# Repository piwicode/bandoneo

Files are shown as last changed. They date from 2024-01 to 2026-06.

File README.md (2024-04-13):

# Bandoneon MIDI

The goal of this DIY project is to build a
[bandoneaon](https://en.wikipedia.org/wiki/Bandoneon) MIDI keyboard with
velocity.

# First steps with the microcontroler

_2024/01/18_

Microcontroler development board are a huge time saver. Adafruit has a serie of
small form factor called [Feathers](https://www.adafruit.com/category/946)

These boards can be powered via USB or battery and utilize a voltage regulator
to maintain a 3.3V operation.

[Adafruit Feather M4 Express](https://learn.adafruit.com/adafruit-feather-m4-express-atsamd51)
is built around the
[ATSAMD51J19A](datasheets\SAM-D5x-E5x-Family-Data-Sheet-DS60001507.pdf). It look
like excellent choice because:

- it has plenty (21) input-output pins
- it runs at high clock speed of 120 MHz which will make possible
  [bitbang](https://en.wikipedia.org/wiki/Bit_banging) many analog-to-digital
  SPI busses at 3.6 MHz. I also have 32 floating point hardware.
- it has a single core which keeps the temptation to write concurent code away
- it does not have any extraneous wireless features.

The first thing to do it to check the bootloader version.

The bootloader, the initial program running on the processor, resides at the
start of the embedded flash, mapped at address `0x0` (See
`9.2 Physical Memory Map` and `25.6.2 Memory Organization`). Typically compact,
its role is to load and initiate the main program. In microcontrollers, it also
facilitates updating the main program.

Adafruit employs a
[fork of Microsoft UF2 bootloader](https://github.com/adafruit/uf2-samdx1),
which implements the Mass Storage Class. This means the board appears as a drive
when connected via USB. The term 'UF2' refers to a file format containing
instructions for rewriting device memory. The file format specifies a series of
memory addresses and the content to be written there. By following this process,
the program can be replaced by overwriting the memory, a straightforward method
requiring no extra hardware.

While both CircuitPython and Arduino workflows are well-documented, I will avoid
using CircuitPython to prevent the garbage collector from introducing jitter
into my time series sampling.

Thanks to Adafruit and Arduino's excellent work, the integration of drivers and
boards in the IDE is flawless. It took two attempts to flash the device, but now
the board's LED is blinking. Hello world!

# Emmiting Midi signals

_2024/01/19_

Musical Instrument Digital Interface, better known as MIDI, is a communication
protocol used for transmitting musical notes over a serial interface. These
notes are received by a synthesizer, which then produces the corresponding
waveforms.

There are two hardware solutions: 5 pin
[DIN connector](https://fr.wikipedia.org/wiki/Connecteur_DIN) or USB Midi.

## Midi via 5 pin DIN

The
[electrical specifications for the 5-pin DIN MIDI](datasheets\MCP3004-MCP3008-Data-Sheet-DS20001295.pdf),
reveal that it utilizes a UART serial bus along with power. Fortunately, most
modern microcontrollers now support UART.

Out of the five wires, only four are used: these are for Ground (GND), 3.3 volts
(3V3), UART receive (RX), and UART transmit (TX).

[UART (Universal Asynchronous Receiver-Transmitter)](https://en.wikipedia.org/wiki/Universal_asynchronous_receiver-transmitter)
is an efficient serial communication protocol that uses just two wires: TX
(transmit) and RX (receive). Without a dedicated clock signal, devices
synchronize based on the transmitted signal itself. To ensure reliable
communication, parity bits are also transmitted.

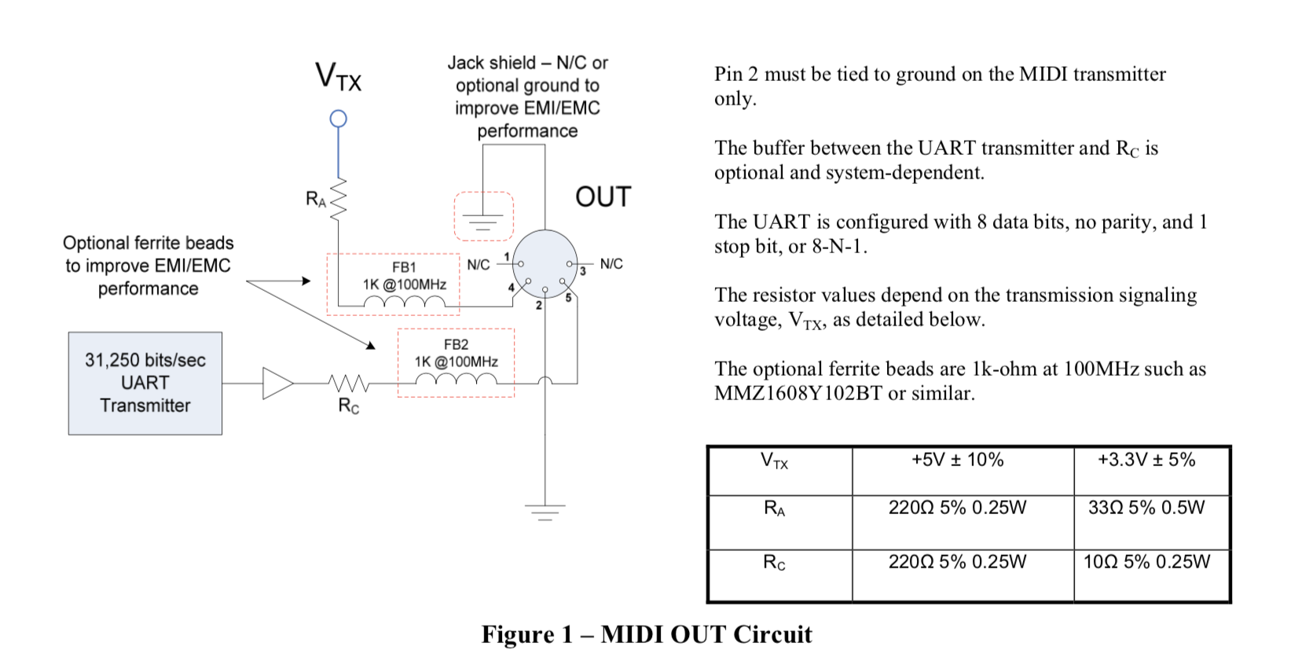
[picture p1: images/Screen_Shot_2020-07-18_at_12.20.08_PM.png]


The
[Arduino Midi library](https://github.com/FortySevenEffects/arduino_midi_library)
works instantly.

I used
[Adafruit's Midi Featherwing](https://learn.adafruit.com/adafruit-midi-featherwing)
for prototyping and it works like a charm.

## Midi via USB

In this setup, MIDI information travels through the same USB cable that is used
for power, programming, and retrieving logs from the board.

To enable MIDI via USB, you need to use
[TinyUSB](https://docs.tinyusb.org/en/latest/index.html), which can be selected
from the `Tools > USB` Stack menu in the `Arduino IDE`. By default, the USB
driver that is built with the program is ArduinoUSB. TinyUSB allows for the
support of additional protocols and enables the device to function as a MIDI
interface.

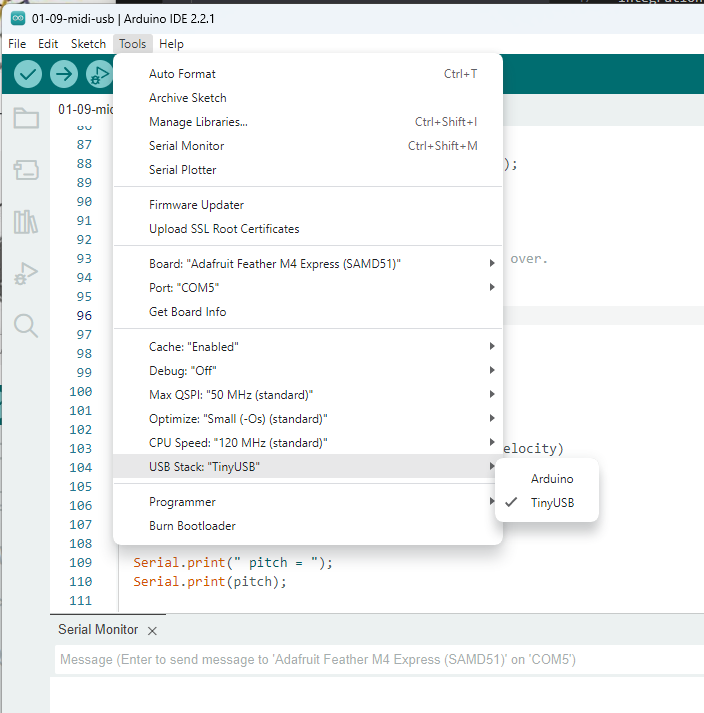
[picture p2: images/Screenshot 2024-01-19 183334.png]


The boards shows up as `Feather M4 Express` in my Digital Audio Workstation and
output midi notes.

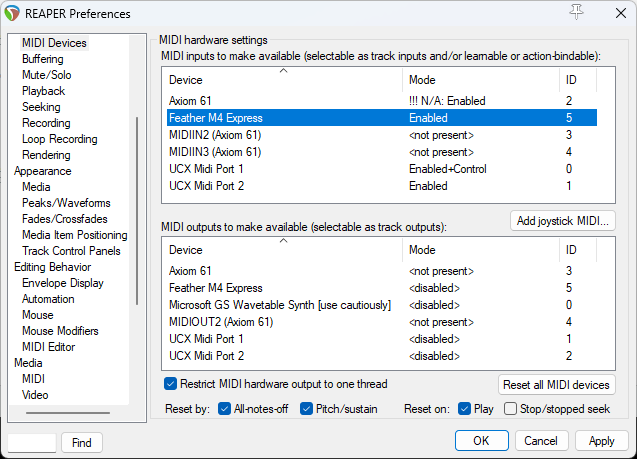
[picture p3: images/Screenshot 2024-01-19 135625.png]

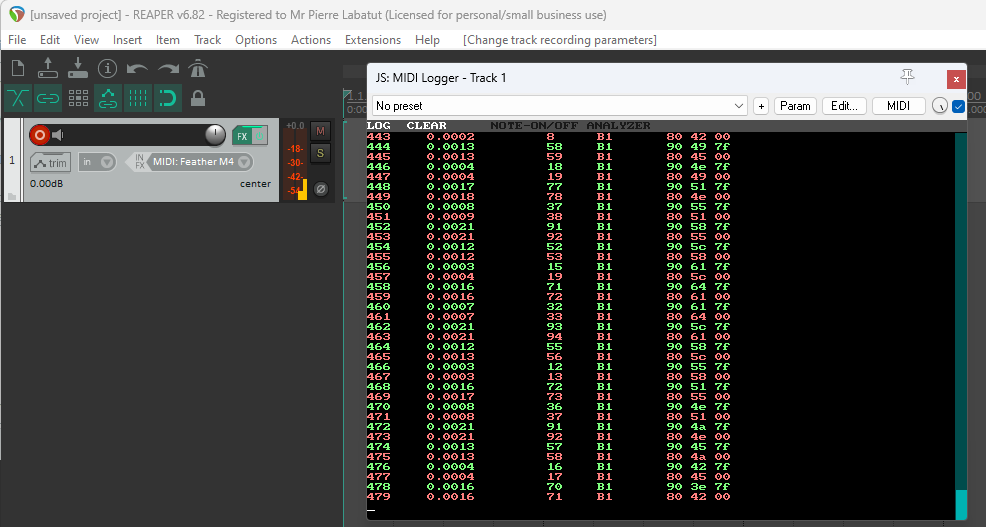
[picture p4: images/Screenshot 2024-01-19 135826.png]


Even with this setup, serial logging still works just fine.

# Talking to the Analog-Digital-Conveter

_2024/01/19_

Analog to Digital Converters, also known as ADCs, measure voltage from a pin and
convert it to numerical data for transmission over a serial bus. Those
components usualy have multiple input channels connected to a unique
[Successive-approximation ADC](https://en.wikipedia.org/wiki/Successive-approximation_ADC)
by a MUX.

I selected the [MCP3008](datasheets\MCP3004-MCP3008-Data-Sheet-DS20001295.pdf)
which looks popular. There is a
[tutorial available on Adafruit](https://learn.adafruit.com/reading-a-analog-in-and-controlling-audio-volume-with-the-raspberry-pi),
and the [midi_hammer](https://github.com/aleathwick/midi_hammer) project has
successfully integrated it with hall sensors to create a keyboard
([demo](https://youtu.be/tgWXtYCHDI4)).

The [MCP3008](datasheets\MCP3004-MCP3008-Data-Sheet-DS20001295.pdf) can measure
voltage from one of its eight inputs and then transmit the result via an SPI
(Serial Peripheral Interface) serial bus. Unlike UART, SPI includes an explicit
clock signal, which means it uses three wires, named:

- Clock
- MOSI (Master output slave input)
- MISO (Master input slave output)

A fourth pin `CS` (Chip Select), is used to activate or deactivate the
peripheral, effectively controlling when it can send or receive data.

The tutorial features Python code, but luckily, Adafruit also offers
[an Arduino library](https://github.com/adafruit/Adafruit_MCP3008), complete
with examples. All I need to do is set the number for the CS pin, and it works
seamlessly.

```c++
adc.begin(13);
```

Again, this is a huge time-saver.

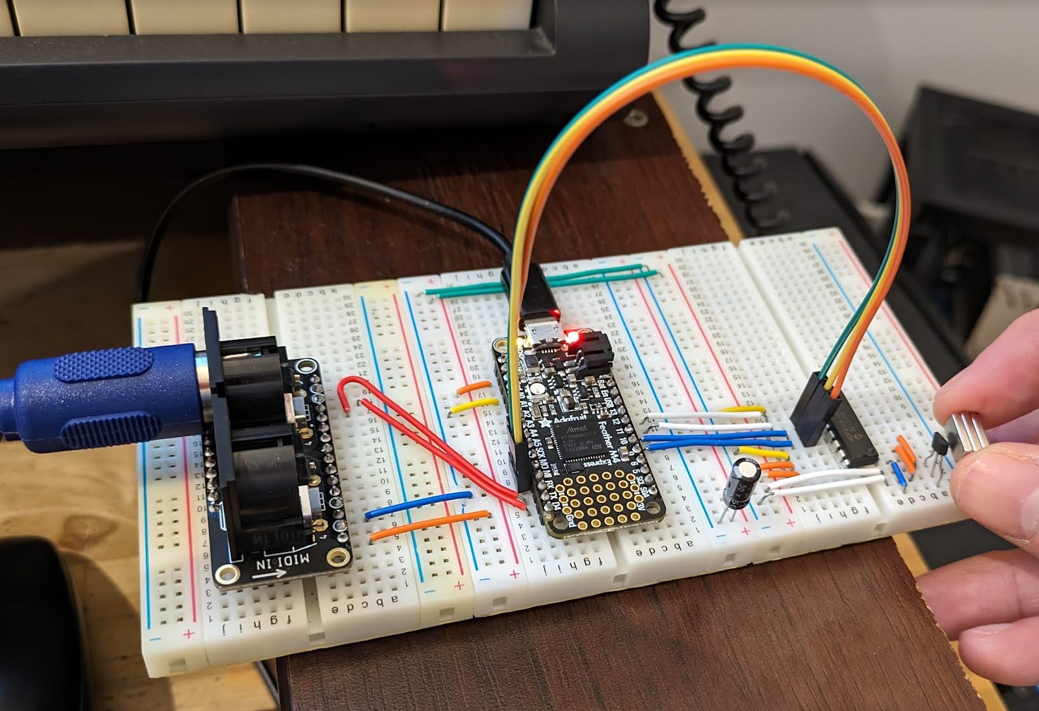
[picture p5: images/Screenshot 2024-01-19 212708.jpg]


I can read the 8 channels:

```
522	0	1023	1	1	0	0	0	[150]
522	0	1023	0	0	0	0	0	[151]
522	0	1023	2	1	0	0	1	[152]
522	0	1023	4	3	3	4	8	[153]
```

- The first channel shows the sensor output. In the absence of magnetic fields,
  it returns a mid-range value. Since the MCP3008 is a 10-bit converter, the
  maximum value is 1023, making 522 close to half of this.
- The second is grounded, and as expected, it reads 0.
- The third channel is connected to 3V3 and shows the maximum reading of 1023.
- When a magnet touches the sensor, the readings vary significantly: I can get a
  value of 788 and, interestingly, 254 when the magnet is rotated 180°.

Interestingly, the
[`Adafruit_MCP3008`](https://github.com/adafruit/Adafruit_MCP3008) library is
built on top of [`Adafruit_BusIO`](https://github.com/adafruit/Adafruit_BusIO)
which abstracts SPI communication. This is particularly useful because it can
implement a software bus, exactly what I need for reading from multiple
`MCP3008` units.

The
[library source code](https://github.com/adafruit/Adafruit_BusIO/blob/master/Adafruit_SPIDevice.cpp)
demonstrates how to modify multiple outputs of a given port by writing to the
register:

```c++
BusIO_PortReg *mosiPort = (BusIO_PortReg *)portOutputRegister(digitalPinToPort(mosipin));
BusIO_PortMask *mosiPinMask = digitalPinToBitMask(mosipin);

// Write
*mosiPort = *mosiPort | mosiPinMask;
```

This technique will be useful for reading measurements from multiple devices
simultaneously.

However, the approach to frequency control appears quite basic. It simply sleeps
according to the frequency period, without accounting for the time taken by
operations.

```c++
int bitdelay_us = (1000000 / _freq) / 2;
delayMicroseconds(bitdelay_us);
```

I configured the library to use
[bit banging](https://en.wikipedia.org/wiki/Bit_banging) for the bus by
specifying each pin:

```c++
 adc.begin(10, 12, 11, 13);
```

Remarkably, this setup worked perfectly on the first try.

It runs at `65300 sps` (samples per second), which is half of the specified
throughtput at 3.3 V.

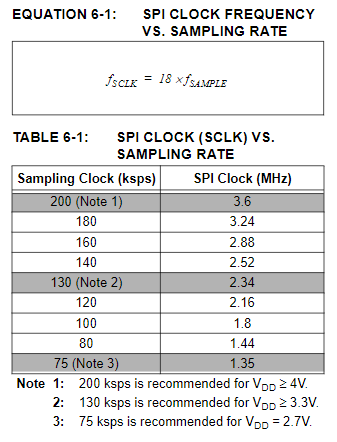
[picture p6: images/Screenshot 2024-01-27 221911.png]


# Bit-banging first step

_2024/01/21_

The source code below implements software SPI. It writes the content of `wbuf`
to the bus while simultaneously reading into `rbuf`. This approach is inspired
by Adafruit's implementation.

```c++
  template <unsigned int L>
  void transfer(const std::array<uint8_t, L> &wbuf,
                std::array<uint8_t, L> &rbuf) {
    // Only MSB first is supported.
    int r_idx = 0;
    for (const uint8_t wbyte : wbuf) {
      uint8_t rbyte;
      for (uint8_t bit = 0x80; bit != 0; bit >>= 1) {
        digitalWrite(mosi_, (wbyte & bit) != 0);
        digitalWrite(clk_, HIGH);
        delayMicroseconds(clk_period_us_);
        rbyte = (rbyte << 1) | digitalRead(miso_[i]);

        digitalWrite(clk_, LOW);
        delayMicroseconds(clk_period_us_);
      }
      rbuf[r_idx++] = rbyte[i];
    }
  }
```

The ADC protocol uses 17 bus clocks cycle to get a measure.

<table>
  <tr>
   <td>
   </td>
   <td><strong>Bits</strong>
   </td>
   <td><strong>MOSI</strong>
   </td>
   <td><strong>MISO</strong>
   </td>
  </tr>
  <tr>
   <td>Start bit
   </td>
   <td>1
   </td>
   <td>“1”
   </td>
   <td>don’t care
   </td>
  </tr>
  <tr>
   <td>Single / Diff
   </td>
   <td>1
   </td>
   <td>“1”
   </td>
   <td>don’t care
   </td>
  </tr>
  <tr>
   <td>Channel select
   </td>
   <td>3
   </td>
   <td>D0, D1, D2
   </td>
   <td>don’t care
   </td>
  </tr>
  <tr>
   <td>Sample Period
   </td>
   <td>1
   </td>
   <td>don’t care
   </td>
   <td>don’t care
   </td>
  </tr>
  <tr>
   <td>Null bit
   </td>
   <td>1
   </td>
   <td>don’t care
   </td>
   <td>“0”
   </td>
  </tr>
  <tr>
   <td>Sample
   </td>
   <td>10
   </td>
   <td>don’t care
   </td>
   <td>data
   </td>
  </tr>
</table>

Your analysis of the code's performance and potential improvements is
insightful. Here's a slightly restructured version for enhanced clarity and
conciseness:

This code currently runs at `11.48 ksps`` (kilosamples per second), which
translates to 87 μs (microseconds) per sample. However, there's room for
improvement. According to the MCP3008 datasheet, it can achieve up to 130 ksps
at 3.3V. Here are some potential optimization strategies:

- The most accurate delay function available is delayMicroseconds, but it limits
  the SPI bus to a maximum of 500 KHz. To reach the desired 120 ksps, a bus
  speed of 2.16 MHz is required.
- The current codes transmits 3 bytes (24 bit) per sample, wheras the minimal is
  17 bits, which is 30% more than needed.
- The existing delays don't account for the latency of operations between the
  delays, which adds to the total delay time.
- Using port registers to control output instead of digitalWrite could be more
  efficient.
- Adafruit has implemented a fast path for cases where the MOSI pin sends
  consecutive identical values. This bypasses
  `digitalWrite(mosi_, (wbyte & bit) != 0)`. Surprisingly, this optimization
  increases the rate to 12.65 ksps (79 μs per sample), an improvement of 10%,
  which makes me think `digitalWrite` is very slow.

# Precision counter on ATSAMD51J19A

_2023/01/21_

`ATSAMD51J19A`
[Arduino API implementation by Adafruit](https://github.com/adafruit/ArduinoCore-samd/blob/e2b78cbd3608fd5969d50c550a314db913a1a9e9/cores/arduino/delay.c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)
utilizes a hardware cycle counter `CYCCNT` of the `Data Watchpoint and Trace`
(DWT). This method is extremely precise, as the processor clock operates at 120
MHz. It's important to note that the processor clock frequency can be altered,
and the current frequency is accessible through `SystemCoreCloc`k.

```c++
void delayCycles(uint32_t count) {
  // This value takes into account the time spent in the function
  // itself. It has been determined experimentally by comparing the
  // delayCycles() function with the micro().
  constexpr uint32_t experimental_bias = 16;
  const uint32_t start = DWT->CYCCNT - experimental_bias;
  // The DWT->CYCCNT register is a 32 bits counter that counts the
  // number of cycles since the last reset. It is incremented every
  // cycle. It wraps around every 2^32 cycles (~37 secs at 120MHz).
  while (DWT->CYCCNT - start < count) {
  }
}
```

By replacing `delayMicros()` with `delayCycles()`, the sample rate has been
significantly improved to 23.7 ksps, which is an increase of +87%.

It seems that writing values to the port is time consuming. In a benchmark test
using the following code:

```c++
uint32_t start = micros();
for (int i = 0; i < 1000000; i++) {
  digitalWrite(12, HIGH);
  digitalWrite(13, HIGH);
  digitalWrite(12, LOW);
  digitalRead(13);
}
uint32_t end = micros();
// Display the cycle frequency.
Serial.print("Cycle frequency: ");
Serial.print(1000000.0 / (end - start));
Serial.println("MHz");
```

The results indicate a cycle frequency of 0.70 MHz when compiled with the
`-Ofast` optimization and 0.61 MHz with `-Os` (optimize for size). These
performance levels are insufficient for driving the bus at the desired speed of
2.16 MHz. However, controlling the GPIO directly via the port registers
demonstrates a much faster performance.

Direct control of the GPIO via port registers significantly boosts performance.
Consider this code snippet:

```c++
// Get port and mask from pin number.
auto reg = portOutputRegister(digitalPinToPort(12));
auto mask = digitalPinToBitMask(12);
uint32_t start = micros();
for (int i = 0; i < 1000000; i++) {
  *reg |= mask;
}
```

Running this code yields a frequency of 13.31 MHz when compiled with `-Ofast``.
As expected, a lower frequency of 3.64 MHz is observed for four register
updates.

By replacing `digital*` functions with direct pad manipulation, the sample rate
can be increased to an impressive 90.1 ksps. However, there's still room for
further improvement to reach our target.

# Optimize the IO manipulation further

_2024/01/22_

The operation `*ioreg |= mask;` involves reading, modifying, and then writing
back the result, which can be time-consuming. To address this, the
[`ATSAMD51J19A`](datasheets\SAM-D5x-E5x-Family-Data-Sheet-DS60001507.pdf)
features specialized registers that allow for setting or clearing pins directly
by writing a bitmask to them. This functionality significantly streamlines the
process.

To find the specific member names required, I had to delve into the code. On
Windows, this can be located in the following path:
`\Users\$USER\AppData\Local\Arduino15\packages\adafruit\tools\CMSIS-Atmel\1.2.2\CMSIS\Device\ATMEL\samd51\include\instance\port.h`.
This file is part of the CMSIS (Cortex Microcontroller Software Interface
Standard) package provided by Adafruit for the SAMD51 microcontroller.

For reference, in terms of performance:

- The function call digitalWrite(13, HIGH) consumes 41 cycles.
- Direct register manipulation with \*ioreg |= 0x800000 takes only 10 cycles.

Here is a verbose way to access `OUTSET`.

```c++
digitalPinToPort(13)->OUTSET.reg = digitalPinToBitMask(13);
```

This operation runs in 8 cycles. While it's slower compared to direct register
manipulation, this is mainly because the digital\* functions take additional
time to execute. However, these functions return a constant value, which offers
the possibility of caching for improved efficiency.

```c++
auto port = digitalPinToPort(13); // Once for all.

port->OUTSET.reg = 0x800000;
```

This method is significantly faster, completing the operation in just 3 cycles.

```c++
REG_PORT_OUTSET0 = 0x800000
```

This is the most straight forward, and it runs in 3 cycles, which is 3 times
faster than writing to the IO Register an 13 times faster than the
`digitalWrite`! . With this efficient method of controlling IO, the SPI bitbang
speed now reaches 105.96 ksps, which is quite close to the MCP3008 ADC's
specified limit of 120 ksps at 3.3V. However, we have yet to achieve the maximum
possible speed.

I should be able to squeze by rewriting the throttler. Without throttler the bus
runs at 186.96 ksps, and looks to return correct values.

Profiler code can be found
[here](src\arduino\01_18_blink_sodr_test\01_18_blink_sodr_test.ino)

# Optimizing further data write

_2024/01/23_

For the `clock` or `CS`, the code involves either clearing or setting a bit. In
contrast, the MOSI pin requires setting it to correspond with a specific bit of
the data. Here are several methods for handling the MOSI pin, by increasing
efficiency:

```c++
*(mosi_value ? &REG_PORT_OUTSET0 : &REG_PORT_OUTCLR0) = mosi_mask_;
// 6 cycles

REG_PORT_OUT0 = (REG_PORT_OUT0 & ~mosi_mask_) | (mosi_value << mosi_shift_);
// 15 cycles

*(&REG_PORT_OUTCLR0 + mosi_value) = mosi_mask
// 3 cycles
```

With this new method, we're beginning to observe that the code needs to be
throttled. Otherwise, the bus operates at a speed that exceeds the capabilities
of the `MCP3008`.

For the record I also considered
[bit-banding](https://developer.arm.com/documentation/ddi0439/b/Programmers-Model/Bit-banding),
but the featue is not available on the
[`ATSAMD51J19A`](datasheets\SAM-D5x-E5x-Family-Data-Sheet-DS60001507.pdf).

Target is 130 KSPS = 1/130e3/18 = 4.27350427E-7 = 427 ns

# Precise timing

Up until now, we've been handling time control with a simple busy loop. The
catch is that this method isn't super precise because each cycle includes
multiple instructions, and it can only wait for multiples of this cycle
duration.

To make things more accurate, we started using the `__NOP();` instruction. It's
like a little pause button for the processor, letting it wait for just one
cycle. But here's the kicker: getting the timing spot on with this method means
doing some manual tuning. You have to measure the timing precisely, which can be
a bit of a hassle.

One way to do this measurement is by keeping an eye on `DWT->CYCCNT`. But
remember, this approach can be a bit intrusive.

I ordered
[`AZ Delivey Logic Analyzer`](https://www.az-delivery.de/en/products/saleae-logic-analyzer).
It is an innexpensive device able to capture the binary state of 8 channels at
24 MHz, the data is then analyzed with
[Salae Logic](https://www.saleae.com/downloads/).

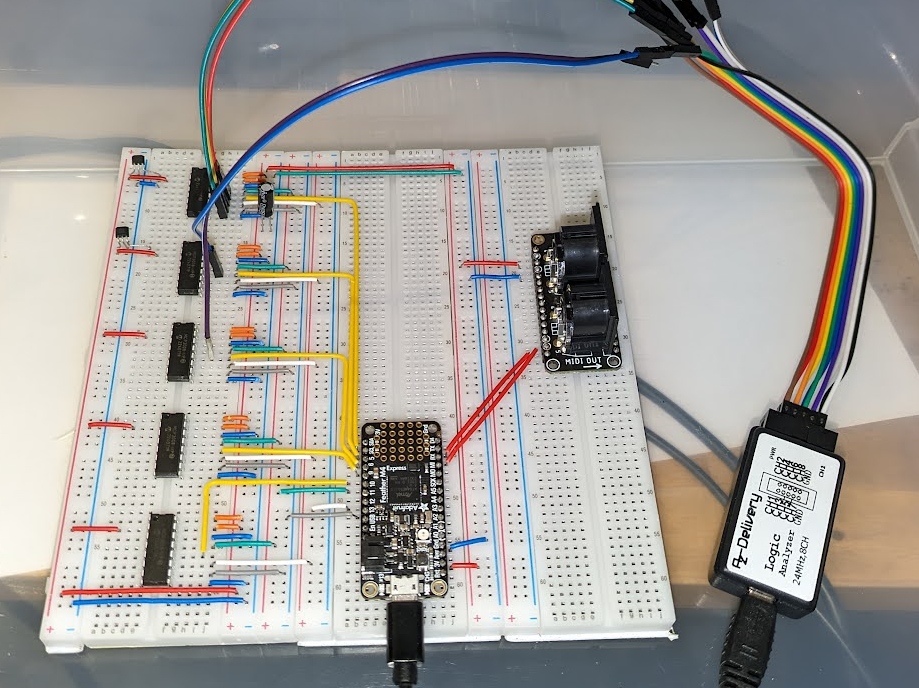
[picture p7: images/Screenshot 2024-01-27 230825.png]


That is a delight to use, the software decodes and displays the SPI data as
hexadecimal, and display precise cycle timings for the clock.

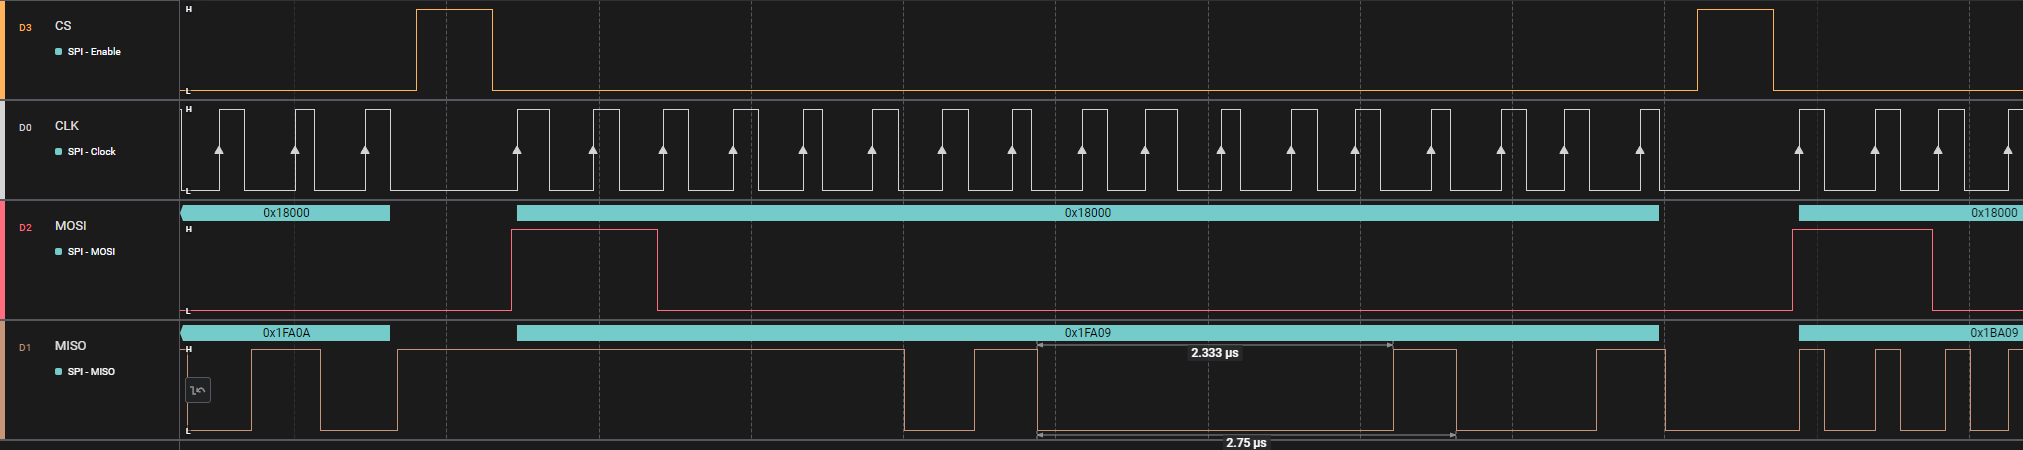
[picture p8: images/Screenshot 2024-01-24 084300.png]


After adding a few `__NOP();` instructions and dividing the unpacking of `MOSI`
into two parts, one before and one after clearing the `CLK`:

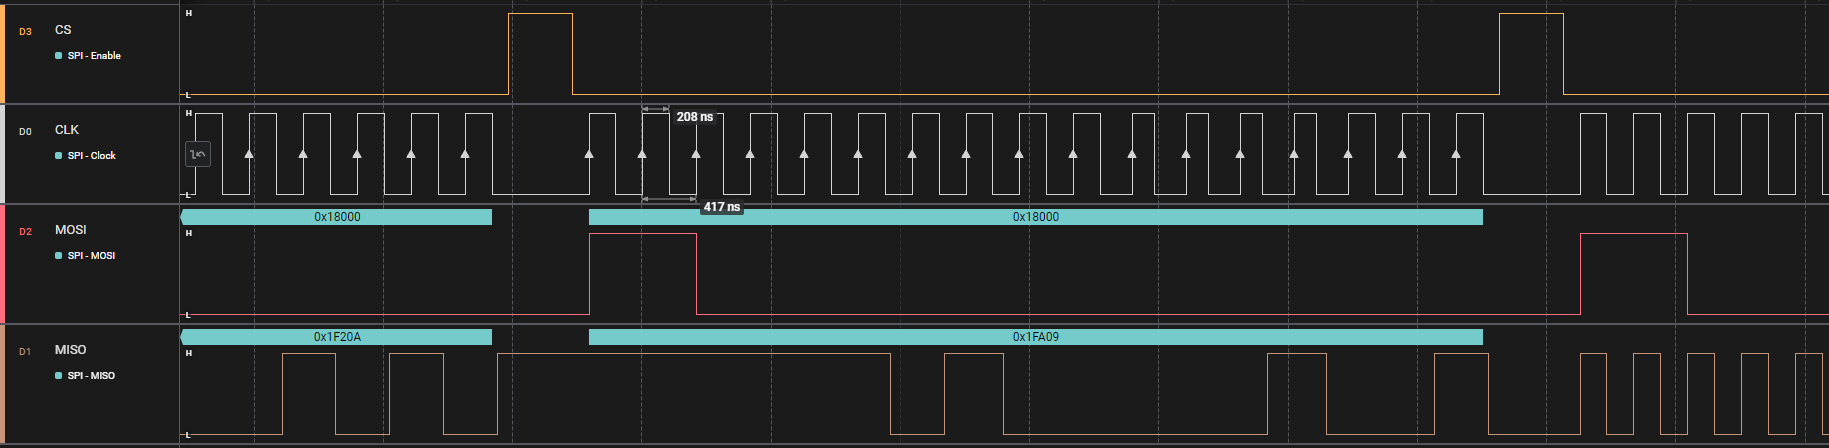
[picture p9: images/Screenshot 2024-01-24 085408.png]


The target is `130 KSPS = 1/130e3/18 = 4.27350427E-7 = 427 ns` is reached. Yay!

# Looking at the generated assembly

I was able to identify the compiler used by enabeling `verbose compiler output`
in `Arduino IDE` preferences:

```
$ Arduino15\packages\adafruit\tools\arm-none-eabi-gcc\9-2019q4/bin/arm-none-eabi-g++ --version
arm-none-eabi-g++ (GNU Tools for Arm Embedded Processors 9-2019-q4-major) 9.2.1 20191025 (release) [ARM/arm-9-branch revision 277599]
```

Looking at https://godbolt.org/ with compiler `ARM gcc 9.2.1 (none)` with
`-Ofast`.

Here is a
[decompiled code sample](https://godbolt.org/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).

We can see there that:

- `SPIArray::transfer` and `SPIArray::select` inlined.
- The loops that unpack the measures are unrolled:
  ```c++
    for (; i < N / 2; i++) {
      const bool bit = (in >> miso_shifts_[i]) & 0x1;
      rbuf[i] = (rbuf[i] << 1) | bit;
    }
  ```

It is tempting to make all the pin informations such as masks and shift part of
the template argument to turn load instructions into immediates, but oveall the
code is well optimized and run fast enough.

# Procesing samples

_2024/01/28_

I recorded the following samples at 2 KHz.
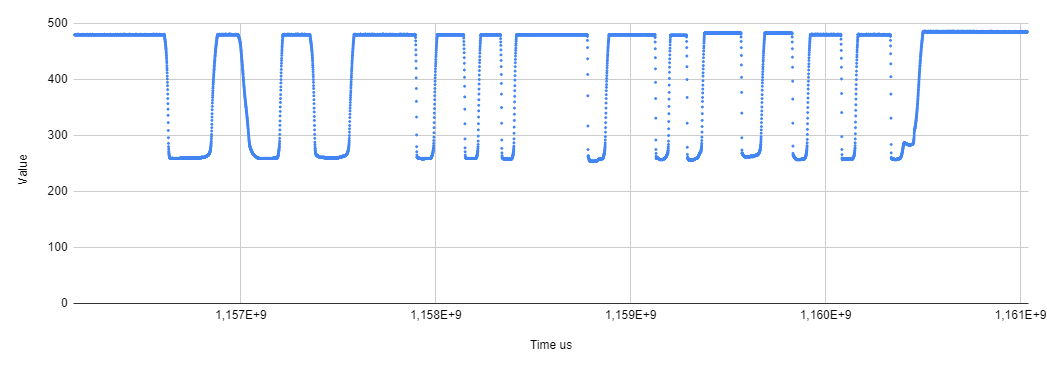
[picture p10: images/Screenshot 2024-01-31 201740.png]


We can see that when it is pressed vigorously, the switch travels in 3.8 ms.
Hence it is nice to be able to sustain a sample rate $>= 2 kHz$

Notes are considered pressed and released on a different threshold to avoid
repeated triggering. The velocity in $[1 .. 127]$ is compiled from a linear
mapping of the discrete time serie $(x_i, t_i)$.

When pressed slowly, the instant derivate
$\dot x_i =\dfrac{ x_i - x_{i-1}}{t_i - t_{i-1}}$ is not accurate because of the
combination of integer aliasing and high sample rated. Indeed, there can be
multiple consecutive identical values. We don't necessarily want to keep
previous sample in memory. To workaround this issue I filter the derivative with
a geometrical decreasing weights based of factor $q$:

$$
\dot x_i = \begin{cases}
0 & \text{for } i = -1 \\
( 1 - q )\dot x_{i-1} + q  \dfrac{ x_i - x_{i-1}}{t_i - t_{i-1}} & \text{with } q \in [0, 1] \end{cases}
$$

- With $q = 1$ this is the instant derivate.

- With $q < 1$ it takes into account the past samples by anoly accessing the
  previous sample and the previous derivate.

# Keyboard switches

_2024/01/31_

I plan to use [Wooting 60 gf](https://wooting.io/product/lekker-switch-linear60)
Hall keyboard switches, with 3d printed caps.

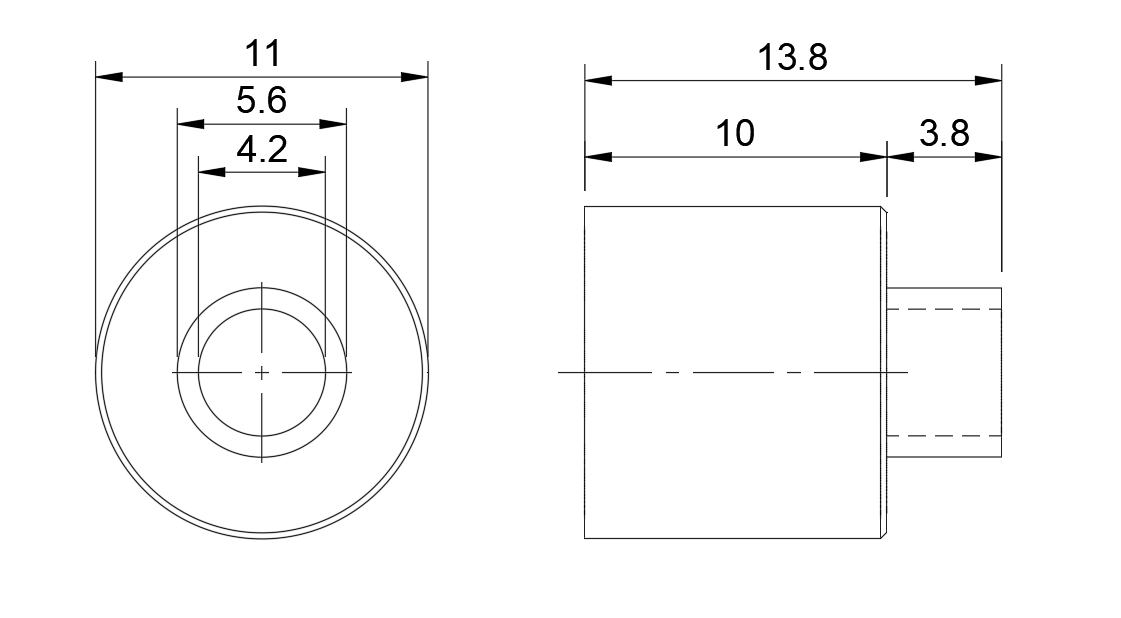
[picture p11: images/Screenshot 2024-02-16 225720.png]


# ADC source impedence

The ADCs use a capacitor to sample the voltage and employ a dichotomy method to
test various voltages in order to determine the measurement value. The input is
characterised by a resistance and a capacity. The source impedence should be low
enough for the capacity to charge during the sampling period.

- [`MCP3008`](datasheets\MCP3004-MCP3008-Data-Sheet-DS20001295.pdf) input
  impedance 1 kΩ, capacity 20pf.
- [`ATSAMD51J19A`](datasheets\SAM-D5x-E5x-Family-Data-Sheet-DS60001507.pdf)
  input impedance 2kΩ, capacity 3pf

Texas instruments provides a technical document on
[ADC Source Impedance](https://www.ti.com/lit/an/spna061/spna061.pdf).

It shows what the input in voltage would look like if the source impedence is to
high.

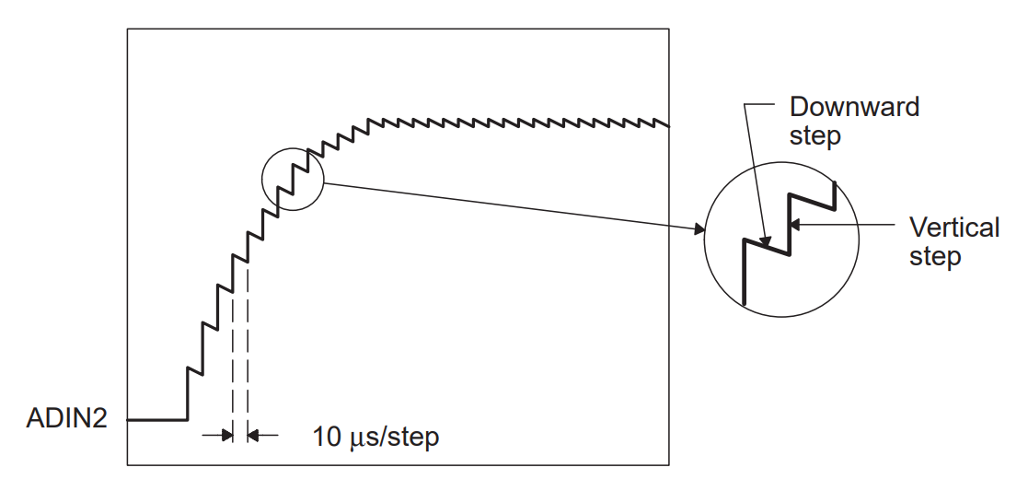
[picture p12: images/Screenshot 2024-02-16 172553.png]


# First pinted assembly attempts

I printed caps with inner diameter of $4.2mm$ and $4.5mm$ on an Ultimaker MK3
Extended with AA 0.4 headers and transparent PLA. The fist dimension resulted in
a nice and tight adjustment, and the second was too lose.

As second attempt to print a batch of 12 caps with inner diameter of $4.2mm$
resulted in many learning:

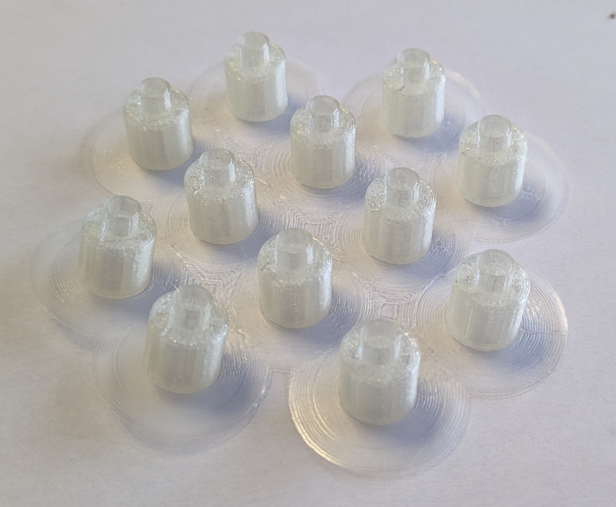
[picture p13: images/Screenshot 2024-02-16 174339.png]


- When printed in batch the seams are not very clean. Stop using batch or ensure
  cura
  [print them one at a time](https://all3dp.com/2/cura-print-one-at-a-time-explained/)
  which will require the part to be smaller than the gantry height ($60mm$) and
  to set the number of extruders to 1 in the printers's settings. I should be
  able to print 9 caps per batch.
- This time the adjustement with the switch is too lose. This is confirmed by
  measurement with a caliper, the outer diameter of $5.6mm$, which is $.1mm$
  larger than the previous print with the same inner inner. I should reduce the
  inner diameter to $4.1mm$.
- Assuming I stick to the .4 header, I should try a thicker sleeve by increasing
  the outer diameter from $5.6mm$ to $4.1+.04 * 2 * 2 = 5.7mm$
- The sleve is slightly too short and should be extended by $.1mm$
- It is unconvenient to remove the brims, and I should switch to skirts.

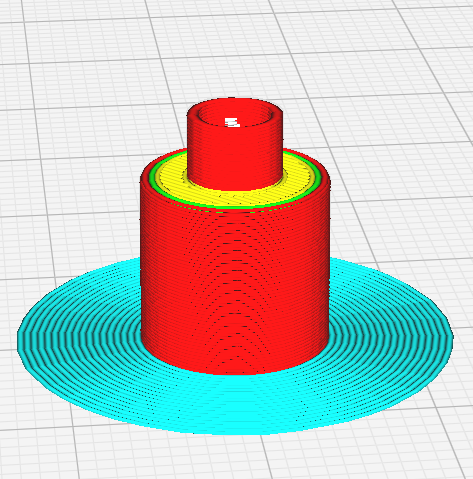
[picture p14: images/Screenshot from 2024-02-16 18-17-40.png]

→
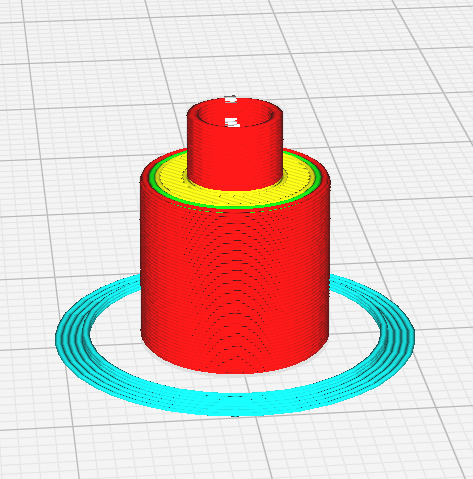
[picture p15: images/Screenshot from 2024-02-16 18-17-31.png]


- The triangular infill looks like a radioactive symbol «☢» and Line, Concentric
  or Gyroid should be prefered.
- Once assembled the caps elevates at $11mm$, versus $9mm$ to $10mm$ for the
  original instrument.

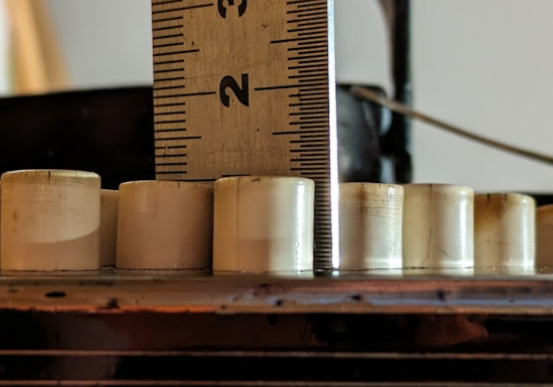
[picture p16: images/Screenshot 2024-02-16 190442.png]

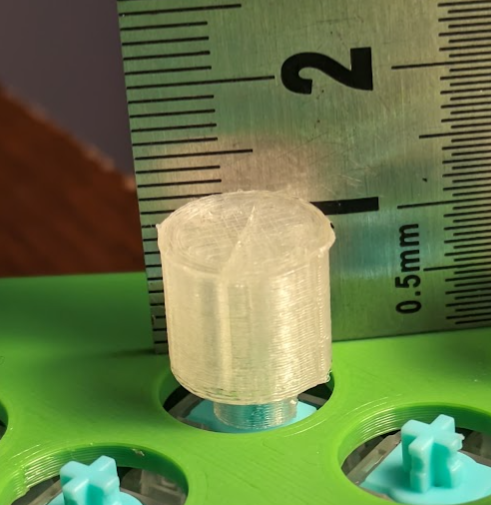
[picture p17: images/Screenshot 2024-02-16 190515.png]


The new button has a long sleeve of $6mm$ which is $.04mm$ more than the measure
from the surface of the keyboard and the pressed pushbutton.

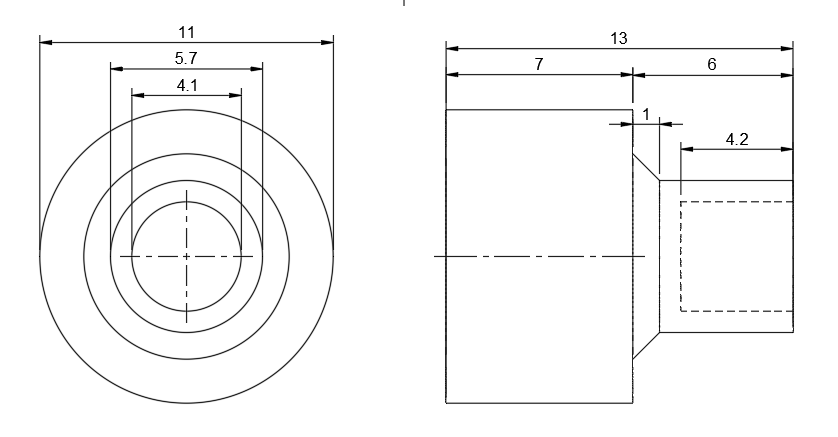
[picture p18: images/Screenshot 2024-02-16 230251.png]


# New prototype

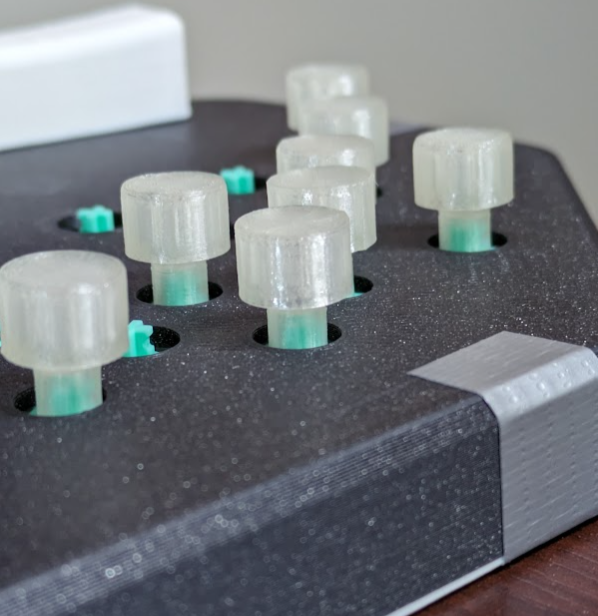
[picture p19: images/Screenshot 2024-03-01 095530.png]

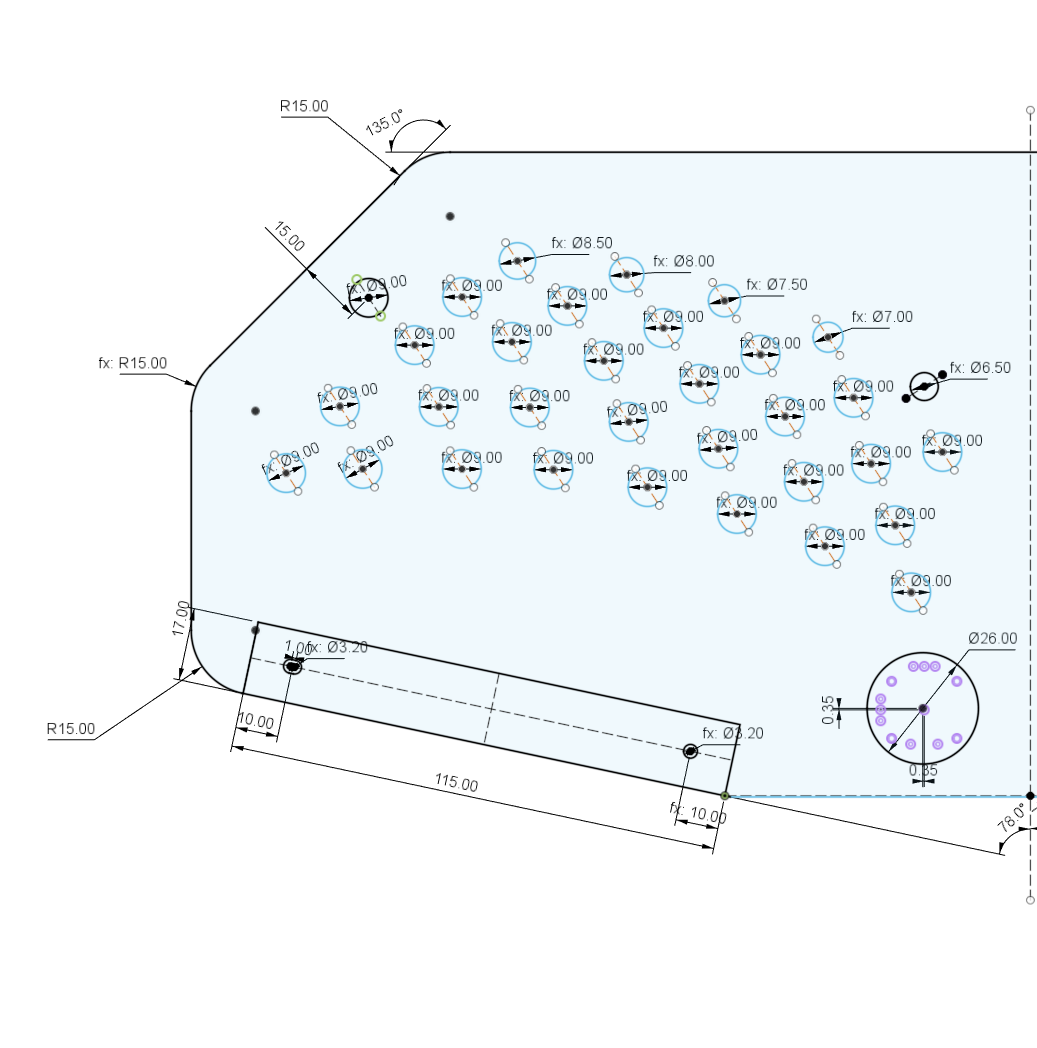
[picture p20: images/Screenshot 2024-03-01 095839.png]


- Caps:
  - The new caps are to tight. Try an inner diameter of $4.15mm$
  - They are also too tall. Set the total height to $11mm$
- Joystick:
  - It is well adjusted but offcentered bt 1mm South-East
  - It is 1cm too far from the handle
- Touches holes
  - The switches are still moving because the carter is a bit flexible. I need
    to add a stifener web to the top.
  - When applying pressure holes above $⌀7.5$ are large engough to avoid
    contact. Every hole below $⌀7$ and uncomfortable. $⌀8$ should be a good
    compromise.

# Resistive touch screen

I considered to use a resistive screen ([Datasheet](datasheets\P333+datasheet+TP035W4L2.pdf) to send MIDI control signals. This works well but takes too much space and the intrgration with the 3D printed case would require to much work. I decided to remove it.

- Article [source](https://cdn-shop.adafruit.com/datasheets/AVR341.pdf)

Pins are X- Y+ X+ Y- https://www.adafruit.com/product/3575

# PCB & Model

You can view the kicad board on
[Kicanvas online viewer](https://kicanvas.org/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).

MCP3008-I/SL
[jclpcb](https://jlcpcb.com/partdetail/MicrochipTech-MCP3008_ISL/C1520159)

The enclosure design can be
[seen here](https://gmail319357.autodesk360.com/shares/public/SHd38bfQT1fb47330c99409055e022d399e6).

# 3D printing

I printed the model with PLA on Prusa mk4, and inserted M3 bolts.

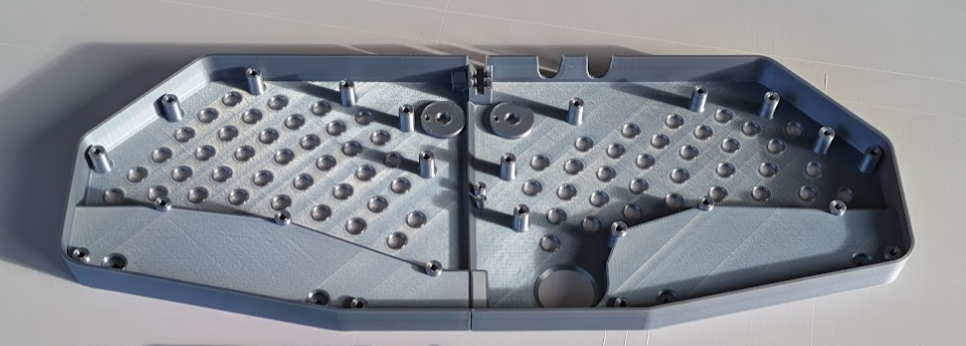
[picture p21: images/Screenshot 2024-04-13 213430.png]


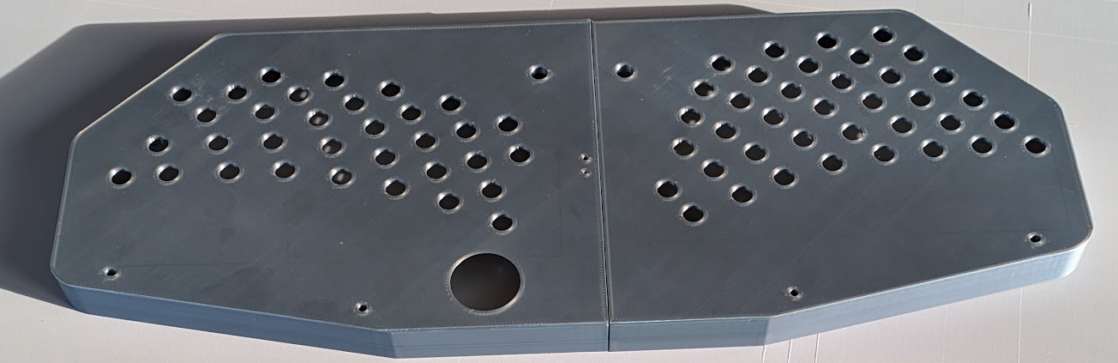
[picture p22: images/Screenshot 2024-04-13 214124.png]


I also printed the PCB model to validate the component footprints and the assebly:

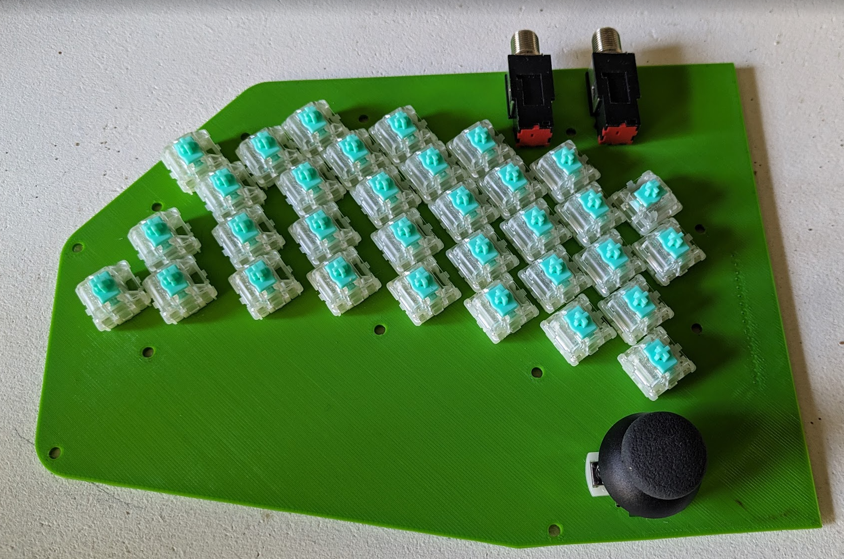
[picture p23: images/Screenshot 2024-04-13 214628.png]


Assembly is done with 23 x M3 screws with flat heads, and brass bolts:



# Electrostatic discharge protection

I added pretection to the two jacks inputs, the potentiometer and the USB
voltage input. The TVS diodes uni / bidirectional naming was confusing until I
read [this document](https://www.mouser.com/pdfdocs/AND8424-D.PDF).

I selected [SRV05-4](http://www.onsemi.com/pub/Collateral/SRV05-4-D.PDF)
packages.

# Adding an expression pedal M-Audio EX-P

Expression pedals wiring is not standatd. I measured the resistance between the
tip rig and sleeve on the innexpensive M-Audio EX-P. This pedal has a
configuration switch and a potentiometer.

- Switch mode set to "M-AUDIO":
  - Potentiometer set to min: R<->S [11.1kΩ, 11.1kΩ], T<->S: [0.9kΩ, 12.1kΩ],
    R<->T: [12.1kΩ, 0.9kΩ]
  - Potentiometer set to max: R<->S [63.3kΩ, 63.3kΩ], T<->S: [52.14kΩ, 62.8kΩ],
    R<->T: [12.1kΩ, 0.9kΩ]
- Switch set to "Other":

  - Potentiometer set to min: T<->S [11.1kΩ, 11.1kΩ], R<->S: [0.9kΩ, 12.1kΩ],
    R<->T: [12.1kΩ, 0.9kΩ]
  - Potentiometer set to max: T<->S [63.3kΩ, 63.3kΩ], R<->S: [52.14kΩ, 62.8kΩ],
    R<->T: [12.1kΩ, 0.9kΩ]

  The behavior between the tip and the ring is not affected bu the potentiometer
  and the switch, which is convenient to avoid missuses.

# Production

I ordered 2 assembled PCB on JCLPCB. Exporting the production files was
reasonably easy using the tutorials. I had to add the `LCSC Part` numbers to the
schematic and to export the bom with custom scripts.

The the pick and place file, JCLPCB assumes that 0 degree is the posiition of
the part on a reel tape with the punctures on the left. This was not the case
for my footprint. I wrote a script to postprocess the components orientation.

# What to improve

- Use pcb mounted potentimeter: simpler to assemble and to test.
- Use pcb mounted tactile button for the tow unused pins
- Have the sensonrs and ADC run with 5V for better sensitivity of the hall
  sersors.

# Related project

- Inside a bandoneon [video 1](https://www.youtube.com/watch?v=u1KrLr4cBY0),
  [2](https://www.youtube.com/watch?v=JJk-qPO4OpM)
- Bandoneón MIDI [video](https://www.youtube.com/watch?v=HgcwFOrgt_w),
  [site](https://hackaday.io/project/170753-bandomidi)
- bandominedoni [video](https://www.youtube.com/watch?v=WzOsrSpjDgU),
  [github](https://github.com/3araht/bandominedoni)
- Bandonberry [github](https://github.com/jebentancour/Bandonberry)

# Further readings

- JS Application to learn the bandoneon layout
  https://github.com/nicokaiser/bandoneon
- [Hall effect keyboard listing](https://www.hlplanet.com/keyboards-hall-effect-switches)
- Lekker keyboard [design note](https://
  .io/post/validation-tests-lekker-update-8) and
  [teardown video](https://www.youtube.com/watch?v=LpKBC1tWXws).

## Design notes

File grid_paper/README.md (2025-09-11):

This files prints 5mm spaced grid paper.

Usage:

```
lpr -o raw -P <<your printer>> grid_paper/grid.ps 
```

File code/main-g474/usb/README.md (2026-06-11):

# USB stack (TinyUSB)

The main board enumerates as a full-speed MIDI USB device built on
[TinyUSB](../../third_party/tinyusb) (git submodule, `code/third_party/tinyusb`):

| | |
|---|---|
| VID / PID | `0xCafe` / `0x4001` (TinyUSB convention: `0x4000 \| interface bitmap`) |
| Manufacturer | L'Atelier du bandonéon libre |
| Product | Bandoneo |
| Serial | 96-bit chip UID, 24 hex digits |
| Interfaces | MIDI only |

## Files

- `tusb_config.h` — TinyUSB feature configuration (device-only, CDC + MIDI).
- `usb_descriptors.c` — device/configuration/string descriptors. Strings are
  UTF-8 and converted to UTF-16 on the fly, so accented names work.
- `usb_app.c/.h` — glue: `usb_app_init()` starts the stack (called from
  `main()` after `MX_USB_PCD_Init()`), `usb_app_task()` runs `tud_task()` from
  the main loop, and the three USB IRQ handlers (which override the weak
  symbols in `startup_stm32g474xx.s`).

The TinyUSB sources, include paths, and the `CFG_TUSB_MCU=OPT_MCU_STM32G4`
define are listed in the user sections of [CMakeLists.txt](../CMakeLists.txt).

## How it coexists with CubeMX

CubeMX still generates `MX_USB_PCD_Init()` (HAL PCD), which enables the USB
peripheral clock via `HAL_PCD_MspInit()`. TinyUSB's `dcd_init()` then resets
and takes over the peripheral; `HAL_PCD_Start()` is never called, so the HAL
never enables the DP pull-up or the USB interrupts itself. Don't remove the
USB peripheral from the `.ioc`.

**USB clock**: the board is crystal-less, so the `.ioc` selects HSI48 as USB
kernel clock, trimmed by the CRS against USB SOF (the PLL alternative is fed
by HSI16, ±1%, outside the USB FS ±0.25% budget). All of this lives in the
generated `SystemClock_Config()`. These `.ioc` invariants — HSI48 + CRS, USB
device FS enabled, USB interrupts *not* enabled in the NVIC tab (TinyUSB owns
the handlers) — are checked by `code/tests/test_usb_config.py` (`just test`
from `code/tests`).

## Testing

```sh
lsusb -d cafe:4001       # device present
amidi -l                 # MIDI port listed as "Bandoneo"
aseqdump -p Bandoneo &   # then run `midi [note]` in the console to test
```

The `midi [note]` console command (via USART1/ST-Link) sends a note-on/note-off
pair (default 69 = A4) for end-to-end checking over USB MIDI.

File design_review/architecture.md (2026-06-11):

# Architecture

## Motherboard MCU Selection

With wireless dropped (see [requirements.md](requirements.md)), the motherboard only needs:

- USB-FS device controller (USB-MIDI),
- Two independent SPI slave receivers — one full-duplex bus per wing, each with its own NSS input,
- 2× ADC channels for the spring-blade push/pull hall sensors (see [hardware.md](hardware.md) §"Push/Pull Sensor"),
- 2× ADC channels for the expression and sustain pedals,
- ~20 GPIOs for status LEDs, presence-sense contacts, function buttons, and the hall-bank power gate.

The **STM32G474CBT6** (LQFP48) is the choice — and the same part runs on both wings:

- **Single SKU across all three boards.** One toolchain, one flash procedure, one decoupling pattern (documented in [hardware.md](hardware.md)) for motherboard and both wings. Consolidating to a single STM32 part across the three boards removes a class of bring-up and supply risk.
- **Crystal-less USB-FS device.** G474 uses HSI48 with the Clock Recovery System (CRS), so USB enumerates without an external HSE crystal — fewer parts, smaller layout, no crystal-load-cap tuning. There is no external PHY and no companion MCU.
- **Two independent SPI peripherals.** SPI1 and SPI2 operate as slaves, one per wing; no shared-bus arbitration, no NSS-tristate gymnastics — see "Internal Bus" below.
- **Headroom.** Cortex-M4F at 170 MHz with 128 KB flash / 128 KB RAM is comfortably over-spec for the USB-MIDI workload, leaving margin for future on-device processing (note-on smoothing, gesture recognition, expression curves).
- **No RF, no antenna, no module certification.** Wireless is out (see [requirements.md](requirements.md)), so no module premium is paid.

Trade-off: STM32G474 is an *extended* part on JLCPCB rather than basic, so it carries a small per-board surcharge — accepted in exchange for the single-SKU simplification across all three boards. A G431 would be basic-part and slightly cheaper, but at the cost of running a different MCU than the wings.

## Internal Bus: Motherboard to Wing Boards

Each wing board connects to the motherboard over its **own dedicated full-duplex SPI bus** — one SPI peripheral per wing on the motherboard (SPI1 → left wing, SPI2 → right wing). The two buses are electrically independent: no shared SCK/MOSI/MISO, no bus arbitration. The connector (**S062100026, 2×6, 1.27 mm pitch, SMD vertical**) carries 12 wires:

| Pin | Net | Direction |
|---|---|---|
| 1  | VCC (3.3 V from motherboard) | main → wing |
| 2  | READY | wing → main |
| 3  | SPI_NSS | wing → main (master-driven chip select) |
| 4  | NRST | main → wing (open-drain via BAT54C) |
| 5  | SPI_SCK | wing → main (master-driven clock) |
| 6  | GND | — |
| 7  | SPI_MISO | main → wing (slave response, if needed) |
| 8  | GND | — |
| 9  | SPI_MOSI | wing → main (master data out, sensor frame) |
| 10 | GND | — |
| 11 | BOOT0 | main → wing |
| 12 | VCC (second power return) | main → wing |

Three GND returns (pins 6, 8, 10) interleaved with signals; two VCC pins (1 and 12) share the power load across both rows of the connector.

- **NRST** is driven open-drain from the motherboard through a BAT54C to 3.3 V; the wing's internal NRST pull-up provides idle-high.
- **READY** is driven actively high by the wing once its MCU has initialised; the motherboard configures its READY pin as input with internal pull-down so that, if a wing is absent or still booting, the line resolves to "not ready" without anyone sourcing current into the wing.
- **BOOT0** (pin 11) is driven by the motherboard MCU (PA3 → left wing via CN2-11, PB13 → right wing via CN1-11). By asserting BOOT0 high while cycling NRST, the motherboard can force a wing into the STM32G474 system bootloader — enabling in-system firmware updates of either wing over USB without physical button access. See [hardware.md](hardware.md) §"Remote Wing Programming via BOOT0".

Each SPI transaction carries a wing identification code, a complete raw keyboard state frame, and a checksum. The wing ID encodes the keyboard layout (e.g. Rheinische Lage, Einheitsgriff), so the motherboard applies the correct key-to-note mapping at runtime — the same firmware supports multiple layouts without recompilation.

**Wing is master, motherboard is slave.** Each wing drives its own SPI bus and initiates transactions at 1 kHz:

- Wing master → motherboard slave: `1 × 16 bits` — board identifier (wing layout code) + `40 × 16 bits` — sensor sample values + `1 × 16 bits` — CRC-16 checksum

40 sample slots match the largest wing (WingRight, 5 × 74HC4052 × 8 = 40 channels; WingLeft uses 32 and pads the rest). 1 kHz polling → **(1 + 40 + 1) × 16 bits = 832 bits per frame → 832 kbit/s per bus**, well under the STM32G474 SPI ceiling (85 MBits/s maximum). Because each wing has its own dedicated bus and SPI peripheral, the two wings transmit concurrently rather than serialised. The motherboard remains passive and synchronized by the wings' clock, receiving sensor data pushed at the wings' scan rate.

**SPI Slave NSS Configuration:** The motherboard's SPI1 and SPI2 NSS pins (PA4, PF0) are configured as **hard input with internal pull-up**. The pull-up ensures NSS idles HIGH (not selected) even if the wing master is not yet initialized or loses power. This prevents floating NSS during wing boot from being misinterpreted as an accidental low (selected) state. The wing master actively drives NSS both low (during transaction) and high (idle), so the pull-up provides a defensive safety margin without creating contention.

## System Power

The motherboard is bus-powered from the USB VBUS pin (5 V, ≤ 500 mA at the instrument — well within the USB 2.0 default budget). There is no internal battery, no charger IC, no ship mode, no charge mode: when the cable is plugged the instrument runs, when it is unplugged the instrument is off. Auto-power-off and battery-preservation logic are no longer relevant.

| State | Power source | Boards powered | MCU activity |
|---|---|---|---|
| **Powered** | USB VBUS | All | Full operation |
| **Unpowered** | — | None | Off |

The on-board 3.3 V LDO is fed directly from VBUS through the USB ESD/OVP front-end (see [hardware.md](hardware.md)). The USB connector is **Type-B** (USB1, right-angle SMD) — chosen for mechanical robustness and cable retention on stage; see [hardware.md](hardware.md) §"USB Connector Choice". The wings are powered directly from the motherboard's 3.3 V rail through their respective connectors; there is no per-wing power switch, no gated wing rail, and no SPI back-feed buffer. With the battery removed there is no runtime motivation to cut wings independently of the motherboard — if VBUS is present the whole instrument is powered, if VBUS is gone everything is off.

## Programming Port

Each board (motherboard and both wing boards) exposes **14 bare pogo-pin landing pads** laid out per the **STDC14** pinout — no connector body on the BOM. The mating tool is a **Tag-Connect TC2070-IDC-050** spring-loaded pogo jig pressed against the pads during programming or debug. The jig is a workshop tool, not a BOM component.

STDC14 carries the full debug interface: SWD (SWDIO/SWCLK), SWO trace, NRST, UART VCP (TX/RX), target VCC reference, and several GND returns — everything needed for flashing, halting, real-time tracing, and serial console without falling back to test points.

**Why STDC14, not the legacy 20-pin Cortex headers.** STDC14 is ST's modern compact debug standard and is the native footprint of the STLINK-V3 family. It packs the same SWD + SWO + VCP signals into a much smaller area, which is the deciding factor for these boards.

**Why ST-Link, not J-Link.** Segger's affordable J-Link variants (EDU, EDU Mini) are licensed for **non-commercial use only**; the cheapest commercially-licensed J-Link is roughly an order of magnitude more expensive. ST-Link probes — in particular the STLINK-V3 series, which exposes STDC14 directly — are inexpensive, commercially licensable out of the box, and natively supported by the STM32 toolchain used on every board in this project.

## ESD Protection

All external-facing ports (USB, internal bus, programming ports, pedal inputs) are protected with a TVS diode array placed close to the connector, before any MCU pin or active device.

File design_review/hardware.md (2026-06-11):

## ESD and VBUS Protection

The instrument is bus-powered from USB VBUS at the standard 5 V (USB 2.0) — no PD voltage negotiation is performed, no battery, no buck/charger on the input. The connector type is a separate mechanical decision; the electrical front end below works with any USB 2.0 receptacle. This simplifies the protection considerably:

- **VBUS TVS:** an `SMF5.0A` (SOD-123FL, unidirectional, 200 W peak) clamps transient surges to ≈ 9.2 V, well below the downstream LDO's absolute-max input. Reverse standoff 5 V matches the only operating voltage VBUS will see; a misbehaving source pushing higher voltage is clamped, not propagated to the LDO.
- **No polyfuse / eFuse on VBUS:** deliberately not fitted. The USB 2.0 host port is already required by spec to limit current to 500 mA; the SMF5.0A TVS clamps transient surges; and the TLV755P has internal foldback + thermal shutdown. A polyfuse would be an JLCPCB extended part with no matching basic-part substitute. The combination of host OCP + TVS + LDO self-protection is judged sufficient for v1.
- **D+ / D− ESD:** SRV05-4 (TV8) with pin 5 (V+) tied to **VBUS (5 V)**. Since no PD negotiation is performed, VBUS is always standard USB 2.0 5 V — the only voltage this pin will ever see. Tying V+ to VBUS is the correct usage: it activates both the upper and lower steering diodes, giving full bidirectional clamping on D+/D−. ESD charge steered upward disperses into the host's source impedance; the SMF5.0A is there to clamp any transient that reaches VBUS. Floating pin 5 would disable the upper diodes and halve clamping effectiveness.

## Power Consumption

Estimated from the BOMs in [export/](export/) at the 3.3 V rail, with typical datasheet values at room temperature. Hall sensor count: **33 (WingLeft) + 38 (WingRight) = 71** key-position sensors, plus **2 on the motherboard** for push/pull sensing — **73 total, all gated**.

**Hall sensor power gating.** Each board carries one AO3401A P-channel MOSFET (Q1) whose drain feeds a switched `VDDH` rail. The MCU drives the gate, enabling `VDDH` only during each scan window:

- **Wings**: 33 / 38 SC4015 sensors per board, scanned via 4 / 5 × 74HC4052 muxes at 1 kHz. Window ≈ ~40 channels × ~6 µs settle+convert = **~240 µs ON / 1 000 µs period ≈ 25 % duty cycle**.
- **Motherboard**: 2 SC4015 sensors for push/pull, gated by the same Q1 topology but sampled at the push/pull rate (a few hundred Hz at most — mechanical bandwidth). Duty cycle is dominated by the wings' loop, so the motherboard's 2 sensors run at **≤ 25 %** in the worst case where main schedules them inside the same window.

The SC4015 datasheet T<sub>PO</sub> ≤ 0.8 µs makes the start-up overhead negligible against the sweep window.

| Block | Part | Qty | I typ (mA) | Duty | Subtotal avg (mA) |
|---|---|---:|---:|---:|---:|
| Main MCU @ 170 MHz | STM32G474CBT6 | 1 | ~30 | 100 % | 30 |
| Wing MCU @ 170 MHz | STM32G474CBT6 | 2 | ~30 | 100 % | 60 |
| Key Hall (gated via wing AO3401A) | SC4015 | 71 | 2.5 | 25 % | ~44 |
| Push/pull Hall (gated via main AO3401A) | SC4015 | 2 | 2.5 | ≤ 25 % | ≤ 1.3 |
| Analog mux (static) | 74HC4052 | 9 | <0.01 | 100 % | ~0 |
| LEDs (POW + ~3 status) | — | ~4 | 3 | — | ~10 |
| LDO I<sub>Q</sub> + leakage | TLV755P + misc | — | — | — | ~1 |
| **Total average (playing, USB-MIDI streaming)** | | | | | **~146** |

At ~146 mA × 3.3 V ≈ **0.48 W** delivered, average. Drawn from 5 V VBUS through a linear regulator (3.3 / 5 = 66 % efficiency), the input side sees ≈ **146 mA at 5 V / 0.73 W average** — comfortably inside the USB 2.0 default 500 mA / 2.5 W budget, with plenty of margin for a low-power 100 mA / 500 mW port if ever needed.

**Peak vs. average.** During the ~240 µs scan window the gated-Hall current adds ~183 mA (73 × 2.5 mA) on top of the always-on ~101 mA (MCUs + LEDs + LDO Iq), so instantaneous draw spikes to **~284 mA**. The 4.7 µF bulk cap on the LDO output (C20 on MainBoard; C54 on each wing) and the LDO's transient response cover the step. Outside the window the rail is back to ~101 mA. Both wings scan independently (separate MCUs), but the LDO sees the sum — worst case both sweeps overlap; the motherboard's push/pull window is small enough to be scheduled inside the same envelope.

**LDO thermal — comfortable after gating.** TLV755P (SOT-23-5) dissipates **(5 V − 3.3 V) × 0.146 A ≈ 250 mW** averaged. θ<sub>JA</sub> ≈ 195 °C/W gives ~49 °C rise — junction at ~74 °C in 25 °C ambient, ~89 °C in 40 °C ambient. Well below the 125 °C abs-max. Peak-current excursions (~284 mA × 1.7 V ≈ 483 mW) for 240 µs every 1 ms barely budge the junction temperature thanks to the package's thermal mass. The earlier review item — buck regulator or larger LDO package — is no longer required; the SOT-23-5 LDO is the right pick for the gated load profile.

If gating ever has to be disabled (e.g., during bring-up before firmware controls the AO3401A gates), the LDO falls back to ~300 mA / 510 mW worst-case, which is at the edge of SOT-23-5's thermal envelope — keep that in mind for first-power-on without firmware. Default the gate to OFF at reset (P-FET gate pulled high by R40 to VCC) so the hall sensors are de-energised until firmware enables them.

## Wing Power and Bus Interface

Each wing is powered directly from the motherboard's 3.3 V rail through pins 1 and 12 of its 2×6 1.27 mm SMD connector. There is **no per-wing power switch (no TPS2553), no gated wing rail, and no back-feed buffer (no SN74LVC125A)**. With the battery removed, there is no operating mode that powers the motherboard while leaving a wing off — when VBUS is present the whole instrument is powered, when VBUS is gone everything is off — so the back-feed path that the isolation buffer was protecting against no longer exists in any normal operating state.

**Wing reset and presence handling.**

- **NRST** is driven open-drain by the motherboard MCU through a BAT54C steering diode to 3.3 V (U53 main reset, U54 wing reset). The wing MCU's internal NRST pull-up provides idle-high. The open-drain topology means the motherboard can never source current into a wing that is somehow held in reset by another agent (e.g., a programmer connected to a wing).
- **READY** is a passive input on the motherboard with the internal pull-down enabled. The wing drives the line actively high once its firmware has initialised. If a wing is absent, unprogrammed, or still booting, the pull-down resolves the line to "not ready" and the motherboard simply doesn't poll that wing — no external resistor needed.

## SPI Bus Configuration: Wing Master ↔ Main Slave

The motherboard receives sensor data from each wing over a dedicated full-duplex SPI bus. Each wing acts as SPI master; the motherboard acts as slave. The following table details the pin configuration for each SPI signal:

| SPI Signal | Master (Wing) | Slave (Motherboard) | Pins |
|---|---|---|---|
| **NSS** (chip select) | Output, push-pull, no pull-up | Input, pull-up ⬆️ | PA4 (SPI1), PF0 (SPI2) |
| **SCK** (clock) | Output, push-pull, no pull-up | Input, no pull-up | PA5 (SPI1), PF1 (SPI2) |
| **MOSI** (master→slave) | Output, push-pull, no pull-up | Input, no pull-up | PA7 (SPI1), PB15 (SPI2) |
| **MISO** (slave→master) | (not used by master) | Output, pull-up ⬆️ | PA6 (SPI1), PB14 (SPI2) |

**Pull-up Defensive Design:**

- **NSS pull-up on slave side** ⬆️ — Prevents NSS from floating during wing boot; ensures slave remains deselected until master is ready. The master actively drives NSS both high (idle) and low (selected), so the slave's pull-up provides passive safety without creating contention.

- **MISO pull-up on slave side** ⬆️ — Keeps MISO at a defined HIGH state when slave is not selected (NSS high). Without the pull-up, MISO would float, causing excessive power draw in CMOS input buffers and potential EMI. During active transactions, the selected wing slave drives MISO with data; the pull-up is passively overridden.

- **No pull-ups on master outputs** — NSS, SCK, and MOSI are driven as push-pull outputs on the master side. They actively control the bus and do not require pull-ups for proper operation on a dedicated single-slave board-level design.

**Internal Pull-up Implementation:** STM32 GPIO pull-up/pull-down settings apply even when pins are configured as SPI alternate functions. Internal pull-ups (40–50 kΩ typical) are sufficient for on-board traces and eliminate the need for external resistors. The pull-ups automatically release when the SPI peripheral actively drives the pins.

This configuration prevents accidental slave activation, eliminates floating bus states during boot, and follows industry best practice: [Bare-Metal STM32: Setting Up And Using SPI](https://hackaday.com/2022/10/24/bare-metal-stm32-setting-up-and-using-spi/), [STM32 GPIO Alternate Mode Pull-up & Pull-down Function](https://community.st.com/t5/stm32-mcus-products/gpio-alternate-mode-pull-up-amp-pull-down-function/td-p/707864), [ST Microelectronics AN5543: Guidelines for Enhanced SPI Communication on STM32 MCUs](https://www.st.com/resource/en/application_note/an5543-guidelines-for-enhanced-spi-communication-on-stm32-mcus-and-mpus-stmicroelectronics.pdf), and [Can Pull-up Resistors Be Used on SPI Lines?](https://resources.pcb.cadence.com/blog/can-pull-up-resistors-be-used-on-spi-lines).

**Wing-port ESD.** The SRV05-4 arrays at the wing connectors (TV1/TV2 left, TV3/TV4 right) tie pin 5 to the motherboard's 3.3 V rail. Since this is the same rail that powers the wings, ESD steering currents stay in a single power domain.

## Wing Bus Connector

The motherboard↔wing bus uses an **S062100026 — 2×6 (12-pin), 1.27 mm pitch, SMD vertical header** (CN1 = right wing, CN2 = left wing). This is a compact, low-profile SMD part; the mating cable assembly must use the matching 1.27 mm pitch crimp housing.

The 12-pin layout carries 9 signals, 2 VCC, and 3 GND returns — see [architecture.md](architecture.md) for the full pin table. Compared to the earlier 10-pin 2.54 mm design:

- **BOOT0 added** (pin 11) — enables the motherboard MCU to force a wing into system bootloader mode without a physical button. See §"Remote Wing Programming via BOOT0" below.
- **Second VCC pin** (pin 12) — shares power delivery across both connector rows, reducing pin current.
- **1.27 mm vs. 2.54 mm pitch** — smaller footprint, but no longer Dupont-compatible; a 1.27 mm crimp cable or a flex-cable assembly is required. The trade-off is board area vs. cable-swap ergonomics.

## PCB Manufacturing Strategy: JLCPCB Economic, 2-Layer

All three boards (motherboard, left wing, right wing) are manufactured via **JLCPCB Standard (Economic) service**: 2 copper layers, no buried/blind vias, 1 oz copper weight, standard soldermask and silkscreen.

**2-layer constraint — no dedicated VCC plane:**

- **Layer 1:** Signal + GND plane (split GND where necessary)
- **Layer 2:** Signal + power traces (5 V VBUS and 3.3 V routed as traces, not planes; the wings receive 3.3 V directly through their connectors — no separate per-wing rail)

**Implications for power distribution:**

1. **3.3 V rail:** Distributed via wide traces (24–32 mil minimum) rather than a continuous plane. The TLV755P LDO output and the wing-connector VCC pins require direct copper widths to minimize resistance and transient voltage sag.

2. **No distributed plane capacitance:** Decoupling capacitors become critical — they are the only capacitive reservoir for transient current. Each power rail segment (motherboard main, left wing, right wing) gets dedicated bulk (10 µF) and bypass (100 nF per IC) capacitance placed within 5 mm of the load.

3. **GND plane preserved:** The single GND plane on Layer 1 serves as the common return path for all signals and power. This is the primary defense against noise coupling to analog sensor lines (Hall outputs, ADC inputs). Sensitive traces route on Layer 2 with GND return traces of equal width run parallel and adjacent.

4. **Thermal management:** Average dissipation ~250 mW in the TLV755P (SOT-23-5), within its thermal budget at the gated load profile — see "Power Consumption". Thermal vias under the LDO tie directly to the GND plane for passive cooling.

**Trade-off:** Economic 2-layer design saves cost (~20 % vs. 4-layer) at the expense of denser PCB layout, stricter decoupling discipline, and slightly tighter voltage margins. The ~146 mA average current at 3.3 V (and ~284 mA peak during Hall scan windows) is well within the LDO's 500 mA rating.

## Passive Form Factor

Default passive footprint for both resistors and capacitors is **0603**, picked for hand-rework ergonomics on this 2-layer prototype-friendly design. **0402** is reserved exclusively for the **MCU load capacitors** that sit directly between the package's 0.5 mm-pitch pads:
- **MainBoard:** three per-VDD 100 nF (C8, C9, C10), VDDA filter pair 1 µF + 10 nF (C12 + C16) plus VREF+ 1 µF and 100 nF (C17, C18).
- **Wing boards:** four per-VDD 100 nF (C50, C51, C52, C53), VDDA filter 1 µF + 10 nF (C7 + C8) and an additional 1 µF (C55).

The smaller pad geometry minimises the decoupling loop inductance that dominates supply impedance at the M4F's switching harmonics; nothing else on the board needs this. NRST, debounce, ESD, and signal-filter caps all stay 0603. Bulk reservoir caps (4.7 µF — C11/C20 on MainBoard, C54 on wings) stay in **0805** because the dielectric volume forces a larger package anyway.

## LED Brightness Scheme

Three roles, three parts:

- **MainBoard FN status LEDs (LED_FN0/FN1/FN2 = KT-0805G emerald-green 0805, Vf 2.6–3.1 V, R9/R11/R12 = 330 Ω)** — sit *behind* their respective function buttons (SW4/SW2/SW3 = FN0/FN1/FN2) and glow through the translucent button cap. At Vf-typ ≈ 2.85 V on a 3.3 V rail through 330 Ω the LED draws ~1.4 mA — dim by design intent but the at-a-glance visibility is borrowed from the green's high luminous efficiency rather than from raw current. SW1 (global NRST) has no LED.
- **Wing FN LED (LED_FN1 = KT-0603W white 0603, Vf 2.6–3.1 V, R19/R42 = 470 Ω)** — sits behind the wing's BOOT0 button. ~0.4–1.5 mA worst-to-typ. Not used as a runtime indicator in current firmware; bench-only flag for bootloader entry.
- **Power / Ready LEDs (KT-0805Y yellow Vf 1.8–2.4 V or KT-0805G emerald-green Vf 2.6–3.1 V, R10/R6/R9 = 1 kΩ)** — POW on all three boards (yellow), READY on each wing (green). Open-air 0805 status LEDs; 1 kΩ gives ~0.9–1.5 mA on yellow and ~0.2–0.7 mA on green — visible under office lighting without being distracting on a dark stage.

Net LED current contribution to the rail: well under 10 mA total across the whole system, comfortably inside the 500 mA LDO budget.

## Function and Boot Buttons

### MainBoard

Four SMD tactile switches (SW1–SW4):

| Designator | Function | GPIO | Logic | Pull | LED |
|---|---|---|---|---|---|
| SW1 | Global NRST | — (NRST via BAT54C) | Pulls all 3 MCU NRST lines low when pressed | None | No |
| SW2 | FN1 | PB6 | **Low when pressed** (ties GPIO to GND) | MCU internal pull-up | Yes (330 Ω, behind cap) |
| SW3 | FN2 | PB4 | **Low when pressed** (ties GPIO to GND) | MCU internal pull-up | Yes (330 Ω, behind cap) |
| SW4 | BOOT0 / FN0 | PB8 / BOOT0 | **High when pressed** (ties PB8 to 3.3 V) | **External 10 kΩ pull-down (R1) to GND** | Yes — LED_FN0, R9 (330 Ω), driven by **PB9**, behind SW4 cap |

**Global NRST (SW1).** Pressing SW1 drives the open-drain NRST node through the BAT54C network, pulling all three MCU NRST pins (motherboard + both wings) low simultaneously — a full system reset without USB disconnect. SW1 has no GPIO and no LED.

**BOOT0 / FN0 (SW4).** SW4 is dual-purpose: held at power-on (or during NRST via SW1), BOOT0 = 1 forces the motherboard MCU into system bootloader (USB DFU). In normal operation PB8/BOOT0 is sampled only at reset; firmware may thereafter drive PB8 as GPIO (FN0). The external 10 kΩ pull-down (R1) holds BOOT0 low when SW4 is open, providing a defined idle state — unlike FN1/FN2 which rely on the MCU's internal pull-ups. Active-high logic: press = FN0 asserted / DFU condition.

**FN1, FN2 (SW2, SW3).** Active-low, rely on MCU internal pull-ups. No external resistors.

### Wing Boards

Each wing board carries one dedicated **BOOT0 pushbutton** wired the same way as SW4 on the motherboard: the switch ties BOOT0 directly to 3.3 V, with no external pull resistor (the wing's BOOT0 idle state is managed by the motherboard's R_BOOT0 / L_BOOT0 GPIO driving the line low through the bus connector). There are no FN buttons on the wing boards; all user-facing controls are on the motherboard. With remote BOOT0 available via the wing bus connector (see §"Remote Wing Programming via BOOT0"), the physical wing BOOT0 button is a fallback for bench use only.

## MCU Decoupling (STM32G474CBT6, LQFP48)

All three boards run the **same STM32G474CBT6** in LQFP48 with the same decoupling pattern, per the G474 datasheet "Power supply scheme" and AN4488. The LQFP48 package has:

- **3 × VDD pins** (24, 36, 48) — one 100 nF X7R per pin within a few mm of the package (C8, C9, C10, 0402). **VBAT** (pin 1) is tied to VCC since no backup battery is fitted; it requires no dedicated bypass cap — the G474 datasheet Figure 16 does not call for one, and the VDD decoupling covers it.
- **1 × 4.7 µF bulk** ceramic on VDD (C54, 0805). Provides the local reservoir absent a 3.3 V plane on the 2-layer stackup. An additional 1 µF (C55) sits on the same rail.
- **VDDA filter** (pin 21): a ferrite bead between VDD and VDDA (L1, GZ1608D601TF, 600 Ω @ 100 MHz, 200 mA — comfortable for VDDA at ~10 mA when the ADC runs), plus 1 µF (C49) + 10 nF (C48) on VDDA referenced to VSSA. The ferrite is justified on every board: the motherboard reads the pedal pots, and the wings sample 32–40 Hall channels through the on-chip ADC.
- **NRST cap**: 100 nF (C39) close to the NRST pin, per AN4488.

**No HSE crystal.** G474's USB-FS uses HSI48 with the Clock Recovery System (CRS), locked to USB SOF — so no external crystal is needed for USB enumeration, and no 32.768 kHz LSE either (no RTC requirement). PF0/PF1, freed up from OSC_IN/OSC_OUT, are repurposed as GPIO (right-wing SPI2 NSS/SCK on the motherboard; bank-mux control on the wings).

## Key Sensing: Magnet / Hall-sensor Pairing

Each key uses a **Gateron Magnetic Jade Pro mini** switch (KS-33D, total travel 3.5 ± 0.2 mm) paired with an **SC4015SO-N** linear Hall sensor mounted on the opposite side of the 1.5 mm PCB (SMD, marked face toward the switch).

**Polarity.** Gateron specifies the magnet N-pole facing down toward the PCB. The SC4015**-N** variant is activated by N-pole approach to its marked face, so the geometry is correct: as the key is pressed, V<sub>OUT</sub> moves from the quiescent 2.2 V *down* toward 0.8 V.

**Field at the sensor pad** (Gateron-spec, numbers already through the PCB):

| Key state | Field @ sensor | V<sub>OUT</sub> typ (2.0 mV/Gs) |
|---|---|---|
| Rest (0 mm) | 75 ± 10 Gs | ≈ 2.05 V |
| Full press (3.5 mm, 500 gf) | 680 ± 70 Gs | ≈ 0.84 V |

Gateron's figures assume their reference PCB (≈ 1.6 mm). Our 1.5 mm stack puts the sensor 0.1 mm closer to the magnet — field slightly higher, inside the ±10 % tolerance.

**Usable ADC swing**: ~1.2 V across 3.5 mm, i.e. ~1500 LSB on a 12-bit / 3.3 V ADC (~430 LSB/mm). In the worst-case combination (field at +10 %, sensor sensitivity at its +10 % limit), output clamps at the 0.8 V floor during the last ~0.1–0.2 mm of travel — no effect on note detection or velocity since the velocity-relevant portion of travel is mapped well before bottom-out.

## 3.3 V Rail (TLV755P)

TLV755P input (pin 1, IN) is fed from **VBUS** through the USB front-end (TVS clamp, optional polyfuse/eFuse). VBUS is the only upstream source — no battery, no buck, no charger — so the LDO sees the standard USB 2.0 5 V ± tolerance (4.40 V min at full 500 mA draw with worst-case cable IR drop, 5.25 V max).

- **Dropout headroom:** the TLV755P needs ≥ 3.55 V for 3.3 V / 500 mA per datasheet. Comfortable even at the worst-case 4.40 V VBUS minimum, with margin remaining after the TVS clamp's negligible leakage drop.
- **Hot-plug behaviour:** when the cable is connected, VBUS ramps over ~10 ms; the LDO follows; both wings come up on the same 3.3 V rail simultaneously. Unplugging cuts power instantly — no orderly shutdown is performed (there is nothing to save: no battery state, and no log persistence beyond what the firmware writes synchronously to flash).
- **Input decoupling:** a single 1 µF 0603 (C15) on VBUS at the LDO input pin — datasheet minimum is 0.47 µF, so 1 µF is spec-compliant with margin. The worst-case scan-window load step (~140 mA on VBUS for 240 µs) droops C15 by ~34 mV, which leaves the LDO well inside its regulation window. The TVS clamp (D5) sits between C15 and the USB connector. **Output decoupling:** 1 µF (C19) + 4.7 µF (C20) on VCC, both within a few mm of U6-5.

See the "Power Consumption" section above for the thermal analysis — at the gated load profile the SOT-23-5 package is adequate.

## Push/Pull Sensor (spring blade + hall sensors)

The instrument replaces the acoustic bellows with a **flexure-style spring blade** whose deflection is read by two SC4015 linear hall sensors on the motherboard (U57, U58). As the player pushes or pulls, the blade flexes one way or the other; a small magnet on the moving end translates that deflection into a bipolar field at the sensor faces. The two sensors are read into ADC channels PB1 and PB12 — one biased to detect push, the other pull — and the firmware differences them to recover the signed effort with rest-position cancellation.

**Why this over a loadcell.** The first prototype used a loadcell + CS1237 24-bit Σ-Δ ADC. The electrical path was clean, but the mechanical feel was wrong: the loadcell's near-zero compliance means the player gets no proprioceptive feedback as they ramp effort — it plays like pressing on a wall. A spring blade gives a small, defined travel proportional to effort, which is what bandoneonists already expect from the bellows. The hall-based readout also fits the existing per-key sensor BOM (same SC4015 part, same supply, same ADC pipeline), so no new parts class is introduced.

**Why two sensors.** A single hall on a unipolar magnet only resolves one direction. With two sensors mounted on either side of the blade's neutral position (or one above / one below, with opposing N-pole orientations), push and pull each push exactly one sensor below quiescent and leave the other at rest. Subtracting the two readings gives a signed value through zero, with the resting offset cancelled — robust against temperature drift in either sensor.

**Power.** Both sensors share the motherboard's gated `VDDH` rail (see "Power Consumption") via Q1 (AO3401A) — sampled in step with the rest of the hall network, default-OFF at reset.

The deferred loadcell + CS1237 path is no longer on the BOM. If a future variant ever wants the bridge approach (e.g., a force-curve mode for non-bandoneonists), CS1237 is still a credible choice — see archived notes.

## Pedals

Two TRS 6.35 mm jacks on the motherboard, with mechanical presence sensing (switched contact that reports whether a plug is inserted):

- **Sustain port** — expects a TS pedal shorting Tip–Sleeve. Digital input with pull-up; presence sense gates the MIDI sustain event.
- **Expression port** — accepts M-Audio EX-P / Roland EV-5 and compatible TRS pots. The MCU measures **R(Tip-Ring)** via a **3.9 kΩ pull-up** (R7, basic-part E24 value — nearest standard to 4 kΩ, < 3 % deviation, negligible effect on the voltage range). Voltage varies from ~0.67 V (min) to ~2.5 V (max) — 56 % of the ADC range, drawing ≤ 0.85 mA. The same measurement also accepts a TS sustain pedal plugged into this jack (Tip–Ring short = full deflection), so users who only have a sustain pedal are not stuck.

### Expression pedal reference measurements

M-Audio EX-P and Roland EV-5 have the wiper on the TRS tip.

| Knob | R(Ring-Sleeve) | R(Tip-Sleeve) heel / tip | R(Tip-Ring) heel / tip |
|---|---|---|---|
| max | 65 kΩ | 53.64 / 64 kΩ | 12.46 / 1 kΩ |
| min | 11.47 kΩ | 1 / 12.46 kΩ | 12.46 / 1 kΩ |

Setting M-Audio mode to "Other" swaps tip and ring.

## USB Connector Choice (USB-B)

The instrument uses a **USB Type-B** receptacle (USB1, right-angle SMD). The choice is deliberate:

- **Mechanical robustness**: USB-B connectors have a large, deep socket with four substantial through-hole anchor pins. The mating plug latches positively and requires a deliberate pull to remove — no accidental disconnects during performance.
- **Cable retention**: the square-socket geometry prevents the cable from wiggling free when the instrument is moved on stage or rested on a stand.
- **Standard MIDI device convention**: USB-B is the established connector for hardware synthesisers, keyboards, and audio interfaces. Experienced musicians already own USB-A-to-B cables.

USB-C would offer a smaller footprint and reversibility, but its connector body is less robust to lateral stress and the cable can be unplugged with a light tug — an unacceptable failure mode mid-performance. No PD negotiation is performed (VBUS is taken as-is at 5 V), so the CC pull-down resistors that USB-C requires add complexity for no benefit here.

## Programming Port (STDC14 Pogo Pads)

Each board (motherboard and both wings) exposes **14 pogo-pin landing pads** laid out per the **STDC14** pinout (ST's modern compact debug standard). There is **no connector body** on the BOM — the pads are bare copper, touched by a **TC2070-IDC-050** spring-loaded pogo jig pressed against the board when programming or debugging.

**Why no connector.** A through-hole or SMD STDC14 header would consume board area touched only at the factory and during occasional rework. The pogo-pad approach leaves the footprint as a solder-free land pattern; the jig is held by hand or a fixture for the few seconds needed to flash firmware.

**Mating jig**: Tag-Connect TC2070-IDC-050 (0.050" / 1.27 mm pitch, 14-pin, with legs). The legs anchor the jig to the board during the programming cycle. This jig is **not on the BOM** — it is a workshop tool, one per programmer setup.

STDC14 carries: SWD (SWDIO/SWCLK), SWO trace, NRST, UART VCP (TX/RX), target VCC reference, and GND returns — everything needed for flashing, halting, real-time tracing, and serial console.

**STDC14 GNDDetect (pin 11) → PA15 (mainboard) / PA15 (each wing).** Per UM2448 Rev 9 Table 6 note 6, the STLINK-V3SET firmware ties pin 11 to GND specifically so the **target** can detect that a tool is connected. The TC2070-IDC-050 cable is passive and passes pin 11 through. Firmware configures PA15 as input with the internal pull-up enabled: PA15 reads **LOW = STLINK attached**, **HIGH = no probe**. Available uses: enable a developer USB-VCP command set, blink a "debug-mode" LED, suppress the wing-bus watchdog while a probe is mid-flash, etc. The line is on `PGM_DETECT` in the netlist and protected by the same SRV05-4 arrays as the rest of the STDC14 channels.

## Remote Wing Programming via BOOT0

The wing bus connector (CN1/CN2) carries a **BOOT0** line (pin 11) driven by the motherboard MCU:

- CN1-11 (`R_BOOT0`) → motherboard GPIO **PB13**
- CN2-11 (`L_BOOT0`) → motherboard GPIO **PA3**

The motherboard also controls wing **NRST** (CN1/CN2 pin 4, open-drain via BAT54C). Together these two lines allow the motherboard to force either wing into the STM32G474 system bootloader:

1. Assert BOOT0 high (motherboard drives PB13/PA3 → 3.3 V).
2. Assert NRST low, then release it.
3. Wing MCU boots with BOOT0 = 1 → enters system bootloader (supports USART, SPI, I2C protocols).
4. Motherboard communicates with the wing bootloader over the existing SPI bus wires (MOSI/MISO/SCK/NSS), which the STM32G474 bootloader can expose as an SPI slave interface.
5. Motherboard receives new firmware from the USB host and relays it to the wing — a full OTA-style wing update without touching the wing board.

This eliminates the need to physically access the wing's BOOT0 button or STDC14 pads for firmware updates in the field. The STDC14 pads remain available for initial factory programming and debug.

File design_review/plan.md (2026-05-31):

# MainBoard Design Review Plan

Sources inspected: `export/BOM_MainBoard_MainBoard.csv`, `export/Netlist_MainBoard.net`,
`export/Netlist_WingLeft.net`, `export/Netlist_WingRight.net`,
`export/PickAndPlace_*_fixed.csv`, `export/SCH_MainBoard.pdf`, `hardware.md`,
`architecture.md`, `datasheet_summaries.md`, `requirements.md`.

**Round 4 (2026-05-30)** — re-exported BOMs and netlists from the schematic.
Multiple previously-flagged items resolved, several new aspects audited.

Each item has a status:
- **PASS** — verified correct, no action needed
- **WARN** — concern that needs user confirmation before closing
- **FAIL** — definitive mismatch between netlist and documentation / a design error; doc or schematic must be updated
- **OPEN** — cannot be verified from BOM/netlist alone (firmware, layout, or datasheet lookup needed)

---

## 1. Power Supply Chain

### 1.1 VBUS TVS (D5, SMF5.0A)
Netlist: `D5-1(K) → VBUS`, `D5-2(A) → GND`. Unidirectional, cathode to VBUS.
**PASS** — correct polarity, correct part (SOD-123FL, Vc=9.2 V).

### 1.2 LDO Enable (R14, TLV755P U6)
Netlist: `R14-1 → VBUS`, `R14-2 → U6-3 (EN)`. 10 kΩ from VBUS to EN.
EN threshold ≥ 1 V; at 4.4 V VBUS min, EN ≈ 4.4 V → LDO enabled.
**PASS** — always-on LDO correctly wired.

### 1.3 LDO Input / Output Decoupling
Netlist: `C15 (1 µF 0603) → VBUS`, `C19 (1 µF 0603) + C20 (4.7 µF 0805) → VCC (output)`.
Datasheet requires ≥ 0.47 µF in + ≥ 0.47 µF out.

Transient sanity-check on the input cap: worst-case scan-window load step is ~140 mA delta on VBUS, sustained for the 240 µs Hall-scan window. Droop on a 1 µF input cap = `I·t/C` = `0.140 × 240e-6 / 1e-6` ≈ **34 mV**. VBUS worst-case minimum 4.40 V → 4.37 V during scan; the LDO needs only 3.55 V to maintain 3.3 V at full load → margin > 800 mV remains. USB-cable inductance (~0.5 µH for a typical 1–2 m cable) recharges C15 between scan windows in microseconds. The 1 µF input cap is **electrically adequate** — no need to add bulk or bypass.

`hardware.md` previously claimed "10 µF bulk + 100 nF bypass" on the LDO input — that overstated the build. Doc updated to match the actual 1 µF as of this review round.
**PASS** — schematic is correct; doc corrected.

### 1.4 LDO VIN Headroom
VBUS min 4.40 V; TLV755P dropout at 500 mA max 215 mV → min VIN needed 3.515 V.
4.40 V − 0.215 V = 4.19 V output → regulated at 3.3 V with 0.89 V margin.
**PASS** — comfortable headroom even at worst-case USB cable IR drop.

### 1.5 Hall-sensor Gate (Q1, AO3401A P-ch)
Netlist: `Q1-2(S) → VCC`, `Q1-3(D) → VDDH`, `Q1-1(G) → R5(1 kΩ) → PA2 (HALL_NEN)` and `R6(100 kΩ) → VCC`.
P-FET: gate pull-up to VCC = OFF by default at power-on (sensors de-energised). Firmware drives PA2 low through R5 to turn on.
**PASS** — correct default-off topology; gate resistors protect against inrush.

### 1.6 VDDH Bypass
Netlist: `CP1(100 nF 0603) + CP2(100 nF 0603)` on VDDH.
**PASS** — two 100 nF bypasses on the gated hall rail (one per SC4015).

---

## 2. MCU Decoupling (STM32G474CBT6, U1)

### 2.1 VDD / VBAT Pin Bypass Caps
G474 LQFP48 has **3 VDD pins** (24, 36, 48) and **VBAT** (pin 1). All four are tied to VCC in the netlist.
Netlist VCC net has **C8, C9, C10** (three × 100 nF 0402) for VDD bypass.

VBAT does **not** require a dedicated bypass cap when no backup battery is fitted: the G474 datasheet Figure 16 ("Power supply scheme") shows VBAT tied directly to VDD with no separate cap, and the mandatory decoupling caps are listed only for VDD/VDDA/VREF. Plane/trace inductance from VBAT to the nearest VDD bypass cap is the only practical concern, and on a LQFP48 the VBAT pin (1) sits 1–3 mm from the C8/C9/C10 footprints.
**PASS** — cap count matches G474 datasheet's "Power supply scheme" recommendation; no 4th cap required.

### 2.2 VDD Bulk Cap
Netlist: `C11 (4.7 µF 0805)` on VCC.
**PASS** — adequate bulk reservoir.

### 2.3 VDDA / VREF+ Filter
Netlist: `VCC → L1 (ferrite GZ1608D601TF 600 Ω/100 MHz) → VDDA`. VDDA net pools **U1-20 (VREF+) and U1-21 (VDDA)** with `C16(10 nF) + C17(1 µF) + C12(1 µF) + C18(100 nF)` to GND. VSSA (U1-19) tied to GND.
VREF+ and VDDA are bonded after the ferrite — acceptable when ratiometric VREF is not needed (key-position and pedal ADC are not ratiometric).
**PASS** — ferrite + multi-value VDDA/VREF+ decoupling per AN4488.

### 2.4 NRST Cap
Netlist: `C4 (100 nF 0603)` on M_NRST.
**PASS** — per AN4488 recommendation.

### 2.5 VBAT Pin
Netlist: `U1-1 (VBAT) → VCC`. No backup battery fitted, VBAT tied to VCC.
**PASS** — acceptable; RTC / backup registers not used.

### 2.6 No External Crystal
Netlist: PF0/PF1 (OSC_IN/OSC_OUT) are repurposed as R_SPI_NSS and R_SPI_SCK respectively (right-wing SPI).
USB uses HSI48 + CRS; no LSE fitted.
**PASS** — crystal-less USB design confirmed.

---

## 3. ESD and Protection Coverage

### 3.1 VBUS Clamp (D5)
See §1.1. **PASS**.

### 3.2 USB D+/D− (TV8, SRV05-4)
Netlist: `TV8-1 → USB_DP(PA12, USB1-3)`, `TV8-3 → USB_DM(PA11, USB1-2)`, `TV8-2 → GND`, `TV8-5 → VBUS`.
Pin 5 (V+) tied to VBUS is correct: no PD negotiation means VBUS is always 5 V, so the upper steering diodes are safe to activate. ESD charge steers to VBUS (held by SMF5.0A) or GND — full bidirectional clamping.
**PASS**

### 3.3 Pedal Jack ESD (TV7, SRV05-4)
Netlist: `TV7-5 → VCC (3.3 V)`, channels: `TV7-1 → SUS_PEDAL`, `TV7-3 → EXP_PEDAL`, `TV7-4 → EXP_PEDAL_INT`, `TV7-6 → SUS_PEDAL_INT`.
**PASS** — consistent.

### 3.4 Wing-Bus ESD (TV1–TV4, SRV05-4 × 2 per wing)
Netlist: `TV1-5, TV2-5, TV3-5, TV4-5 → VCC`.
Wing bus signals protected: SPI×4, NRST, READY, BOOT0 (7 signals total, 8 channels of headroom across two SRV05-4 per wing).
**PASS** — pin 5 on 3.3 V rail (same domain as wings).

### 3.5 Programming Port ESD (TV5–TV6, SRV05-4)
Netlist: `TV5-5, TV6-5 → VCC`. Channels protect SWDIO, SWCLK, SWO, NRST, USART_TX, USART_RX, DETECT.
ESD coverage is architecturally correct. Signal-to-pad routing is a separate issue covered in §7.1.
**PASS** (ESD only — see §7.1 for wiring).

### 3.6 Function-Button ESD (D1–D4, H5VND5BA)
Netlist: D1–D4 each have pin 1 → GND, pin 2 → respective button net.
D1 specifically protects the BAT54C common-cathode bus (SW1 / NRST OR-tie).
**PASS** — bidirectional clamp on each line.

### 3.7 VBUS Polyfuse / eFuse
Deliberately not fitted for v1. Rationale: USB 2.0 host port is spec-required to limit to 500 mA; SMF5.0A clamps transient surges; TLV755P has internal foldback + thermal shutdown. A polyfuse or eFuse would be a JLCPCB extended part with no basic-part substitute.
**SKIP — conscious decision, not an oversight.**

---

## 4. USB Interface

### 4.1 USB-B Connector (USB1)
BOM: U-B-M4SS-W-1, right-angle SMD, 4 contacts + 2 GND anchors.
Netlist: `USB1-1(VBUS)`, `USB1-2(D−)`, `USB1-3(D+)`, `USB1-4(GND)`, `USB1-5(GND)`, `USB1-6(GND)`.
**PASS** — correctly wired.

### 4.2 USB D+/D− MCU Pins
Netlist: PA11 = D−, PA12 = D+.
G474 datasheet: PA11 = USB_DM, PA12 = USB_DP. ✓
**PASS**

### 4.3 USB Crystal-less Enumeration
HSI48 + CRS per architecture.md. No crystal in BOM. VDDA ≥ 2.4 V (3.3 V VCC) as required by G474 ADC and USB.
**PASS**

### 4.4 USB VBUS Sense
Netlist: no MCU pin tied to VBUS for sense. For a fully bus-powered device this is correct — when VBUS is removed, the MCU loses power and the bus is disconnected automatically. STM32G474 USB peripheral's VBDEN bit must be cleared in firmware so it does not wait for VBUS presence on an unconnected pin.
**OPEN** — confirm in firmware that USB_BCDR.VBDEN = 0 (or use the equivalent HAL config for "no VBUS sensing").

---

## 5. Wing Bus

### 5.1 Connector Part vs. Architecture Documentation
BOM: `CN1, CN2 = S062100026`, which is 2×6 (12-pin), 1.27 mm pitch, SMD vertical.
`architecture.md` and `hardware.md` updated with correct connector, full 12-pin table (2× VCC, 3× GND, 4× SPI, READY, NRST, BOOT0), and trade-off note (1.27 mm cable required, no Dupont compatibility).
**PASS**

### 5.2 Wing Bus Signal-to-Pin Mapping (CN2 = left wing)
| Net | CN2 pin | MCU GPIO |
|---|---|---|
| VCC | 1, 12 | — |
| L_READY | 2 | PB0 (via R2 100 Ω) |
| L_SPI_NSS | 3 | PA4 |
| L_NRST | 4 | PB2 (via R3 100 Ω, BAT54C U2-A2) |
| L_SPI_SCK | 5 | PA5 |
| GND | 6, 8, 10 | — |
| L_SPI_MISO | 7 | PA6 |
| L_SPI_MOSI | 9 | PA7 |
| L_BOOT0 | 11 | PA3 |

**PASS** — SPI1 (PA4–PA7) correctly serves left wing. Wing's matching netlist confirms same pin numbers on CN1 of the WingLeft side, with wing-side MCU on the SPI1 alternate (PA4/PA5/PB4/PB5, AF5).

### 5.3 Wing Bus Signal-to-Pin Mapping (CN1 = right wing)
| Net | CN1 pin | MCU GPIO |
|---|---|---|
| VCC | 1, 12 | — |
| R_READY | 2 | PA8 (via R4 100 Ω) |
| R_SPI_NSS | 3 | PF0 (OSC_IN repurposed, AF5 = SPI2_NSS) |
| R_NRST | 4 | PB11 (via R8 100 Ω, BAT54C U3-A2) |
| R_SPI_SCK | 5 | PF1 (OSC_OUT repurposed, AF5 = SPI2_SCK) |
| GND | 6, 8, 10 | — |
| R_SPI_MISO | 7 | PB14 (AF5 = SPI2_MISO) |
| R_SPI_MOSI | 9 | PB15 (AF5 = SPI2_MOSI) |
| R_BOOT0 | 11 | PB13 |

PF0/PF1 are AF5 SPI2 alternates per the STM32G474 datasheet (DS12288, Section 4.11 Alternate Function table) — explicitly listed as `SPI2_NSS` and `SPI2_SCK`. Combined with PB14/PB15 (also AF5), SPI2 routes cleanly without remapping.
**PASS** — PF0/PF1 valid as SPI2 AF5; mapping verified against datasheet.

### 5.4 Remote BOOT0 on Wing Connector
Netlist: `CN2-11 = L_BOOT0 → PA3`, `CN1-11 = R_BOOT0 → PB13`.
Documented in `architecture.md` bus table and `hardware.md` §"Remote Wing Programming via BOOT0".
**PASS**

### 5.5 Wing NRST Open-Drain Topology (BAT54C)
Netlist `$1N16140` net: `U2-3(K) + U3-3(K) + SW1-2 + D1-2 + C1-1`.
BAT54C common-cathode: at idle the cathode is pulled toward GND by D1/C1 leakage, leaving NRST lines undisturbed (reverse-biased). When the cathode net is pulled to GND (by SW1 or firmware), both wings' NRST anodes are pulled to ~Vf ≈ 0.3 V → wings held in reset.
**PASS** — topology is valid (see also §6.4 for SW1 function).

### 5.6 Series Resistors on READY/NRST Wing Signals
R2, R3, R4, R8 are all 100 Ω. They sit between the MCU GPIO and the ESD device / connector.
**PASS** — standard 100 Ω series termination.

### 5.7 Wing BOOT0 — 100 Ω series R now added (RESOLVED)
Round 3 flagged the BOOT0 lines as the only wing-bus signals without a 100 Ω series limiter against wing-local-button contention. Round 4 confirms the fix:
- `L_BOOT0` net: `TV2-1, CN2-11, R16-1 (100 Ω)`; `R16-2` lands on net `$1N68331` together with `U1-11 (PA3)`.
- `R_BOOT0` net: `TV4-1, CN1-11, R17-2`; `R17-1` on net `$1N68371` with `U1-27 (PB13)`.

Contention math with the new resistors: if a user presses the wing-local SW1 (BOOT0 button, ties VCC straight to the wing-side BOOT0 net) while the mainboard MCU is sinking the line through R16/R17, the current is `(VCC − V_OL) / (R_series + R_switch + R_cable) ≈ 3.3 V / (100 Ω + ~50 mΩ + ~100 mΩ) ≈ 33 mA`. The STM32G474 GPIO can sustain this — the absolute max is 25 mA continuous at V_OL ≤ 0.4 V, ~ 50 mA pulse — so a momentary button press is safely bounded. The series R also rules out the prior worst-case "tens of A through the switch contact" peak.

**PASS** — all six wing-bus signals (NRST/READY/BOOT0 × 2 wings) now share the same 100 Ω series-R pattern. `hardware.md` should mention R16/R17 in the wing-bus discussion.

---

## 5W. Wing-board internal review

Items below cover the wing boards themselves (not the wing-to-mainboard bus). Both wings share the same MCU and topology; only WingLeft pins are quoted unless otherwise noted.

### 5W.1 Wing power gate (Q1 AO3401A) and gate network
Wing netlist: `Q1-2 (S) → VCC`, `Q1-3 (D) → VDDH`, `Q1-1 (G) → R7 (1 kΩ) → HALL_NEN → U37-25 (PB11)` and a separate gate pull-up to VCC. Same default-OFF P-FET topology as the mainboard (§1.5). PB11 drives gate-low to enable VDDH for the scan window.
**PASS** — symmetric to the mainboard hall-sensor gate.

### 5W.2 74HC4052 mux topology
- WingLeft: 4 muxes (U5, U14, U23, U32 — see §12.1a). Each mux exposes 8 channels → 32 channels total. Wing has 33 Hall sensors per BOM — count mismatch: only 32 channels are routed through muxes; one sensor (or 33-channel sweep) must be either unused or routed elsewhere. Worth a spot-check against the schematic/PCB.
- WingRight: 5 muxes (U5, U14, U23, U32, U41). 40 channels for 38 sensors → 2 spare channels. ✓
- Mux `E̅` (pin 6) is tied to GND on every mux on both wings → muxes are permanently enabled. Bank-power gating happens upstream at Q1 / VDDH, not at the mux enable, so always-on E̅ is consistent with the gated-Hall design. The "available for bank-switching" wording in `datasheet_summaries.md` describes a capability that the schematic doesn't use.
- Mux select lines `S0` (pin 10) and `S1` (pin 9) are bussed to all muxes in parallel. Driven by `SEL0 → U37-3 (PC14)` and `SEL1 → U37-4 (PC15)`.

**PASS for topology; WARN for the 32/33 channel discrepancy on WingLeft** — flag for schematic-level confirmation.

### 5W.3 Mux select on PC14 / PC15 (LSE-domain pins)
SEL0/SEL1 land on `PC14-OSC32_IN` / `PC15-OSC32_OUT`, which sit in the STM32G4's *backup* power domain. Per DS12288, these pins have **reduced output drive** when configured as GPIO, and they require **PWR_CR1.DBP = 1** to enable writes to the RCC backup-domain control register before they can be driven (the same dance as touching VBAT-domain RTC registers). Loads here are tiny — 4 (WingLeft) or 5 (WingRight) mux S inputs at a few pF each, switched at the scan rate (~kHz), well inside the reduced drive budget — so the hardware is fine.

**PASS for hardware; OPEN for firmware** — confirm the wing's HAL init sets `PWR_CR1.DBP` before configuring PC14/PC15 as GPIO outputs, otherwise SEL0/SEL1 will read back as ones and the scan will be stuck on channel 3.

### 5W.4 Wing buttons — three on each wing, not one
Netlist shows three TS-1088 tactile switches per wing (matches BOM `qty = 3`):

| Wing SW | Net | MCU pin | Role |
|---|---|---|---|
| SW1 | BOOT0 | U37-45 (PB8/BOOT0) | Local BOOT0 entry (bench-only; redundant with mainboard's remote BOOT0 via CN-11) |
| SW2 | PGM_RESET | U37-7 (NRST) | Local NRST button (debounced via C2, ESD via D2, ORed onto the wing NRST through TV2-6) |
| SW3 | SW_FN0 | U37-27 (PB13) | Generic FN button on PB13; debounced via C3, ESD via D3 |

`hardware.md` §"Function and Boot Buttons → Wing Boards" says "Each wing board carries one dedicated BOOT0 pushbutton… There are no FN buttons on the wing boards" — that's not what is built. The wings have local NRST and FN0 buttons too. Update the doc with the full per-wing button table, noting SW3 (FN0 on PB13) is a hard-soldered control that the wing firmware can use as a developer poke (mode toggle, dump-state, etc.).
**WARN (doc only)** — schematic is functional; documentation undersells what's on the wing.

### 5W.5 Wing READY — R9 is the LED current-limit, not a READY series R (CORRECTED)
Round 3 misread the wing READY topology. Re-checked against the current netlist:
- `READY` net: `U37-44 (PB7), CN1-2, TV1-6, R9-2`. PB7 drives the connector pin **directly**, with no wing-side series resistor.
- `R9-1` lands on net `$1N52732` together with `LED_READY-1`. R9 = 470 Ω is the LED current-limit, not a damping R.

So the actual topology is:
```
MCU PB7 ──┬── CN1-2 (out to mainboard, then to R2/R4 100 Ω series, then to PB0/PA8)
          └── R9 (470 Ω) ── LED_READY ── GND   (visual indicator: lit when wing READY = HIGH)
```

The only damping R on the READY line is the mainboard's R2/R4 = 100 Ω. With the LED branch drawing ~1.4 mA when READY=HIGH (Vf ≈ 2.85 V on 3.3 V through 470 Ω), the GPIO sees a 1.4 mA static load — well inside the G474's 8 mA min output spec, V_OL/V_OH unaffected. The READY-LED visualization is a nice touch for board bring-up.

**PASS** — topology works; previous round's "570 Ω total series" line was wrong and has been corrected.

### 5W.6 Wing hardware identification — 3-bit ID resistors (NEW)
Wing netlists carry three named ID nets read by the wing MCU at boot:

| Wing | ID0 (PC13, U37-2) | ID1 (PF0, U37-5) | ID2 (PF1, U37-6) | Binary |
|---|---|---|---|---|
| Left  | R1 (10 kΩ) → **GND** | R2 (10 kΩ) → **VCC** | R3 (10 kΩ) → **GND** | `010` |
| Right | R1 (10 kΩ) → **VCC** | R2 (10 kΩ) → **GND** | R3 (10 kΩ) → **GND** | `001` |

Each ID line has a single 10 kΩ pull (no companion pull on the other rail — the MCU's internal pull-resistor option is not used, the external 10 kΩ sets the state on its own). 3 bits give 8 possible wing layouts; two are used today, six are reserved for future keyboard variants (Concertina, Einheitsgriff, etc., per `architecture.md`).

Firmware reads PC13/PF0/PF1 at boot and embeds the resulting 3-bit ID in the per-frame wing identification code the mainboard sees over SPI. PC13 is in the backup-power domain (same `PWR_CR1.DBP = 1` caveat as the §5W.3 mux-select pins). PF0/PF1 are former OSC_IN/OSC_OUT and have no special access rules on the wing (these pins are repurposed on the mainboard as SPI2 NSS/SCK for the right wing — different boards, different uses of the same physical pads).

**PASS** — clean implementation; means the same wing firmware binary runs on every wing variant. Mention in `architecture.md` §"Internal Bus" so a reader looking at SPI frame format understands where the wing-ID byte comes from.

### 5W.7 WingLeft 33rd Hall sensor — direct ADC, not mux (RESOLVED §5W.2)
Round 3 flagged a 32-vs-33 channel mismatch on WingLeft (4 muxes provide 32 channels, but the BOM has 33 Hall sensors). Round 4 traces the 33rd:
- WingLeft sensors `U1, U2, U3, U4, U6–U13, U15–U22, U24–U31, U33–U36, U38` — that's 33 designators (U5/U14/U23/U32 are muxes, U37 is MCU).
- Net `A_IN0`: `U37-8 (PA0), U38-3 (SC4015 OUT)` — sensor U38's output goes **straight to the MCU's ADC pin PA0**, bypassing the mux network.
- The other 32 sensors route through the four 74HC4052 muxes onto `A_IN2`–`A_IN9` (8 mux outputs × 4 channels each = 32 channels), read on PA1–PA7 / PB0–PB1 via the ADC.

So the topology is **32 muxed + 1 direct** for 33 total. The direct-ADC channel is U38, which sits next to the MCU and gets the lowest-impedance read path. Likely the highest-priority key (or one chosen for layout convenience — confirm against the keyboard mapping doc).

**PASS** — count reconciles; one direct ADC sensor on WingLeft, no direct sensors on WingRight (its 38 sensors fit comfortably across 5 muxes × 8 channels = 40, with 2 spare).

### 5W.8 Wing A_IN1 has a 100 kΩ pull-down to define floating ADC pin (NEW)
Wing netlist `A_IN1`: `R5-1 (100 kΩ), U37-9 (PA1)`. `R5-2` on GND. The 100 kΩ pulls a spare ADC channel to a defined voltage so it doesn't float into the input clamp circuitry and inject noise into the shared ADC sample cap when scanning adjacent channels.

This is the right thing to do for any ADC input that isn't routed to a signal source. Mainboard equivalent: `R6 (100 kΩ) → VCC` on the AO3401A gate, which serves the same defined-state role for the P-FET gate (not ADC).
**PASS**.

### 6.1 Switch-to-Designator Mapping (Netlist vs. Documentation)
From netlist nets:
| Designator | Net | Connected to |
|---|---|---|
| SW1 | `$1N16140` | BAT54C U2-K + U3-K (NRST cathode bus) + C1 + D1 |
| SW2 | SW_FN1 | PB6 (FN1) |
| SW3 | SW_FN2 | PB4 (FN2) |
| SW4 | SW_FN0_BOOT0 | PB8/BOOT0 |

`hardware.md` button table matches.
**PASS**

### 6.2 External Pull-Down on BOOT0 (R1)
`hardware.md` button table updated: SW4/BOOT0 has external 10 kΩ pull-down (R1) for defined idle-low; debounce cap C5 (100 nF) parallels R1 (RC = 1 ms hold-time on BOOT0 after SW4 release — useful for asserting BOOT0 *before* the NRST release). FN1/FN2 use MCU internal pull-ups.
**PASS**

### 6.3 SW1 = Global Reset Button
Documented in `hardware.md` §"Function and Boot Buttons": SW1 grounds the BAT54C common cathode, forward-biasing both diodes and pulling all three MCU NRST lines to ~0.3 V simultaneously.
**PASS**

### 6.4 LED_FN0 (PB9)
LED behind SW4 (BOOT0/FN0) cap. R9 330 Ω, KT-0603W (white). Drive on PB9 (U1-46). Mirrors FN1/FN2.
**PASS** for wiring; see §10.1 for the brightness calculation correction.

### 6.5 FN Button Logic Levels
SW2 (FN1) and SW3 (FN2): pin 1 → GND, pin 2 → GPIO. Active-low via MCU internal pull-up. ✓
SW4 (BOOT0): pin 1 → VCC, pin 2 → PB8. Active-high. ✓
**PASS**

---

## 7. Programming Port (STDC14, CN3)

### 7.1 SWD Signal Wiring — verified against netlist + LQFP48 pinout
Cross-checked CN3 pin assignments against the actual `Netlist_MainBoard.net` nets and against the STM32G474CBT6 LQFP48 pinout (DS12288 Figure 6):

| STDC14 std pin | Mainboard net | Mainboard MCU pin | LQFP48 function |
|---:|---|---|---|
| 3  T_VCC | VCC | — | — ✓ |
| 4  T_SWDIO | PGM_SWDIO | U1-37 | **PA13** = SYS_JTMS-SWDIO ✓ |
| 5  GND | GND | — | — ✓ |
| 6  T_SWCLK | PGM_SWCLK | U1-38 | **PA14** = SYS_JTCK-SWCLK ✓ |
| 7  GND | GND | — | — ✓ |
| 8  T_SWO | PGM_SWO | U1-40 | **PB3** = SYS_JTDO-TRACESWO ✓ |
| 11 GND_DETECT | PGM_DETECT | U1-39 | PA15 (GPIO) — see §7.5 |
| 12 NRST | M_NRST | U1-7 | **NRST** ✓ |
| 13 T_VCP_RX | PGM_USART_RX | U1-32 | **PA10** = USART1_RX AF7 ✓ |
| 14 T_VCP_TX | PGM_USART_TX | U1-31 | **PA9**  = USART1_TX AF7 ✓ |

All five SWD/JTAG-critical signals (SWDIO, SWCLK, SWO, NRST, VCC) land on the correct MCU pads, and the VCP UART pair maps to USART1 on its AF7 alternate. Symbol pin-number attributes are consistent with the standard STDC14 footprint — earlier draft of this review (which flagged this section as a critical failure) was based on a mis-extracted pin table; corrected after re-reading the LQFP48 pinout (pins 37/38/40 = PA13/PA14/PB3, not the off-by-two arrangement assumed earlier).

**PASS** — board can be programmed and debugged through the pogo pads as drawn.

### 7.2 STDC14 VCC Reference
Netlist: `CN3-3 (T_VCC) → VCC`. STLINK-V3 uses this pin to reference signal levels.
**PASS** — correctly tied to 3.3 V.

### 7.3 GND Pins on STDC14
Netlist: `CN3-5, CN3-7 → GND`.
**PASS**

### 7.4 No Connector Body on BOM
Confirmed: CN3 has no BOM entry. Mating jig = TC2070-IDC-050 (workshop tool).
**PASS**

### 7.5 STDC14 pin 11 (GNDDetect) → PA15 — tool-presence detect
Netlist: `CN3-11 → PGM_DETECT → U1-39 (PA15)`. Both wings do the same (`CN2-11 → U37-39 → PA15`).

Per **ST UM2448 (STLINK-V3SET user manual) Rev 9, Table 6 note 6**, STDC14 pin 11 is labelled `GNDDetect` and is "**Tied to GND by STLINK-V3SET firmware. It might be used by the target to detect the tool.**" The TC2070-IDC-050 cable is passive and passes pin 11 through. So when the STLINK-V3 is mated, the target sees pin 11 = GND through the probe; when no probe is attached, the line is floating and PA15's internal pull-up resolves it to logic high.

This is precisely the design intent: PA15 reads LOW = STLINK attached, HIGH = no probe. Firmware can use this to enable a VCP echo mode, enter a "developer" command set, blink an LED, or simply log probe attach/detach events.

(Earlier review rounds reported this as inverted vs the standard — that was a misread of the STDC14 spec. UM2448 is unambiguous: ST's intended direction for pin 11 *is* target-detects-tool, with the tool sourcing the GND.)

**PASS** — schematic correct, matches the documented STDC14 usage. Firmware should configure PA15 as input with internal pull-up enabled; document the "STLINK_DETECT" role in firmware notes once PA15 is consumed.

---

## 8. Hall Sensor Subsystem

### 8.1 Motherboard Hall Sensors (U4, U5)
Netlist: `U4-1(VDD) + U5-1(VDD) → VDDH`, `U4-2(GND) + U5-2(GND) → GND`, `U4-3(OUT) → HALL0 → PB1`, `U5-3(OUT) → HALL1 → PB12`.
PB1 = ADC1_IN12 / ADC3_IN1. PB12 = ADC1_IN11. Both are valid ADC inputs on G474.
**PASS** — push/pull sensor pair on ADC-capable GPIOs.

### 8.2 Hall Output Filter Caps
Netlist: `C6 (1 nF 0603) → HALL0`, `C7 (1 nF 0603) → HALL1`. Pin 1 to HALL net, pin 2 to GND.
**PASS** — matches SC4015 datasheet recommendation.

### 8.3 ADC Sample Time
74HC4052 Ron ≈ 80 Ω (wings only). Motherboard Hall sensors drive ADC directly through 1 nF filter caps — RC ≈ 80 ns (SC4015 source impedance × 1 nF). G474 ADC sample-and-hold cap ≈ 4 pF; settling dominated by the external 1 nF, not the mux.
**OPEN** — confirm in firmware that ADC sampling time ≥ 1 µs (covers both motherboard direct and wing-mux paths). Document the ADC config in `hardware.md`.

---

## 9. Pedal Subsystem

### 9.1 Expression Pedal ADC Path
Netlist: `EXPR_PEDAL1-5 → EXP_PEDAL → R7-1(3.9 kΩ) → VCC` and `TV7-3 → U1-8(PA0)`.
**PASS**

### 9.2 Sustain Pedal Path
Netlist: `SUS_PEDAL1-5 → SUS_PEDAL → R13-1(3.9 kΩ) → VCC` and `TV7-1 → U1-9(PA1)`.
**PASS**

### 9.3 PJ-603A Pin 2 (Sleeve) Intentionally Floating; Pin 4 → VCC
Schematic page 6 contains a designer's note: *"Sleeve (S) intentionally NC. ADC reads R(Tip-Ring) only — floating Sleeve makes the measurement independent of per-pedal T/R/S wiring"*. This clarifies that pin 2 (X-marked / NC) is the sleeve.

That leaves pin 4 → VCC as a contact other than the sleeve — most plausibly the normally-closed switch terminal that shorts to pin 3 (Ring) when no plug is inserted, used as an insertion-detect bias that pulls EXP_PEDAL_INT to VCC in the "no pedal" state. The schematic comment confirms intent for the sleeve but does not document pin 4's role.

**WARN** — confirm pin 4 function against the HOOYA PJ-603A datasheet (LCSC C309273) before fab:
  - If pin 4 is the **NC Ring-switch contact** (shorts to pin 3 when no plug) → safe, and explains §9.4.
  - If pin 4 is the **NC Tip-switch contact** (shorts to pin 5 when no plug) → redundant with R7, harmless.
  - If pin 4 is the **sleeve** → fatal: VCC shorts to GND through any plug. Designer's comment rules this out, but confirm with the datasheet anyway.

### 9.4 Insertion-Detect Caps (C13, C14) → GND, with 1 kΩ series (RESOLVED)
Round 3 flagged C13/C14 as caps from the GPIO to VCC (no useful filter direction and coupling VCC noise back into the slow input). Round 4 confirms the reworked topology:

- `EXPR_PEDAL pin 3 → C13 plate1` and `EXPR_PEDAL pin 3 → R18 (1 kΩ) pin 1`. C13's other plate is on **GND**.
- `R18 pin 2 → EXP_PEDAL_INT → TV7-4 (ESD) → U1-3 (PC14)`.
- Symmetric on the sustain side with C14 / R19 / TV7-6 / U1-4 (PC15).

So the new topology is `jack ring ── ┬── C13 → GND` and `└── R18 (1 kΩ) → ESD ── PC14`. Reading the chain at the connector side first:
- HF noise on the jack ring is shunted to **GND** by C13 — the correct direction relative to the MCU input threshold reference.
- The 1 kΩ series R combines with the SRV05-4 clamp and the MCU input capacitance to form an explicit low-pass on the GPIO side (τ ≈ 1 kΩ × (CJ ≈ 3.5 pF + Cpin ≈ 5 pF) ≈ 8.5 ns — fast enough not to miss insertion events, slow enough to soak residual ESD ringing).
- The cap-to-GND also gives the GPIO a defined ramp during VCC inrush (no longer follows VCC).

One small note: the cap is on the *connector* side of the series R rather than directly across the MCU pin to GND. That means R18 + C13 doesn't form a "classical" RC at the input — the cap mainly shunts noise at the source, and the R + ESD + Cpin form the low-pass at the MCU. Either ordering works; this one keeps the cap close to where noise enters (the jack), which is arguably the better placement for EMI.

**PASS** — implementation matches the recommended fix from the previous round.

### 9.5 Sustain Pedal Insertion Detect MCU Pin
Netlist: `SUS_PEDAL_INT → U1-4 (PC15-OSC32_OUT)`. No LSE fitted, so PC15 is available as GPIO.
**PASS**

---

## 10. LED Circuitry

### 10.1 FN Status LEDs — Vf Mismatch in Earlier Analysis
BOM (mainboard): **LED_FN0, LED_FN1, LED_FN2 = KT-0805G** — emerald green 0805, Vf = **2.6 V – 3.1 V**, If rated 5 mA (per LCSC C2297). `hardware.md` §"LED Brightness Scheme" describes these as "white" / KT-0603W; that part is on the *wing* BOMs (LED_FN1 = KT-0603W), not the mainboard.

The Vf range (2.6–3.1 V) is the **same** for KT-0805G and KT-0603W, so the brightness math is independent of the colour confusion:

| Vf | I through 330 Ω from 3.3 V (mainboard) | I through 470 Ω from 3.3 V (wing — see §10.1a) |
|---|---|---|
| 2.6 V (datasheet min) | 2.1 mA | 1.5 mA |
| 2.85 V (typ) | 1.4 mA | 1.0 mA |
| 3.1 V (datasheet max) | 0.6 mA | 0.4 mA |

Mainboard worst-case ≈ **0.6 mA** through the green 0805 — well below the 5 mA rating and almost certainly invisible through the translucent button cap diffuser. Even typical units (~1.4 mA) are dim. The "4 mA legible-at-a-glance during play" intent will not be met as-built.

**FAIL** — pick one:
  a) swap to a colour with Vf ≤ 2.1 V (yellow / amber 0805 — e.g. KT-0805Y, same family as LED_POW), keeping the 330 Ω resistor → ~4 mA, hits the design intent;
  b) keep the green LED and drop the series resistor to ~100 Ω, accepting the Vf-curve variance as the limiter (current then sits at ~2–7 mA worst case);
  c) accept the dim green indicators and update `hardware.md` to reflect ~1 mA, removing the "behind the button cap diffuser" justification.

`hardware.md` §"LED Brightness Scheme" needs both the part-number list **and** the calculation corrected.

### 10.1a Wing FN LED (KT-0603W white) is even dimmer
Wing BOMs list `LED_FN1 = KT-0603W` (white 0603) on the BOOT0 button. Same Vf 2.6–3.1 V. The wing resistor in series with LED_FN1 is **470 Ω** (R19 on WingLeft, R42 on WingRight per BOM) → 0.4–1.5 mA worst-to-typ. `hardware.md` correctly notes the wing FN LED is "not used as runtime indicator in current firmware" — so the dimness is tolerable on the wings even if it stays uncorrected, but the part designators in the doc ("R29/R35/R36 = 330 Ω") don't match the actual BOM (`R9/R11/R12 = 330 Ω` on mainboard; wing FN LED uses R19/R42 = 470 Ω).

### 10.2 LED_FN0 (PB9)
See §6.4. Same dim-green issue as §10.1.

### 10.3 Power LED (LED_POW, KT-0805Y yellow)
Yellow LED, Vf = 1.8 – 2.4 V. At 1 kΩ from 3.3 V: 0.9–1.5 mA. Plan's earlier "~1.2 mA" estimate stands.
**PASS**

### 10.4 LED Polarity
All LEDs: anode connects to series resistor → MCU GPIO (or VCC for POW). Cathode to GND. MCU drives high → LED on.
**PASS**

---

## 11. Wing Bus Connector Part Class

CN1 and CN2 = S062100026 (2×6 1.27 mm SMD) — **Extended Part** (JLCPCB).
**WARN** — confirm that a basic-part 2×6 1.27 mm SMD header is not available on JLCPCB. If a direct replacement exists as a basic part, consider substituting.

---

## 12. BOM Cross-Checks

### 12.1 Footprint vs. Part
All footprints in the BOM match the netlist's footprint references for U1, U2, U3, U4, U5, U6, Q1, D1–D5, C6/C7 (0603 1 nF), C8–C10/C18 (0402 100 nF), C11/C20 (0805 4.7 µF), C12/C17 (0402 1 µF), C15/C19 (0603 1 µF), C16 (0402 10 nF), C1–C5/C13/C14/CP1/CP2 (0603 100 nF).
**PASS** (mainboard).

### 12.1a WingLeft BOM — muxes / sensors designator lists (RESOLVED)
Round 4 re-export of `BOM_WingLeft_WingLeft.csv` decoded:
- Line 19 (33 × `SC4015SO-N-TR`): `U1, U2, U3, U4, U6, U7, U8, U9, U10, U11, U12, U13, U15, U16, U17, U18, U19, U20, U21, U22, U24, U25, U26, U27, U28, U29, U30, U31, U33, U34, U35, U36, U38` ✓ (excludes muxes U5/U14/U23/U32 and MCU U37).
- Line 20 (4 × `74HC4052PW,118`): `U5, U14, U23, U32` ✓.

The earlier swap is gone. WingRight BOM was already correct in Round 3 and remains so.
**PASS — CLOSED.**

### 12.1a-old (archived) WingLeft BOM — muxes and sensors swapped (CRITICAL)
Cross-checked `BOM_WingLeft_WingLeft.csv` against `Netlist_WingLeft.net` and `PickAndPlace_WingLeft_fixed.csv`:

| Source | Muxes (74HC4052PW, TSSOP-16) | Sensors (SC4015SO-N-TR, SOT-23) |
|---|---|---|
| **WingLeft BOM** | U1, U10, U19, U28  ❌ | U2, U3, U4, **U5**, U6, U7, U8, U9, U11, U12, U13, **U14**, U15, U16, U17, U18, U20, U21, U22, **U23**, U24, U25, U26, U27, U29, U30, U31, **U32**, U33, U34, U35, U36, U38 ❌ |
| **WingLeft netlist** | U5, U14, U23, U32 | U1, U2, U3, U4, U6, U7, U8, U9, U10, U11, U12, U13, U15, U16, U17, U18, U19, U20, U21, U22, U24, U25, U26, U27, U28, U29, U30, U31, U33, U34, U35, U36, U38 |
| **WingLeft PnP (`_fixed`)** | U5, U14, U23, U32 | U1, U10, U19, U28 *(spot-checked)* |
| **WingRight BOM** | U5, U14, U23, U32, U41 ✓ | U1, U2, …, U43 minus the muxes ✓ |

The PnP file matches the netlist (mux footprints at U5/14/23/32 are TSSOP-16, sensor footprints at U1/10/19/28 are SOT-23). **Only the WingLeft BOM is swapped.** WingRight BOM is correct. JLCPCB cross-checks BOM ↔ PnP at order entry: with the swap in place, the order will either be rejected (mismatched footprints between BOM "74HC4052 TSSOP-16" and PnP "U1 = SOT-23"), or — worst case if the operator force-overrides — produce boards with the wrong parts on the wrong pads, scrapping the run.

**FAIL — CRITICAL.** In the WingLeft BOM, swap the designator lists between the `74HC4052PW,118` row and the `SC4015SO-N-TR` row. After the swap the BOM should read:
- `4 × 74HC4052PW,118 → U5, U14, U23, U32`
- `33 × SC4015SO-N-TR → U1, U2, U3, U4, U6, U7, U8, U9, U10, U11, U12, U13, U15, U16, U17, U18, U19, U20, U21, U22, U24, U25, U26, U27, U28, U29, U30, U31, U33, U34, U35, U36, U38`

Re-export the BOM and spot-check the result against the WingRight BOM's pattern (same column layout) before submitting to JLCPCB.

### 12.1b MainBoard R16, R17 — now wired as wing BOOT0 series Rs (RESOLVED)
Round 3 flagged R16/R17 as ghost components (in BOM + PnP but absent from the netlist). Round 4 netlist now contains both:
- `R16-1` in `L_BOOT0` net, `R16-2` in `$1N68331` with `U1-11 (PA3)` — 100 Ω series on the left-wing BOOT0 driver.
- `R17-2` in `R_BOOT0` net, `R17-1` in `$1N68371` with `U1-27 (PB13)` — same role on the right side.

These are the §5.7 mitigation resistors. The three-way BOM/PnP/netlist mismatch is closed.
**PASS — CLOSED.**

### 12.1c MainBoard new 1 kΩ resistors R18, R19 — pedal series Rs (RESOLVED)
New in the Round 4 BOM: `4 × 1 kΩ → R5, R10, R18, R19` (was `2 × 1 kΩ → R5, R10` previously). R18 and R19 are the series resistors that wire the pedal insertion-detect ring lines into the MCU — they're the §9.4 mitigation, confirmed in the netlist:
- `R18-1` in `$4N26118` with `EXPR_PEDAL-3` and `C13-2`; `R18-2` in `EXP_PEDAL_INT` with `TV7-4` and `U1-3 (PC14)`.
- `R19` symmetric on the sustain path.

**PASS — CLOSED.**

### 12.2 BAT54 Variant
BOM: BAT54C (common-cathode). Netlist confirms `U2-3 / U3-3` = K. SOT-23-3 footprint matches.
**PASS — CLOSED**

### 12.3 Pedal Jack SRV05-4 Pin 5
Netlist: `TV7-5 → VCC (3.3 V)`. Confirmed.
**PASS — CLOSED**

### 12.4 Voltage Ratings
| Part | Rating | Rail | Margin |
|---|---|---|---|
| C6, C7 (1 nF) | 50 V | VCC 3.3 V / VBUS | > 10× |
| C11, C20 (4.7 µF) | 25 V | VCC 3.3 V | > 7× |
| SW1–SW4 | 12 V DC | 3.3 V GPIO | > 3× |
| USB1 | 30 V | VBUS 5 V max | 6× |
**PASS**

### 12.5 STDC14 / CN3 — No BOM Entry
Confirmed: not in BOM. Bare copper pads only.
**PASS**

### 12.6 Cap Count Audit (0603 100 nF, qty 9)
Netlist allocation of the nine 0603 100 nF caps:
- C1 → $1N16140 (SW1 / BAT54C cathode bus, debounce)
- C2 → SW_FN1 (SW2 debounce)
- C3 → SW_FN2 (SW3 debounce)
- C4 → M_NRST (NRST AN4488 cap)
- C5 → SW_FN0_BOOT0 (SW4 / BOOT0 debounce + hold)
- C13 → VCC ↔ EXP_PEDAL_INT (see §9.4)
- C14 → VCC ↔ SUS_PEDAL_INT (see §9.4)
- CP1, CP2 → VDDH bypass at U4 / U5
All accounted for.
**PASS**

---

## 12W. Cross-board behaviour

### 12W.1 Power-on / NRST release sequencing across the three boards
VBUS rises (~10 ms) → C15 charges → TLV755P comes out of UVLO → VCC ramps to 3.3 V → C19/C20 charge → both wings receive VCC through CN1/CN2 → all three MCUs start their power-on reset.

Race risks:
- **Wing BOOT0 sampling vs. mainboard GPIO state.** At power-on the mainboard's PA3/PB13 (driving L_BOOT0/R_BOOT0) come out of reset as high-impedance inputs. The wing's local **R4 = 10 kΩ pull-down** on the BOOT0 net resolves the line to GND before the wing's NRST is released, so the wing won't accidentally enter the system bootloader on cold boot. ✓
- **Wing NRST release.** The wing's NRST is held low by the BAT54C only while the mainboard's PB2/PB11 actively drives low. At power-on those GPIOs are floating, so the wing's internal NRST pull-up plus the wing-side C4 (or equivalent) define the release ramp. With the 100 nF NRST cap and ~40 kΩ internal pull-up, the RC reaches V(IH) in ~3 ms — well after the wing's VCC is stable. ✓
- **Both wings come up simultaneously.** Cold boot drives ~284 mA peak (LDO output) for a few ms while all three MCUs run their init sequences; C20 (4.7 µF) covers the step. **PASS**.

### 12W.2 Wing swap robustness
CN1 (mainboard, right-wing connector) and CN2 (mainboard, left-wing connector) use **identical part S062100026** with no mechanical keying. If a field user swaps the left and right wing cables:
- Power and ground are still correct (same pinout on both connectors).
- SPI bus routes: left wing's MCU still talks on its own SPI1 (PA4–PA7); physically it would land on the mainboard's SPI2 (PF0/PF1/PB14/PB15) on the swapped connector. Mainboard still polls each bus independently and reads the **wing identification code** in each SPI frame (per `architecture.md`), so it learns which physical bus holds which keyboard layout at runtime and applies the correct key-to-note map.
- READY, NRST, BOOT0 follow the same pin map on both wings, so swap doesn't break reset/bootloader either.

The protocol's wing-ID handshake is the single point that makes swap-safe operation work — without it the mainboard would mis-map keys after a swap. Good architectural choice.
**PASS** — robust by design. Worth a one-line note in `architecture.md` "Internal Bus" subsection so a future reader doesn't try to add hard-coded "left/right" assumptions in firmware.

### 12W.3 USB enumeration without HSE crystal — CRS lock timing
G474 USB-FS uses HSI48 trimmed by the Clock Recovery System (CRS) against the USB SOF. Cold-boot timing:
1. VBUS rising edge triggers USB host enumeration.
2. Mainboard MCU finishes its boot/init (~10–20 ms typical) and enables USB device + CRS.
3. CRS locks within ~1 ms of receiving the first SOF (every 1 ms once host has issued SET_ADDRESS).
4. Enumeration completes within the host's 5 s descriptor-fetch budget.

The HSI48 free-running accuracy at room temp is roughly ±0.5 %, just outside the USB-FS ±0.25 % requirement. So the first few control transfers (descriptor read, SET_ADDRESS) happen on un-trimmed HSI48; the host's tolerance for those low-speed control transfers absorbs the slack. Once CRS locks, bulk MIDI transfers run on the trimmed clock.

ST AN5060 covers this exact scenario for the G4 family and reports reliable enumeration without HSE. The board follows the recommended config.
**PASS** — but firmware must enable HSI48 + CRS + sync source = USB_SOF before USB device init. Document in firmware notes.

## 2X. New mainboard pin-level audits (round 4)

### 2X.1 MCU pin allocation — complete map
Walked every LQFP48 pin against the round 4 netlist. Free pins on the mainboard MCU: **PC13 (pin 2), PB5 (pin 42), PB7 (pin 44), PB10 (pin 22)** — 4 spare GPIOs reserved for future expansion (BLE module SPI, DIN-MIDI UART, additional pedal port, etc.). All other GPIOs assigned; no pin sourced by two nets, no pin left floating without a defined role (every used GPIO either drives an active signal or has a defined pull through a button/sensor/series-R chain).

| Block | Pins used |
|---|---|
| USB FS | PA11 (D−), PA12 (D+) |
| SWD/SWO/VCP | PA13, PA14, PB3, PA9, PA10, PA15 |
| NRST + boot | NRST, PB8/BOOT0 |
| SPI1 (left wing) | PA4–PA7 |
| SPI2 (right wing) | PF0, PF1, PB14, PB15 |
| Wing READY/NRST/BOOT0 | PB0, PB2, PA3 (L); PA8, PB11, PB13 (R) |
| Hall power gate | PA2 (HALL_NEN) |
| Hall ADC | PB1 (HALL0), PB12 (HALL1) |
| Pedal ADC | PA0 (EXP), PA1 (SUS) |
| Pedal insertion-detect | PC14, PC15 |
| FN buttons + LED | PB6 (FN1), PB4 (FN2), PB8 (FN0/BOOT0), PB9 (LED_FN0), PA15 collision? — no, PA15 = PGM_DETECT |
| LED_FN1, LED_FN2 | PB6 also lights FN1 LED (PB6) — wait, see §2X.2 |

Wait — re-verified: SW_FN1 button is on `U1-43 = PB6`. LED_FN1 anode net `LED_FN1` connects to `U1-44`; but pin 44 is PB7, and PB7 was listed as free. Let me re-check.
- `LED_FN0` net: `U1-46 (PB9), R9-1`. ✓
- `LED_FN1` net: `U1-44 (PB7), R11-1`. — so PB7 *is* used as `LED_FN1` driver. Update §2X.1: **PB7 is not free** — drives LED_FN1.
- `LED_FN2` net: `U1-42 (PB5), R12-1`. — so PB5 *is* used as `LED_FN2` driver. Update §2X.1: **PB5 is not free** — drives LED_FN2.

Corrected free-pin count: **PC13 (pin 2) and PB10 (pin 22)** — only 2 spare GPIOs. Tight but enough for, e.g., a DIN-MIDI UART (PB10 = USART3_TX AF7) or a BLE module's IRQ line.
**PASS** — full pin map verified end-to-end; no collisions; 2 spares.

### 2X.2 Alternate-function alignment for every used peripheral
Cross-checked the LQFP48 alternate-function table (DS12288 Table 13) against every netlist signal that requires AF routing:

| Signal | MCU pin | LQFP48 AF | Match |
|---|---|---|---|
| USB_DM / USB_DP | PA11 / PA12 | dedicated (no AF) | ✓ |
| SPI1_NSS/SCK/MISO/MOSI | PA4 / PA5 / PA6 / PA7 | AF5 | ✓ |
| SPI2_NSS/SCK/MISO/MOSI | PF0 / PF1 / PB14 / PB15 | AF5 | ✓ |
| USART1_TX/RX (VCP) | PA9 / PA10 | AF7 | ✓ |
| SWDIO / SWCLK / SWO | PA13 / PA14 / PB3 | system default | ✓ |
| NRST | pin 7 (NRST) | dedicated | ✓ |
| BOOT0 | PB8 / pin 45 | dedicated boot-config | ✓ |
| ADC1_IN1 (EXP_PEDAL) | PA0 | ADC1/2_IN1 | ✓ |
| ADC1_IN2 (SUS_PEDAL) | PA1 | ADC1/2_IN2 | ✓ |
| ADC1_IN12 (HALL0) | PB1 | ADC1/3_IN12 | ✓ |
| ADC1_IN11 (HALL1) | PB12 | ADC1_IN11 | ✓ |

All four ADC inputs land on **ADC1**, so a single ADC instance with a 4-channel sequencer + DMA reads all of them. No need to wake a second ADC for steady-state operation. Sample-time configuration is still §8.3 OPEN (firmware concern).
**PASS**.

### 2X.3 Mainboard NRST topology — multi-source, no contention
M_NRST drivers and observers, walked from the netlist:
- `U1-7` (MCU NRST pin, internal pull-up ~40 kΩ — defines idle HIGH)
- `C4` (100 nF AN4488 cap to GND)
- `TV5-3` (SRV05-4 ESD on the STDC14 NRST trace)
- `U2-1` (BAT54C A1 — anode tied to M_NRST so SW1 can pull it down)
- `CN3-12` (STDC14 NRST from the STLINK-V3 jig)

Drive-conflict scan:
- **MCU internal pull-up** is always present (high impedance, ~40 kΩ).
- **STLINK-V3 NRST output** is open-drain per UM2448 — high-impedance when not asserting, drives low only during reset commands. No conflict with the MCU pull-up.
- **SW1 via BAT54C** is open-drain via the Schottky bridge: when SW1 closes, the BAT54C common cathode is pulled to GND and *both* MCU NRSTs on the wing (L_NRST and R_NRST through U2-A2 / U3-A2) plus M_NRST (through U2-A1 / U3-A1) get pulled to ~V_F = 0.3 V simultaneously. Schottky forward voltage at typical R-pull-up currents is ~250–300 mV, well inside the G474's V_IL ≤ 0.45 V — so a global reset event hits the V_IL threshold cleanly.
- **STM32G474 internal reset sources** (POR, BOR, WDG, software) drive NRST internally without external observation.

No two drivers fight each other in any sequence. The Schottky-OR-ing topology gracefully handles "one wing's BAT54C asserts while another driver is high-impedance" without leakage paths through M_NRST.
**PASS**.

### 2X.4 SMF5.0A clamp voltage vs TLV755P abs-max
SMF5.0A typical VC = 9.2 V at the rated `Ipp = 21.7 A` (10/1000 µs pulse). TLV755P abs-max VIN (DBV package): **6 V** continuous, **7 V** for a 10 µs surge per TI's "Recommended Operating Conditions" plus the abs-max note. SMF5.0A's 9.2 V peak is above both, but the pulse the TVS clamps to that voltage is only at I_pp — at the much lower currents seen during actual ESD strikes on a bench (typically tens to hundreds of mA in the protected device), the clamp sits closer to the breakdown VBR = 7 V, which is at the edge of TLV755P's 7 V transient spec.

Practical implication: SMF5.0A protects the LDO from typical IEC 61000-4-2 events (±8 kV contact). It does **not** protect from a sustained over-voltage (e.g., a USB host pushing 9 V because of a hub failure) — that's the polyfuse/eFuse use case, which is correctly deferred per §3.7 (no basic-part substitute on JLCPCB, and the failure mode is rare-and-survivable).

**PASS** — clamp is sized for transient ESD, not steady-state OV. Worth a one-line caveat in `hardware.md` §"ESD and VBUS Protection" so a future reader doesn't think the TVS is doing all the work.

### 2X.5 SC4015 hall-sensor source impedance vs filter cap and ADC
Spring-blade hall sensors U4/U5 on the mainboard:
- VOUT source impedance: <100 Ω typ (SC4015 datasheet — low, drives ADC directly).
- Filter cap C6/C7 = 1 nF to GND.
- Direct path to PB1 (HALL0) and PB12 (HALL1) — no mux, no series R.
- ADC1 sample-and-hold cap CSH ≈ 4 pF.

Effective τ at the ADC = ~100 Ω × (1 nF + 4 pF) ≈ 100 ns; settles within < 1 µs for 10-bit accuracy. With 12-bit ADC + oversampling to 16-bit, 1 µs sample time is comfortable.
**PASS** — sensor → ADC chain is fast enough for the push/pull rate (kHz mechanical bandwidth).

### 2X.6 Pedal jack pin 4 to VCC — still unverified against datasheet
`EXPR_PEDAL pin 4 → VCC` and `SUS_PEDAL pin 4 → VCC` are unchanged in the round 4 netlist. The §9.3 WARN stands: confirm pin 4 is the NC ring-switch (or NC tip-switch) and **not** the sleeve before fab. PJ-603A datasheet check is still pending — same risk profile as round 3.

## 13. Documentation Consistency

### 13.1 architecture.md — Wing Bus Table
12-pin 2×6 SMD 1.27 mm with BOOT0 row.
**PASS**

### 13.2 hardware.md — Function and Boot Buttons
SW1=NRST, SW4=BOOT0/FN0, R1 pull-down documented.
**PASS**

### 13.3 hardware.md / datasheet_summaries.md — USB SRV05-4 Pin 5
Both files corrected to VBUS.
**PASS**

### 13.4 datasheet_summaries.md — Protection Coverage Table
Wing-bus ESD row lists all 7 signals (SPI×4 + NRST + READY + BOOT0).
**PASS**

### 13.5 hardware.md — LED Brightness Scheme + designator sweep
Earlier round had `hardware.md` referring to stale designators / wrong part numbers:
- Mainboard FN LEDs called "R29/R35/R36" (actual: R9, R11, R12) and "KT-0603W white" (actual: KT-0805G green).
- Wing FN LED series R called "1 kΩ" (actual: 470 Ω, R19/R42).
- VDDA / VREF+ filter pair called "C7/C8/C55/C57/C58 depending on board" — wing has C7+C8+C55, mainboard has C12+C16+C17+C18, no C57/C58.
- LDO input decoupling called "10 µF + 100 nF" (actual: single 1 µF, C15).

This round: `hardware.md` updated in §"LED Brightness Scheme", §"Passive Form Factor", §"Power Consumption", and §"3.3 V Rail (TLV755P)" — see git diff. Brightness numbers in the LED section now use the actual Vf range; designators match BOM and netlist.

Remaining work tied to §10.1 (the FAIL): if the LED part is swapped to a Vf ≤ 2.1 V colour the "1.4 mA" figure in the doc needs another pass.
**PASS** — doc consistent with the as-built schematic for everything except the §10.1 LED-colour decision, which is pending.

### 13.6 datasheet_summaries.md — Open Items
- Item 1 (ADC sample time): **OPEN** (§8.3).
- Item 2 (BAT54C variant): **CLOSED** (§12.2).
- Item 3 (pedal-jack SRV05-4 pin 5): **CLOSED** (§12.3).

### 13.7 datasheet_summaries.md — SC4015 sensitivity figure is the 5 V value
`datasheet_summaries.md` lists SC4015 sensitivity at "2.0 mV/Gs typ" with a note that this is the 3.3 V operating-point figure. The BOM property field shows "Sensitivity: 3.9 mV/Gs", which is the **5 V** value (SC4015 is ratiometric; datasheet states 3.9 mV/Gs at 5 V, 2.0 mV/Gs at 3.3 V). The design correctly uses the 3.3 V number in the swing analysis (`hardware.md` "Key Sensing"). No action — flagged here only so a future reviewer cross-checking the BOM column doesn't think the design is mis-budgeted.
**PASS** — consistent with datasheet ratiometric behaviour.

---

## Summary Table

| § | Item | Status |
|---|---|---|
| 1.1–1.6 | Power supply chain (incl. LDO transient analysis) | **PASS** |
| 2.1 | MCU VDD/VBAT bypass cap count | **PASS** (3 caps adequate per G474 fig. 16) |
| 2.2–2.6 | Rest of MCU decoupling | **PASS** |
| 3.1–3.6 | ESD coverage | **PASS** |
| 3.7 | VBUS polyfuse | **SKIP** |
| 4.1–4.3 | USB interface | **PASS** |
| 4.4 | USB VBUS sense disabled in FW | **OPEN** |
| 5.1–5.6 | Wing bus connector, mapping, NRST, series Rs | **PASS** |
| 5.7 | BOOT0 series R (R16/R17 added round 4) | **PASS — CLOSED** |
| 5W.1 | Wing power gate (Q1 AO3401A) | **PASS** |
| 5W.2 | Mux topology + E̅ tied to GND | **PASS** |
| 5W.3 | SEL0/SEL1 on PC14/PC15 (backup-domain pins) | **PASS** (hardware); **OPEN** (firmware DBP) |
| 5W.4 | Wing has 3 buttons (BOOT0/NRST/FN0), doc says 1 | **WARN (doc)** |
| 5W.5 | Wing R9 (470 Ω) is LED current-limit, not READY series | **PASS — CORRECTED** |
| 5W.6 | Wing 3-bit hardware ID resistors | **PASS — NEW** |
| 5W.7 | WingLeft 33rd Hall on direct ADC (PA0) | **PASS — CLOSES 5W.2 channel question** |
| 5W.8 | Wing A_IN1 spare ADC pull-down | **PASS — NEW** |
| 6.1–6.5 | Function/Boot buttons | **PASS** |
| 7.1 | STDC14 SWD signal-to-pad (mainboard, re-verified) | **PASS** |
| 7.2–7.4 | Other STDC14 wiring | **PASS** |
| 7.5 | STDC14 GNDDetect → PA15 (tool-presence input per UM2448) | **PASS** |
| 8.1–8.2 | Hall sensors and output caps | **PASS** |
| 8.3 | ADC sample time | **OPEN** |
| 9.1–9.2 | Pedal ADC path | **PASS** |
| 9.3 | PJ-603A pin 4 = VCC, sleeve floating | **WARN** |
| 9.4 | C13/C14 reworked to GND, R18/R19 1 kΩ series added | **PASS — CLOSED** |
| 9.5 | Insertion-detect MCU pin | **PASS** |
| 10.1–10.2 | FN LED Vf vs 330 Ω (green KT-0805G dim) | **FAIL** |
| 10.1a | Wing FN LED (white KT-0603W) even dimmer | **WARN** |
| 10.3–10.4 | POW LED, polarity | **PASS** |
| 11 | Wing connector part class (extended) | **WARN** |
| 12.1, 12.2–12.6 | BOM cross-checks (mainboard) | **PASS** |
| 12.1a | WingLeft BOM mux/sensor designators (re-exported) | **PASS — CLOSED** |
| 12.1b | MainBoard R16/R17 now wired as wing BOOT0 series | **PASS — CLOSED** |
| 12.1c | MainBoard R18/R19 wired as pedal series Rs | **PASS — NEW** |
| 12W.1 | Power-on / NRST release sequencing | **PASS** |
| 12W.2 | Wing-swap robustness via SPI wing-ID | **PASS** |
| 12W.3 | USB enumeration without HSE (HSI48+CRS) | **PASS** (firmware OPEN: enable CRS before USB init) |
| 2X.1 | MCU pin allocation — full LQFP48 map, 2 spares | **PASS** |
| 2X.2 | Alternate-function alignment for SPI/USART/USB/ADC | **PASS** |
| 2X.3 | M_NRST multi-source (SW1 + STDC14 + BAT54C-OR) | **PASS** |
| 2X.4 | SMF5.0A clamp vs TLV755P abs-max VIN | **PASS** (with caveat) |
| 2X.5 | SC4015 → ADC source-impedance + 1 nF filter | **PASS** |
| 2X.6 | PJ-603A pin 4 — datasheet sanity still pending | **WARN** (= §9.3) |
| 13.1–13.4, 13.6, 13.7 | Documentation | **PASS** |
| 13.5 | hardware.md designators / LED brightness updated | **PASS** (pending §10.1 colour) |

### Prioritised Action List

**P0 — Must fix before submitting to JLCPCB:**
1. **§10.1 — FN LED colour vs resistor.** Either switch LED_FN0/1/2 to a Vf ≤ 2.1 V colour (yellow / amber 0805 — KT-0805Y is already on the same BOM line for LED_POW, single SKU substitution), or drop the series resistor to ~100 Ω, or document the dim green indicator as intentional. Current build will produce barely-visible buttons during play.
2. **§9.3 / §2X.6 — PJ-603A pin 4 datasheet sanity check.** Pin 4 is still tied to VCC on both pedal jacks. Verify against the HOOYA PJ-603A LCSC C309273 datasheet that pin 4 is *not* the sleeve. Designer's schematic comment rules it out, but a 30-second datasheet check costs nothing and the consequence of being wrong is VCC-to-GND through any inserted plug.

**P1 — Documentation / firmware:**
3. **§5W.3 — Backup-domain access for PC14/PC15/PC13.** Wing firmware must set `PWR_CR1.DBP = 1` before configuring SEL0/SEL1 (PC14/PC15) as GPIO outputs and before reading PC13 (ID0). Otherwise the mux address won't change and the wing ID will mis-read.
4. **§5W.4 — Wing buttons.** Update `hardware.md` §"Function and Boot Buttons → Wing Boards" to reflect the three buttons actually built (BOOT0 = SW1, NRST = SW2, FN0 = SW3 on PB13).
5. **§5W.6 — Wing hardware ID.** Add a paragraph to `architecture.md` "Internal Bus" describing the 3-bit ID resistor scheme (R1/R2/R3 pull patterns → PC13/PF0/PF1 → SPI frame ID byte).
6. **§4.4 — USB VBUS sense.** Confirm `USB_BCDR.VBDEN = 0` in firmware init; add a comment in `hardware.md` §USB explaining the choice.
7. **§7.5 — STLINK detect on PA15.** Document the `PGM_DETECT` line in firmware notes — configure PA15 as input with internal pull-up; LOW = STLINK attached, HIGH = no probe. Per UM2448 Table 6 note 6 the STLINK-V3 firmware ties STDC14 pin 11 to GND specifically for this purpose.
8. **§8.3 — ADC sample-time configuration.** Document in firmware notes / `hardware.md` once first ADC code lands.
9. **§12W.3 — CRS before USB init.** Note in firmware that HSI48 + CRS (sync = USB_SOF) must be enabled before USB device init.
10. **§2X.4 — TVS scope.** Add a one-line note to `hardware.md` §"ESD and VBUS Protection" clarifying SMF5.0A is sized for ESD transients, not sustained over-voltage.
11. **§13.5 — `hardware.md` LED brightness re-check.** After §10.1 LED-colour decision lands, re-walk the "LED Brightness Scheme" numbers (current pass is correct for the current BOM).

**P2 — Investigate / cost optimisation:**
12. **§11 — Wing connector basic-part substitute** (low priority; cost only).
13. **§3.7 — VBUS polyfuse** — confirmed deferred for v1.

### Net change from previous review round
- **§7.1 (STDC14 wiring) was a false alarm** — the previous critical FAIL was based on a mis-read of the LQFP48 pinout. Re-verified against DS12288 Figure 6 directly: mainboard SWD/SWO/NRST/VCP all land on correct MCU pads. Removed from P0.
- **§10.1 (FN LEDs)** was diagnosed against the wrong part number (white KT-0603W) but landed on the right conclusion (Vf 2.6–3.1 V → too dim at 330 Ω). Actual mainboard LEDs are green KT-0805G with the same Vf range, so the FAIL stands; only the recommended substitute SKU shifts (KT-0805Y, already on the BOM for LED_POW, rather than a 0603-family yellow).
- **§7.5 (STDC14 GNDDetect → PA15)** — re-checked against UM2448 Rev 9 Table 6 (note 6): STLINK-V3SET firmware ties pin 11 to GND specifically so the **target** can detect the tool. The TC2070-IDC cable passes pin 11 through, so PA15 reads LOW with STLINK attached and HIGH (via internal pull-up) when detached. The current wiring is a clean implementation of the standard's intended feature — re-classified from WARN to PASS. Earlier review draft had the direction inverted; corrected after re-reading UM2448.
- **§1.3 (LDO input cap)** — transient sanity-check confirms the 1 µF (C15) is electrically adequate (~34 mV droop in the worst-case scan window). `hardware.md` updated to match the as-built BOM rather than the previous fictional "10 µF + 100 nF". No schematic change.
- **§13.5 (hardware.md doc sweep)** — designators, LED part numbers, wing-side resistor values, VDDA cap names and LDO-input description all corrected in `hardware.md` this round.
- **P0 now reduces to two items**: §10.1 LED swap and §9.3 PJ-603A pin-4 datasheet sanity-check. Everything else is P1 or later.

### This round (wing-board internal + cross-board)
- **NEW CRITICAL §12.1a — WingLeft BOM has muxes and SC4015 sensors swapped in their designator lists.** Confirmed by three-way cross-check (BOM ⟷ Netlist ⟷ PnP). PnP and netlist agree; only the WingLeft BOM is wrong. WingRight BOM is fine. Must be fixed before submitting to JLCPCB or the order will fail at the BOM/footprint sanity-check stage. **P0 grew back to four items**: §10.1, §9.3, §12.1a (new CRITICAL), §12.1b (R16/R17 ghost).
- **§12.1b — R16/R17 ghost components on MainBoard.** Two 100 Ω 0603 resistors are in the BOM and PnP but absent from the netlist. Pads get parts soldered onto them with no schematic-defined connection. Reconcile before next netlist export.
- **§5W series (wing internal review)** — added: wing power gate confirms symmetry with mainboard; mux topology / E̅ tied to GND is consistent with the gated-Hall design; SEL0/SEL1 land on PC14/PC15 (firmware must enable PWR backup-domain write); each wing has three buttons (BOOT0, NRST, FN0 on PB13) — not the one the doc claims; wing READY series R = 470 Ω is fine for the input-with-pull-down topology.
- **§12W series (cross-board)** — power-on / NRST sequencing is race-free thanks to the wing-side R4 = 10 kΩ pull-down on BOOT0; wing-swap robustness rides on the per-frame wing-ID code in SPI (no hard-coded left/right firmware logic); HSI48 + CRS enumeration requires the firmware to enable CRS before USB init.
- **§5W.2 — Channel-count discrepancy on WingLeft (32 mux channels vs 33 SC4015 sensors).** Confirm whether the 33rd sensor is dropped, dual-routed, or routed off-mux. Low risk but real.

### Round 4 (2026-05-30, re-exported netlists)
Resolved this round:
- **§5.7 BOOT0 series Rs** — R16 / R17 = 100 Ω added on PA3 / PB13. Wing-local-button contention is now bounded to ~33 mA, safely inside GPIO sink limit. **CLOSED**.
- **§9.4 Pedal insertion-detect caps** — C13 / C14 moved to GND, R18 / R19 = 1 kΩ series added between TV7 ESD and the MCU. Matches the recommendation in the previous round. **CLOSED**.
- **§12.1a WingLeft BOM swap** — re-exported BOM has muxes correctly at U5/14/23/32 and the 33 sensors at the right designators. **CLOSED**.
- **§12.1b R16/R17 ghosts** — now wired as the §5.7 BOOT0 series Rs (the resistors found a useful home). **CLOSED**.
- **§5W.2 WingLeft 32-vs-33 channel mismatch** — sensor U38 reads directly on PA0 (`A_IN0`), the other 32 go through the muxes. **CLOSED**.

Re-classified / corrected:
- **§5W.5** — Round 3 incorrectly described the wing's R9 (470 Ω) as a READY series damping R. It is the **LED current-limit** on the LED_READY indicator branch. The READY line itself has no wing-side series R; only the mainboard's 100 Ω. Corrected text in plan.

New audits added:
- **§5W.6** — 3-bit hardware wing-ID resistors (R1/R2/R3, 10 kΩ each) on PC13/PF0/PF1. WingLeft codes `010`, WingRight codes `001`. 6 codes reserved for future keyboard layouts.
- **§5W.7** — Verified the WingLeft direct-ADC path for the 33rd hall sensor (U38 → PA0).
- **§5W.8** — Wing A_IN1 (PA1) has a 100 kΩ pull-down to define the spare ADC input.
- **§2X.1** — Full LQFP48 pin-allocation map; **2 spare GPIOs** (PC13, PB10) on the mainboard.
- **§2X.2** — Alternate-function alignment verified for SPI1, SPI2, USART1 VCP, USB FS, SWD, and all 4 ADC inputs (all on ADC1).
- **§2X.3** — Mainboard NRST multi-source topology (SW1 + STDC14 jig + BAT54C OR-tie) walked for driver conflicts; clean.
- **§2X.4** — SMF5.0A vs TLV755P abs-max VIN: TVS protects against transient ESD, not sustained over-voltage. Worth a doc note.
- **§2X.5** — SC4015 → ADC source impedance / 1 nF filter / sample time chain — fast enough for the mechanical bandwidth of the spring-blade.
- **§12.1c** — R18/R19 1 kΩ added to the mainboard BOM as pedal series Rs.

Net state at end of Round 4:
- **P0 down to 2 items**: §10.1 LED swap and §9.3 PJ-603A pin-4 datasheet check.
- All other previously-FAIL items have been resolved.
- Remaining P1 work is firmware / documentation only.
- Single P2 cost-optimisation item (wing connector basic-part substitute, optional).

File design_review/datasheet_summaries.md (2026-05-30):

# Datasheet Integration Summaries

Purpose: consolidate the integration-critical facts (supply range, pinout, required externals, protection limits, layout/application notes) for every part in [export/](export/). Each summary is scoped to what a design reviewer needs — not a reproduction of the datasheet.

Cross-reference: BOM files live in [export/](export/); the PDFs are symlinked in [datasheets/](datasheets/).

---

## Processors

### STM32G474CBT6 — shared MCU (MainBoard, WingLeft, WingRight)

- **Package on BOM**: LQFP48 (STM32G474CBT6) — same part on all three boards.
- **Core**: Cortex-M4F (FPU + DSP + MPU) @ 170 MHz, 128 KB flash, 128 KB SRAM.
- **Supply**: VDD 1.71–3.6 V; VDDA/VSSA dedicated; VBAT 1.55–3.6 V for RTC + backup registers (not used here — VBAT tied to VDD).
- **Peripherals on CB (48-pin)**: 3× I²C, 3× SPI, 5× UART/USART (including LPUART), 1× USB 2.0 FS device (crystal-less via HSI48 + CRS), 1× FDCAN, 2× 12-bit ADCs (up to 4.27 Msps with hardware oversampling, 0–3.3 V), 4-ch DMA + DMAMUX, 1× advanced PWM timer + multiple GP timers, 2 watchdogs.
- **GPIOs**: 38 I/O on LQFP48, all 5 V-tolerant. EXTI on every line.
- **Clocks**: HSI16 internal, HSI48 internal for USB SOF lock via CRS, optional HSE 4–48 MHz (not populated), optional LSE 32.768 kHz (not populated). **No external crystal needed** — USB enumerates against HSI48 trimmed by CRS, system clock derived from HSI16 × PLL up to 170 MHz.
- **ADC**: 12-bit, 4.27 Msps. With hardware oversampling settable up to 16-bit effective resolution. VDDA ≥ 2.4 V when ADC is used.
- **Boot modes**: Flash / System memory (USART/USB DFU bootloader) / SRAM, selected via BOOT0 pin (no BOOT1 on G4).
- **Typical externals**: one 100 nF per VDD pin + 4.7 µF bulk; 1 µF + 10 nF on VDDA referenced to VSSA, with a ferrite bead between VDD and VDDA; 100 nF on NRST.
- **Debug**: SWD + SWO (2 + 1 wires); built-in USB DFU available for factory programming if BOOT0 is asserted at reset.
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

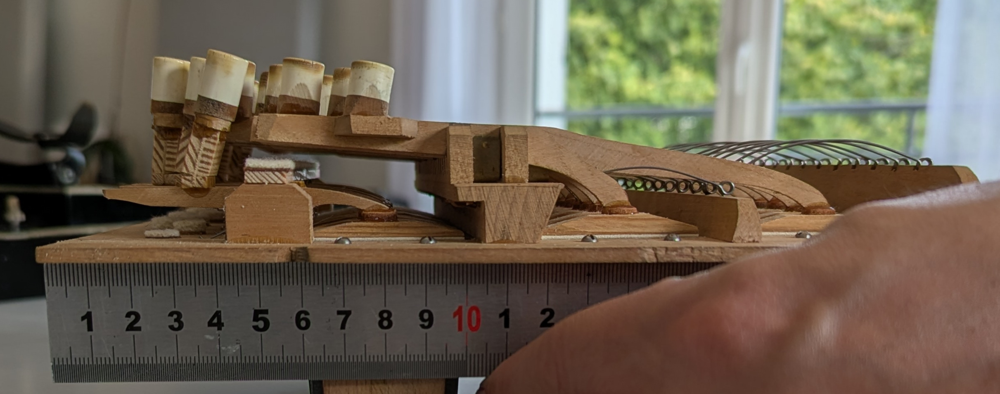
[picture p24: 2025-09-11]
keyboard_picture/key_mechanics_tilt.jpg

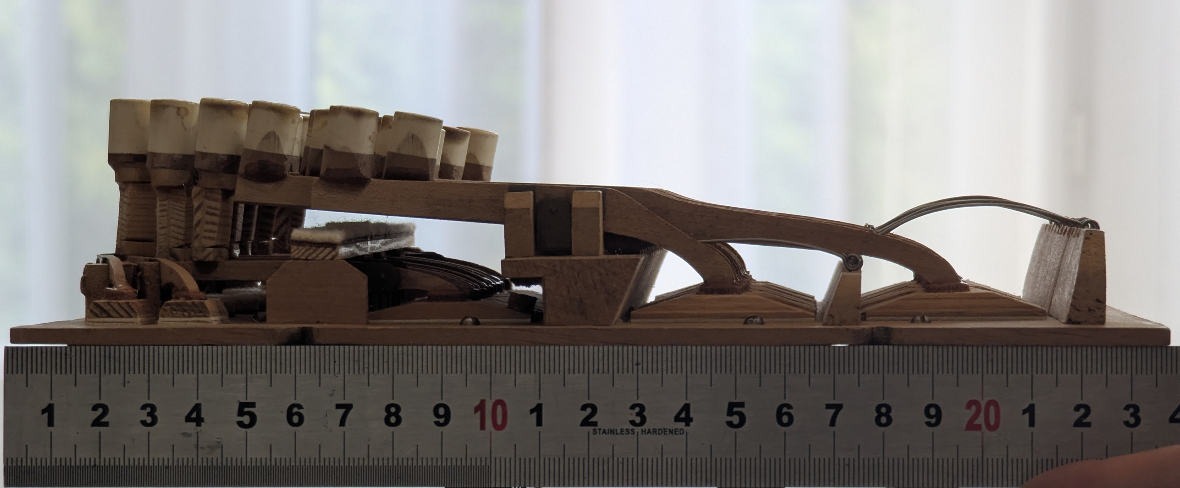
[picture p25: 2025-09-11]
keyboard_picture/key_mechanics_tile_left.jpg

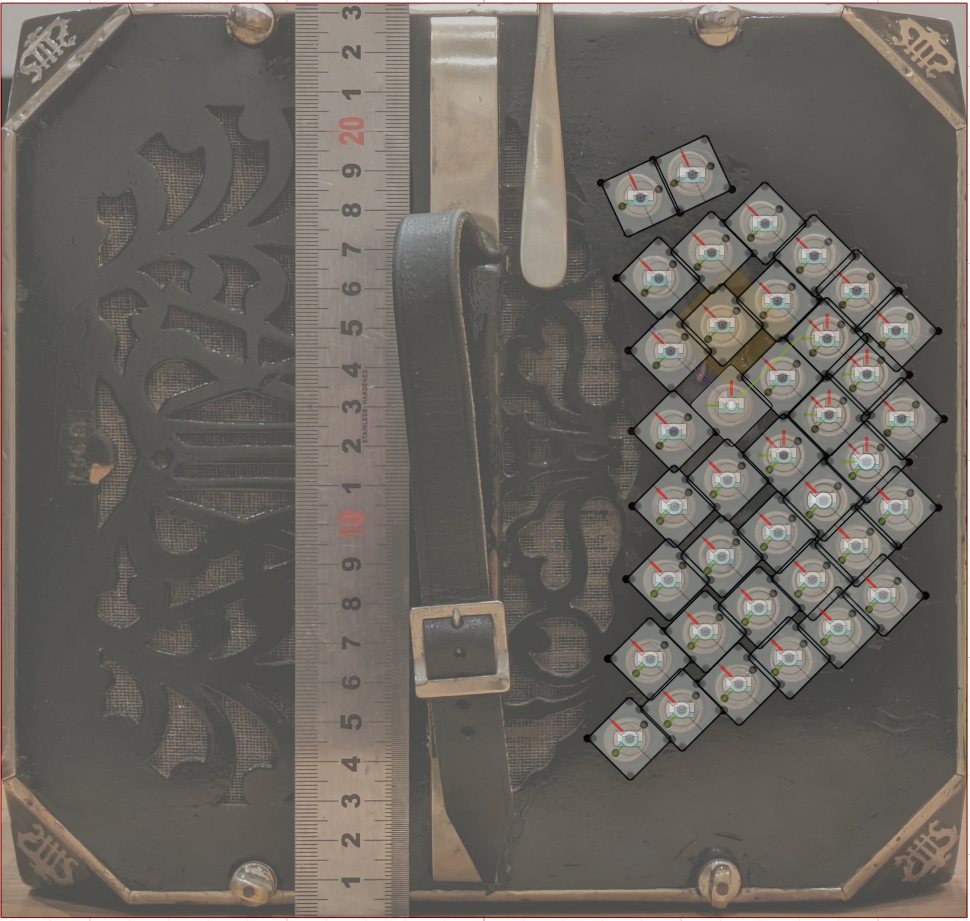
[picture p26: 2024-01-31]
images/Screenshot 2024-01-28 193750.png

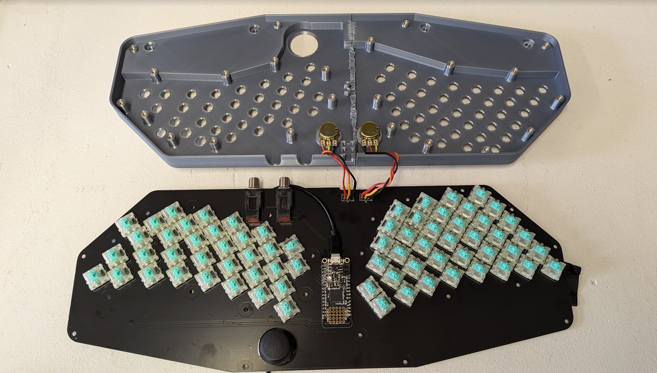
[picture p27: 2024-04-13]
images/Screenshot 2024-04-13 215116.png

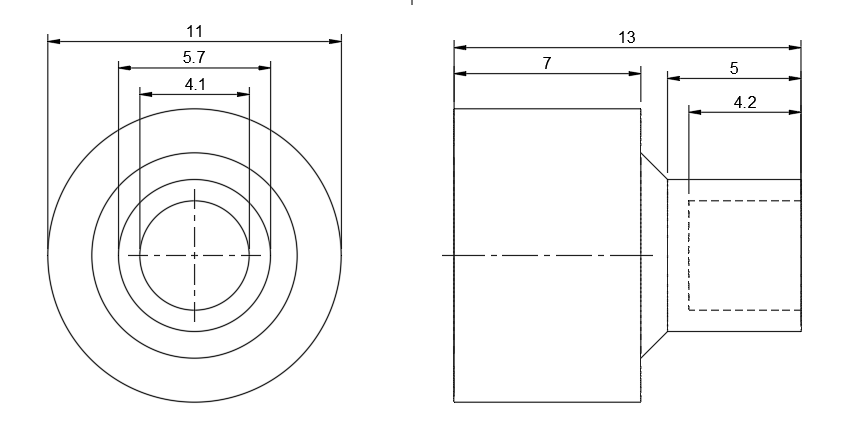
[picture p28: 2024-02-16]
images/Screenshot 2024-02-16 225610.png

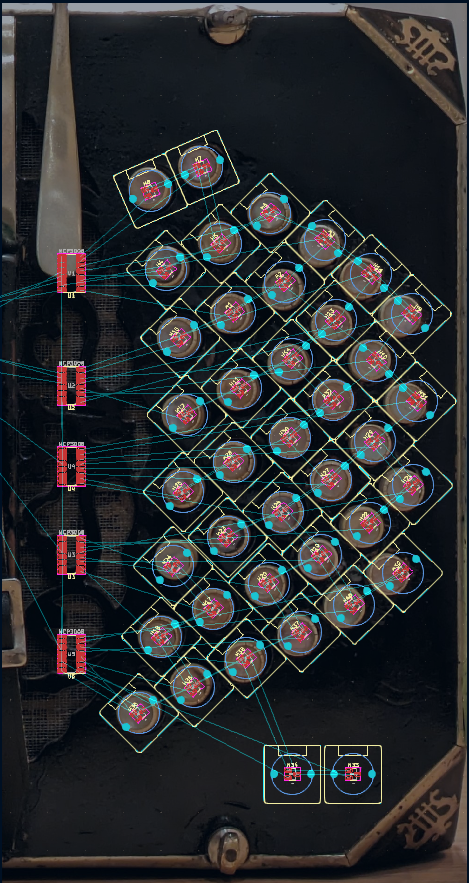
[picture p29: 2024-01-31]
images/Screenshot 2024-01-31 140824.png

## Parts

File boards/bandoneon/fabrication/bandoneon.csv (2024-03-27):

Comment | Designator | Footprint | LCSC Part #
1uF Unpolarized capacitor | C1,C2,C3,C4,C5,C6,C7,C8,C9 | C_0402_1005Metric | C52923
SS39ET Linear Hall-effect Sensor ICs | H1,H2,H3,H4,H5,H6,H7,H8,H9,H10,H11,H12,H13,H14,H15,H16,H17,H18,H19,H20,H21,H22,H23,H24,H25,H26,H27,H28,H29,H30,H31,H32,H33,H34,H35,H36,H37,H38,H39,H40,H41,H42,H43,H44,H45,H46,H47,H48,H49,H50,H51,H52,H53,H54,H55,H56,H57,H58,H59,H60,H61,H62,H63,H64,H65,H66,H67,H68,H69,H70,H71 | SOT-23_SS39ET | C126669
10K Resistor | R1 | R_0201_0603Metric | C25804
MCP3008 A/D Converter, 10-Bit, 8-Channel, SPI Interface , 2.7V-5.5V | U2,U3,U4,U5,U6,U7,U8,U9,U10 | SOIC-16_MCP3008T-I_SL | C1520159
SRV05-4 ESD Protection Diodes with Low Clamping Voltage, SOT-23-6 | U11,U12,U13 | SOT-23-6 | C2836319

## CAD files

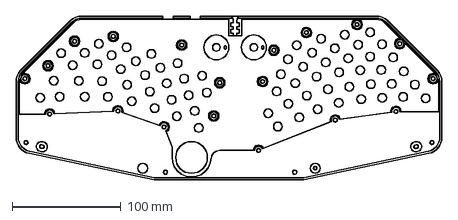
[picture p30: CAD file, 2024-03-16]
boards/bandoneon/carter.dxf
391.9 x 150.8 mm

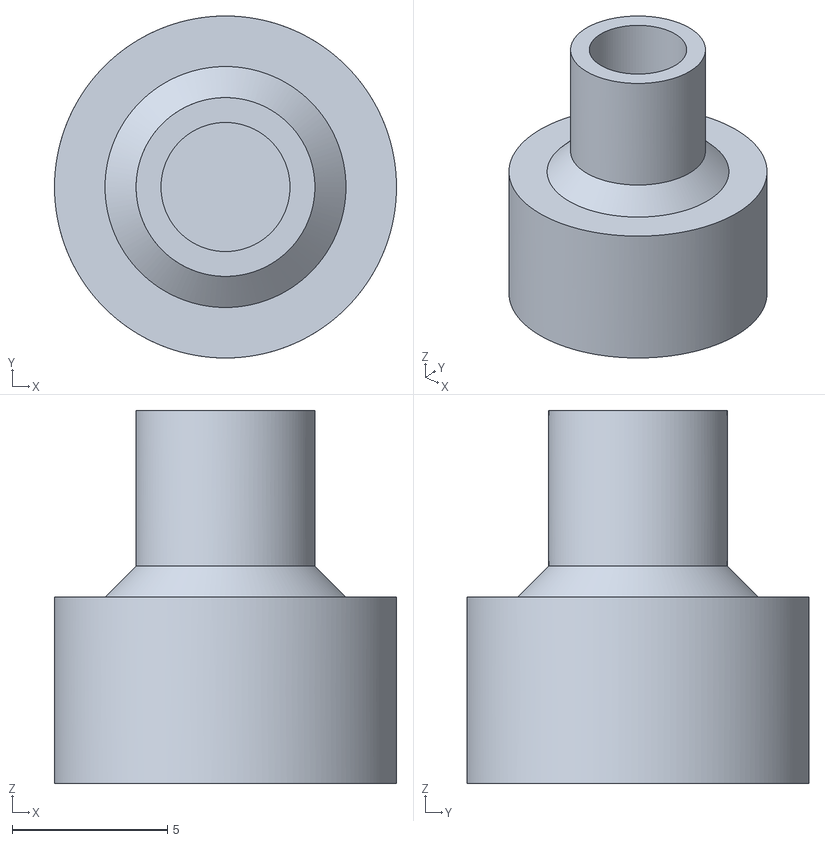
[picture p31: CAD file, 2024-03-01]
stl/caps/Cap-v2-cylinder-415.stl
11.0 x 11.0 x 12.0

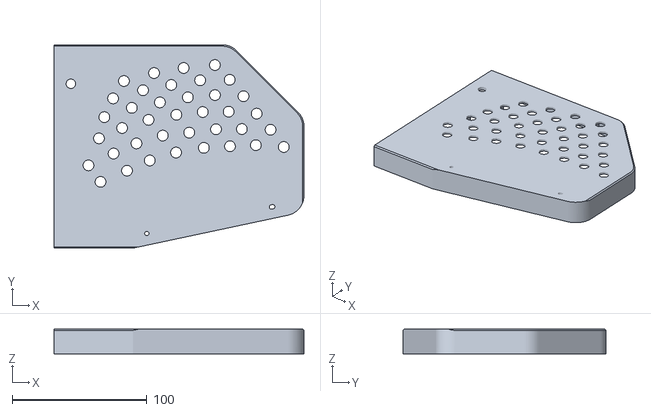
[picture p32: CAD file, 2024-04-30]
stl/Top R.stl
185.5 x 150.8 x 18.5

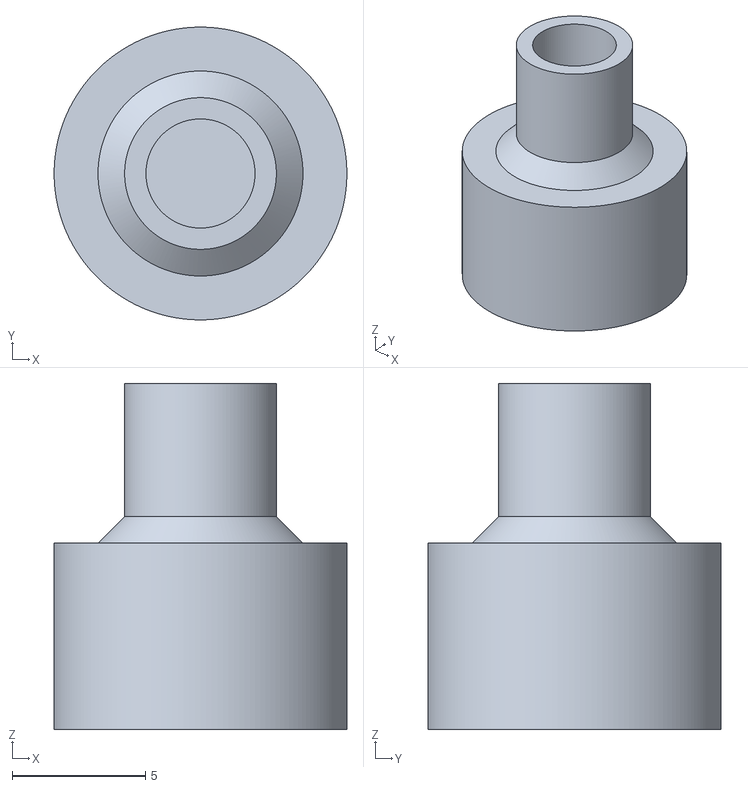
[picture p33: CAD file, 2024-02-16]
stl/caps/Cap2-v3.stl
11.0 x 11.0 x 13.0

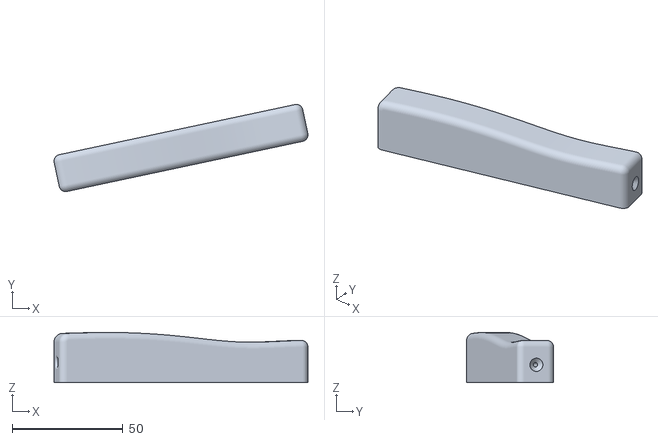
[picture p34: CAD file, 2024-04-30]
stl/Handle R.stl
114.9 x 39.4 x 22.6

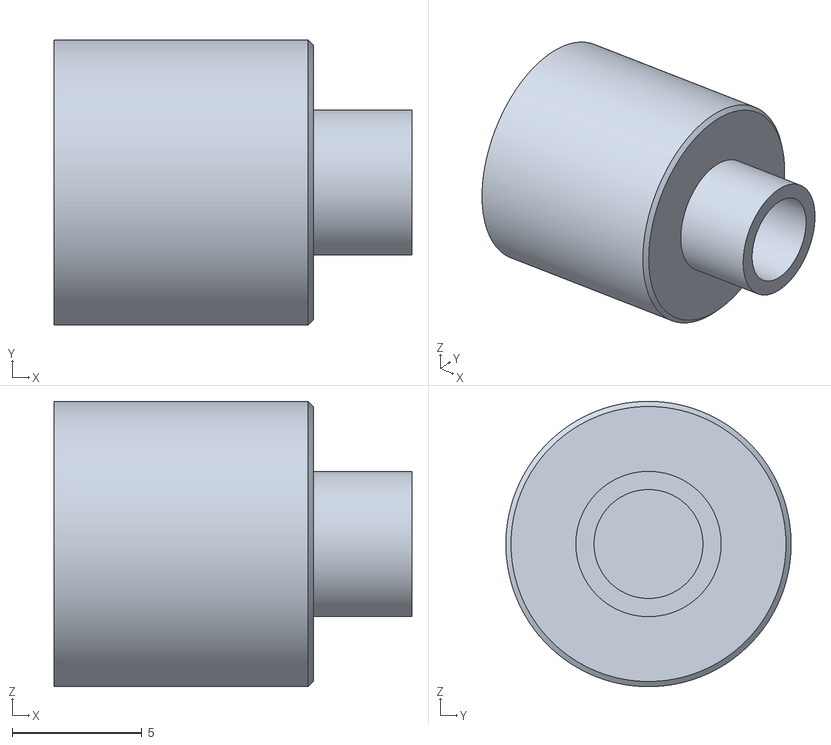
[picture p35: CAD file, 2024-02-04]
stl/caps/Cap-v2-cylinder-42.stl
13.8 x 11.0 x 11.0

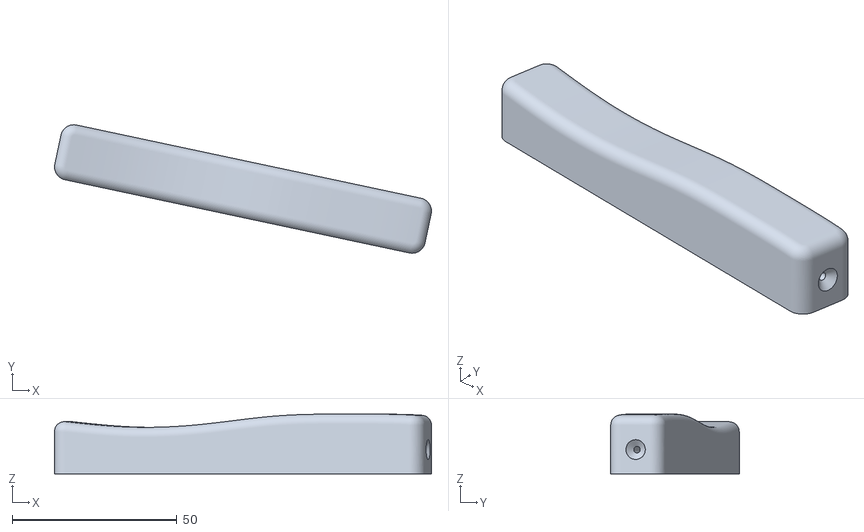
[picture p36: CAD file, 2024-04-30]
stl/Handle L.stl
114.5 x 39.0 x 18.2

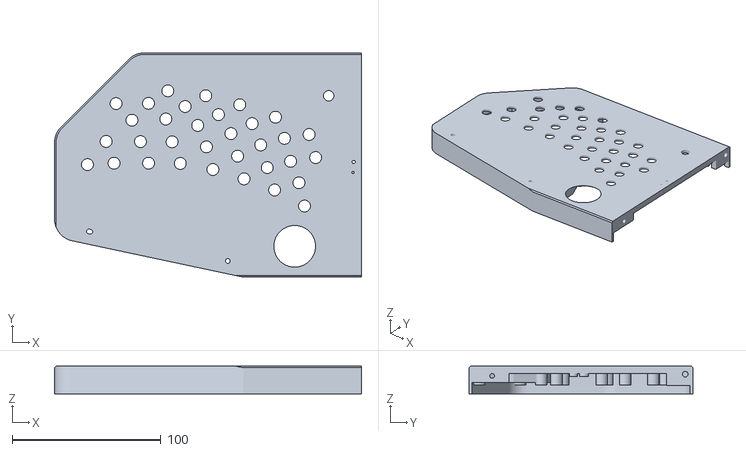
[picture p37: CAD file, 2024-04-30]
stl/Top L.stl
206.4 x 150.8 x 18.5

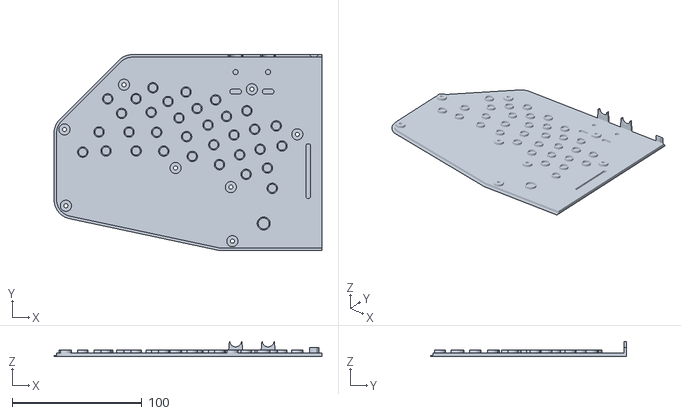
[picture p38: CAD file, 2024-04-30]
stl/Bottom L.stl
206.4 x 150.8 x 11.9

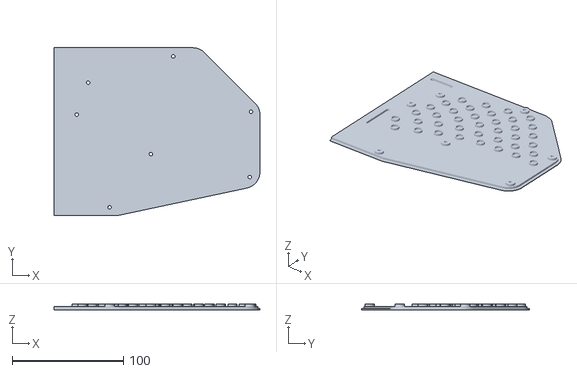
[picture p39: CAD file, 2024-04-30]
stl/Bottom R.stl
185.5 x 150.8 x 5.00

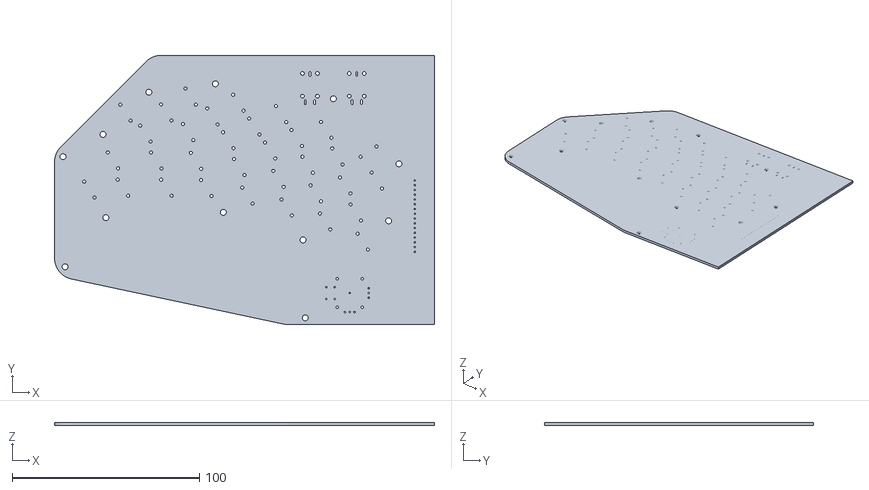
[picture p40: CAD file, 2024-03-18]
stl/PCB L.stl
202.9 x 143.8 x 1.60

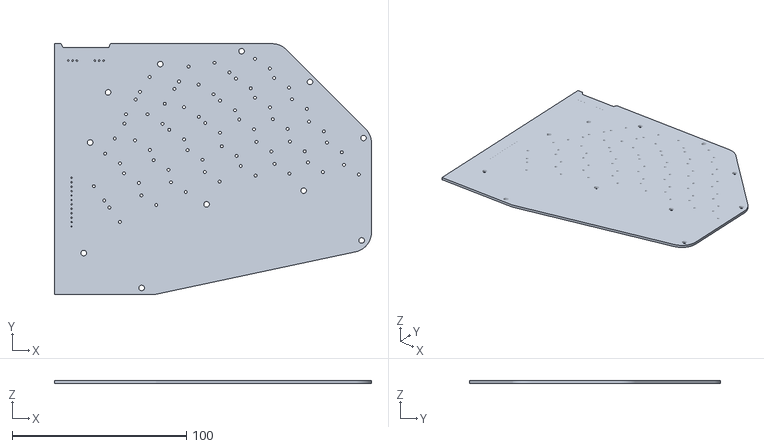
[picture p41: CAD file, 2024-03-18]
stl/PCB R.stl
182.0 x 143.8 x 1.60

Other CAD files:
stl/caps/Cap-v2-cylinder-45.stl
stl/caps/Cap-v1.stl

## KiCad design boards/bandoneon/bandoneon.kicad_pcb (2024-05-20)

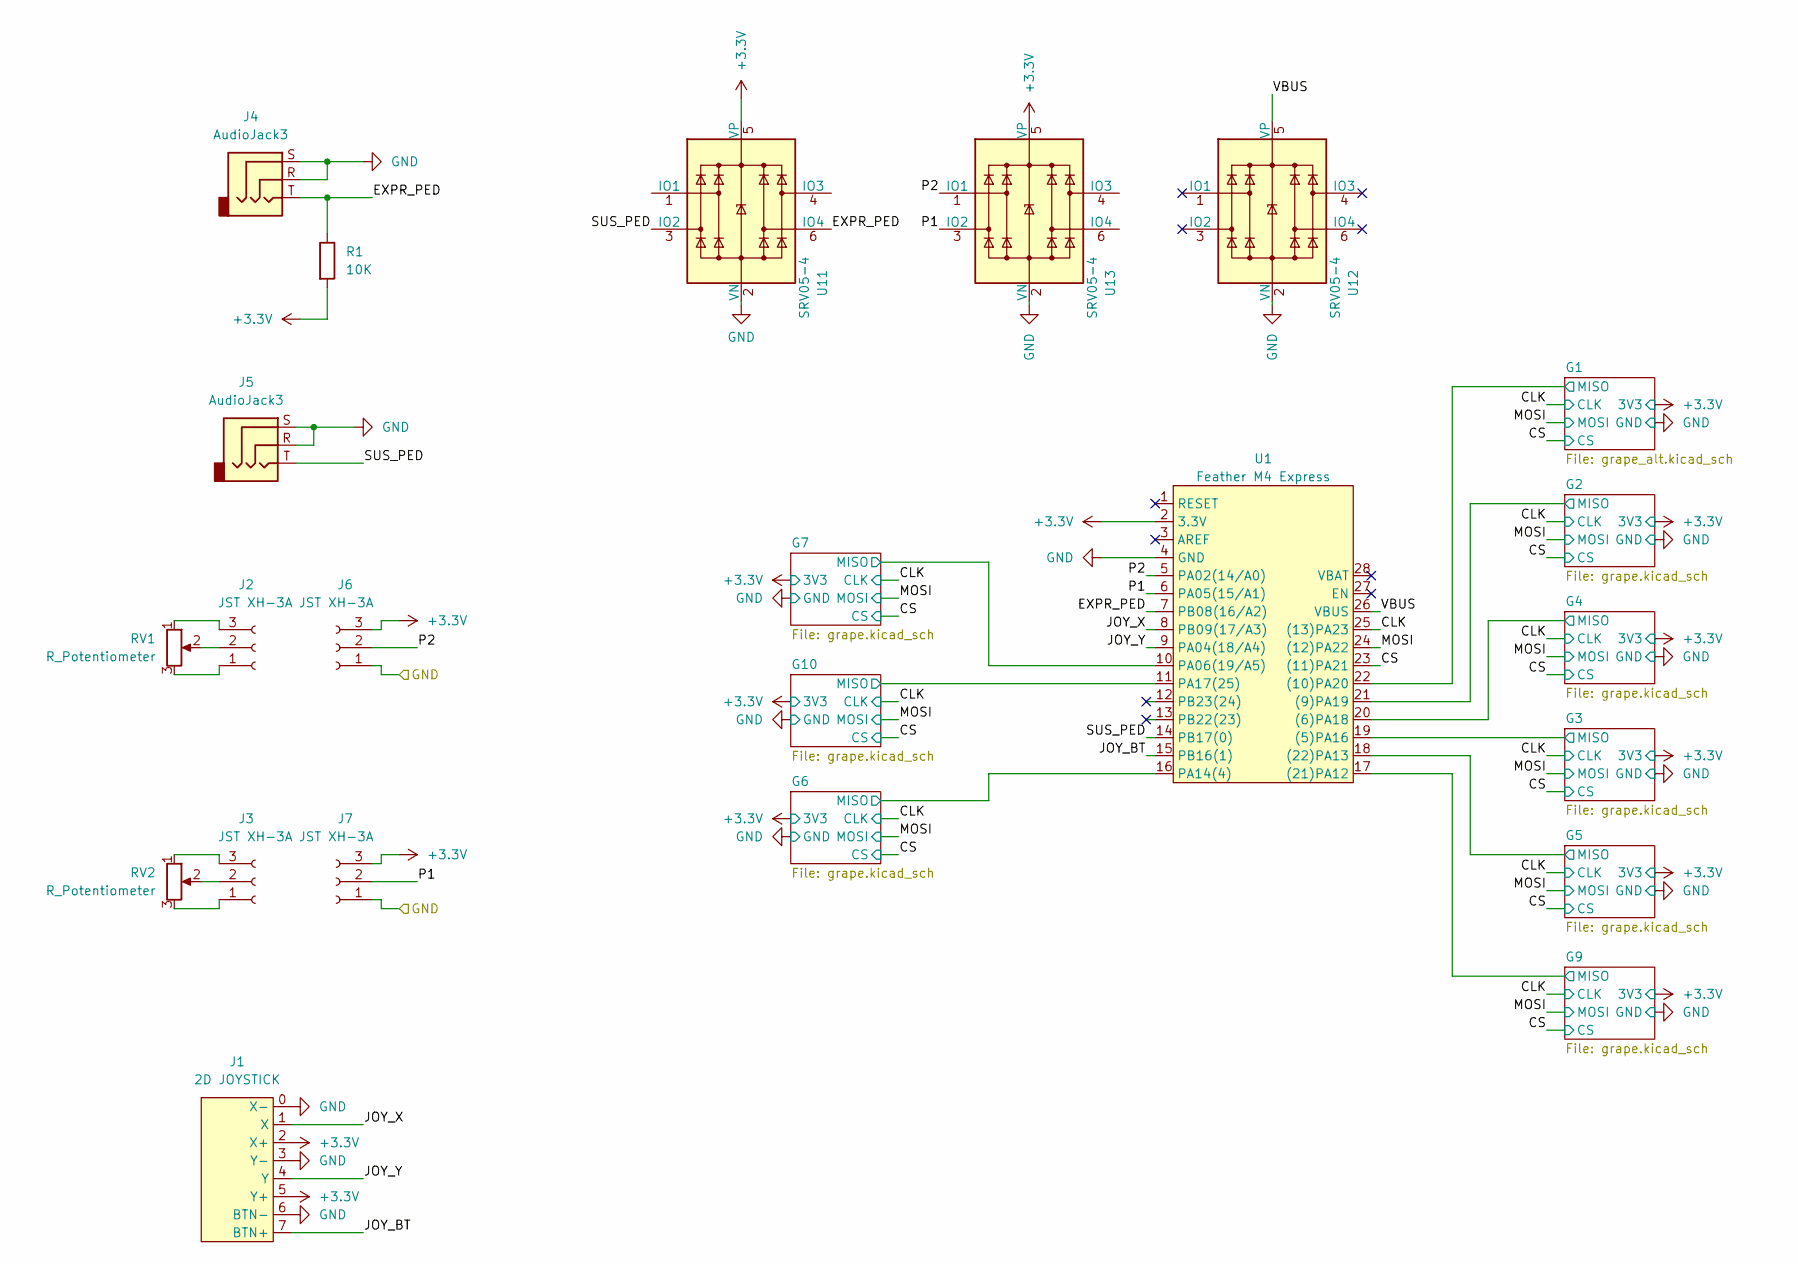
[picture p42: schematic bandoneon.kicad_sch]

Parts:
J1: 2D JOYSTICK; Adafruit (512) Analog 2-axis Thumb Joystick with Select But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
J2, J3: JST XH-3A
J4, J5: AudioJack3; Jack TRS
J6, J7: JST XH-3A; JST_XH_B3B-XH-A_1x03_P2.50mm_Vertical
R1: 10K; R_0603_1608Metric; LCSC Part C25804
RV1, RV2: R_Potentiometer
U1: Feather M4 Express; Adafruit_Feather_M4_Express
U11, U12, U13: SRV05-4; SOT-23-6; LCSC Part C2836319

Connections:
+3.3V: J1.2 (X+), J1.5 (Y+), J6.3, J7.3, R1.2, U1.2 (3.3V), U11.5 (VP), U13.5 (VP); also elsewhere on the board
/CLK: U1.25 ((13)PA23); also elsewhere on the board
/CS: U1.23 ((11)PA21); also elsewhere on the board
/EXPR_PED: J4.T, R1.1, U1.7 (PB08(16/A2)), U11.6 (IO4)
/G1/MISO: U1.22 ((10)PA20); also elsewhere on the board
/G2/MISO: U1.21 ((9)PA19); also elsewhere on the board
/G3/MISO: U1.19 ((5)PA16); also elsewhere on the board
/G4/MISO: U1.20 ((6)PA18); also elsewhere on the board
/G5/MISO: U1.18 ((22)PA13); also elsewhere on the board
/G6/MISO: U1.16 (PA14(4)); also elsewhere on the board
/G7/MISO: U1.10 (PA06(19/A5)); also elsewhere on the board
/G9/MISO: U1.17 ((21)PA12); also elsewhere on the board
/G10/MISO: U1.11 (PA17(25)); also elsewhere on the board
/JOY_BT: J1.7 (BTN+), U1.15 (PB16(1))
/JOY_X: J1.1 (X), U1.8 (PB09(17/A3))
/JOY_Y: J1.4 (Y), U1.9 (PA04(18/A4))
/MOSI: U1.24 ((12)PA22); also elsewhere on the board
/P1: J7.2, U1.6 (PA05(15/A1)), U13.3 (IO2)
/P2: J6.2, U1.5 (PA02(14/A0)), U13.1 (IO1)
/SUS_PED: J5.T, U1.14 (PB17(0)), U11.3 (IO2)
/VBUS: U1.26 (VBUS), U12.5 (VP)
GND: J1.0 (X-), J1.3 (Y-), J1.6 (BTN-), J4.R, J4.S, J5.R, J5.S, J6.1, J7.1, U1.4 (GND), U11.2 (VN), U12.2 (VN), U13.2 (VN); also elsewhere on the board
unnamed: J2.1, RV1.3
unnamed: J2.2, RV1.2
unnamed: J2.3, RV1.1
unnamed: J3.1, RV2.3
unnamed: J3.2, RV2.2
unnamed: J3.3, RV2.1

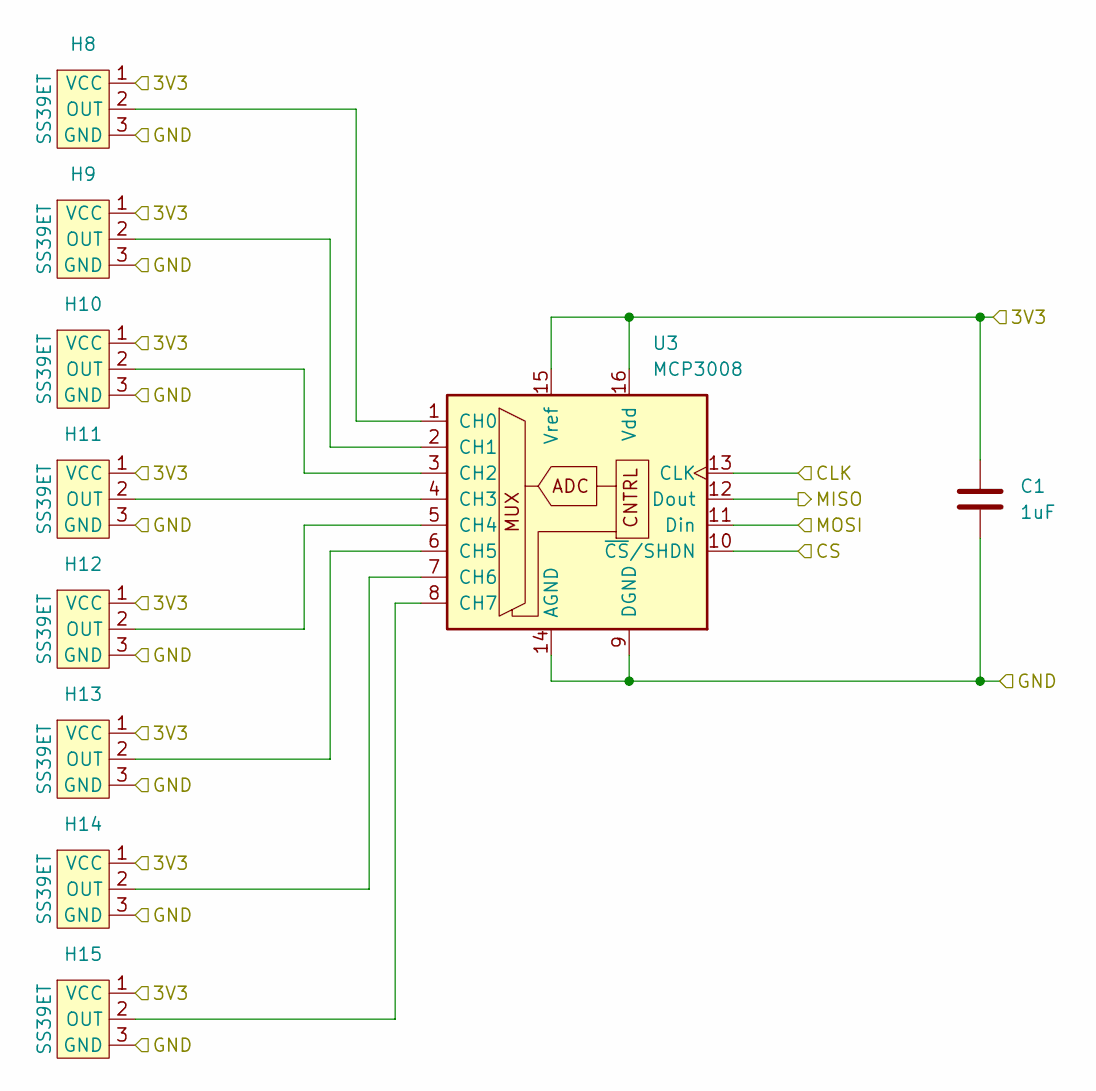
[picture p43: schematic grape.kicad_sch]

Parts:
C1: 1uF; C_0402_1005Metric; LCSC Part C52923
H8, H9, H10, H11, H12, H13, H14, H15: SS39ET; SOT-23_SS39ET; LCSC Part C126669
U3: MCP3008; SOIC-16_MCP3008T-I_SL; LCSC Part C1520159

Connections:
+3.3V: C1.1, H8.1 (VCC), H9.1 (VCC), H10.1 (VCC), H11.1 (VCC), H12.1 (VCC), H13.1 (VCC), H14.1 (VCC), H15.1 (VCC), U3.15 (Vref), U3.16 (Vdd); also elsewhere on the board
/CLK: U3.13 (CLK); also elsewhere on the board
/CS: U3.10 (~CS/SHDN); also elsewhere on the board
/G2/MISO: U3.12 (Dout); also elsewhere on the board
/MOSI: U3.11 (Din); also elsewhere on the board
GND: C1.2, H8.3 (GND), H9.3 (GND), H10.3 (GND), H11.3 (GND), H12.3 (GND), H13.3 (GND), H14.3 (GND), H15.3 (GND), U3.9 (DGND), U3.14 (AGND); also elsewhere on the board
unnamed: H8.2 (OUT), U3.1 (CH0)
unnamed: H9.2 (OUT), U3.2 (CH1)
unnamed: H10.2 (OUT), U3.3 (CH2)
unnamed: H11.2 (OUT), U3.4 (CH3)
unnamed: H12.2 (OUT), U3.5 (CH4)
unnamed: H13.2 (OUT), U3.6 (CH5)
unnamed: H14.2 (OUT), U3.7 (CH6)
unnamed: H15.2 (OUT), U3.8 (CH7)

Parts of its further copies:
C2, C3, C4, C5, C6, C7, C8: 1uF; C_0402_1005Metric; LCSC Part C52923
H16, H17, H18, H19, H20, H21, H22, H23, H24, H25, H26, H27, H28, H29, H30, H31, H32, H33, H34, H35, H36, H37, H38, H39, H40, H41, H42, H43, H44, H45, H46, H47, H48, H49, H50, H51, H52, H53, H54, H55, H57, H58, H60, H61, H62, H63, H64, H65, H66, H67, H68, H69, H70, H71: SS39ET; SOT-23_SS39ET; LCSC Part C126669
U4, U5, U6, U7, U8, U9, U10: MCP3008; SOIC-16_MCP3008T-I_SL; LCSC Part C1520159

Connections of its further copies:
+3.3V: C2.1, C3.1, C4.1, C5.1, C6.1, C7.1, C8.1, H16.1 (VCC), H17.1 (VCC), H18.1 (VCC), H19.1 (VCC), H20.1 (VCC), H21.1 (VCC), H22.1 (VCC), H23.1 (VCC), H24.1 (VCC), H25.1 (VCC), H26.1 (VCC), H27.1 (VCC), H28.1 (VCC), H29.1 (VCC), H30.1 (VCC), H31.1 (VCC), H32.1 (VCC), H33.1 (VCC), H34.1 (VCC), H35.1 (VCC), H36.1 (VCC), H37.1 (VCC), H38.1 (VCC), H39.1 (VCC), H40.1 (VCC), H41.1 (VCC), H42.1 (VCC), H43.1 (VCC), H44.1 (VCC), H45.1 (VCC), H46.1 (VCC), H47.1 (VCC), H48.1 (VCC), H49.1 (VCC), H50.1 (VCC), H51.1 (VCC), H52.1 (VCC), H53.1 (VCC), H54.1 (VCC), H55.1 (VCC), H57.1 (VCC), H58.1 (VCC), H60.1 (VCC), H61.1 (VCC), H62.1 (VCC), H63.1 (VCC), H64.1 (VCC), H65.1 (VCC), H66.1 (VCC), H67.1 (VCC), H68.1 (VCC), H69.1 (VCC), H70.1 (VCC), H71.1 (VCC), U4.15 (Vref), U4.16 (Vdd), U5.15 (Vref), U5.16 (Vdd), U6.15 (Vref), U6.16 (Vdd), U7.15 (Vref), U7.16 (Vdd), U8.15 (Vref), U8.16 (Vdd), U9.15 (Vref), U9.16 (Vdd), U10.15 (Vref), U10.16 (Vdd); also elsewhere on the board
/CLK: U4.13 (CLK), U5.13 (CLK), U6.13 (CLK), U7.13 (CLK), U8.13 (CLK), U9.13 (CLK), U10.13 (CLK); also elsewhere on the board
/CS: U4.10 (~CS/SHDN), U5.10 (~CS/SHDN), U6.10 (~CS/SHDN), U7.10 (~CS/SHDN), U8.10 (~CS/SHDN), U9.10 (~CS/SHDN), U10.10 (~CS/SHDN); also elsewhere on the board
/G3/MISO: U4.12 (Dout); also elsewhere on the board
/G4/MISO: U5.12 (Dout); also elsewhere on the board
/G5/MISO: U6.12 (Dout); also elsewhere on the board
/G6/MISO: U10.12 (Dout); also elsewhere on the board
/G7/MISO: U9.12 (Dout); also elsewhere on the board
/G9/MISO: U7.12 (Dout); also elsewhere on the board
/G10/MISO: U8.12 (Dout); also elsewhere on the board
/MOSI: U4.11 (Din), U5.11 (Din), U6.11 (Din), U7.11 (Din), U8.11 (Din), U9.11 (Din), U10.11 (Din); also elsewhere on the board
GND: C2.2, C3.2, C4.2, C5.2, C6.2, C7.2, C8.2, H16.3 (GND), H17.3 (GND), H18.3 (GND), H19.3 (GND), H20.3 (GND), H21.3 (GND), H22.3 (GND), H23.3 (GND), H24.3 (GND), H25.3 (GND), H26.3 (GND), H27.3 (GND), H28.3 (GND), H29.3 (GND), H30.3 (GND), H31.3 (GND), H32.3 (GND), H33.3 (GND), H34.3 (GND), H35.3 (GND), H36.3 (GND), H37.3 (GND), H38.3 (GND), H39.3 (GND), H40.3 (GND), H41.3 (GND), H42.3 (GND), H43.3 (GND), H44.3 (GND), H45.3 (GND), H46.3 (GND), H47.3 (GND), H48.3 (GND), H49.3 (GND), H50.3 (GND), H51.3 (GND), H52.3 (GND), H53.3 (GND), H54.3 (GND), H55.3 (GND), H57.3 (GND), H58.3 (GND), H60.3 (GND), H61.3 (GND), H62.3 (GND), H63.3 (GND), H64.3 (GND), H65.3 (GND), H66.3 (GND), H67.3 (GND), H68.3 (GND), H69.3 (GND), H70.3 (GND), H71.3 (GND), U4.9 (DGND), U4.14 (AGND), U5.9 (DGND), U5.14 (AGND), U6.9 (DGND), U6.14 (AGND), U7.9 (DGND), U7.14 (AGND), U8.9 (DGND), U8.14 (AGND), U9.9 (DGND), U9.14 (AGND), U10.9 (DGND), U10.14 (AGND); also elsewhere on the board
unnamed: H16.2 (OUT), U4.1 (CH0)
unnamed: H17.2 (OUT), U4.2 (CH1)
unnamed: H18.2 (OUT), U4.3 (CH2)
unnamed: H19.2 (OUT), U4.4 (CH3)
unnamed: H20.2 (OUT), U4.5 (CH4)
unnamed: H21.2 (OUT), U4.6 (CH5)
unnamed: H22.2 (OUT), U4.7 (CH6)
unnamed: H23.2 (OUT), U4.8 (CH7)
unnamed: H24.2 (OUT), U5.1 (CH0)
unnamed: H25.2 (OUT), U5.2 (CH1)
unnamed: H26.2 (OUT), U5.3 (CH2)
unnamed: H27.2 (OUT), U5.4 (CH3)
unnamed: H28.2 (OUT), U5.5 (CH4)
unnamed: H29.2 (OUT), U5.6 (CH5)
unnamed: H30.2 (OUT), U5.7 (CH6)
unnamed: H31.2 (OUT), U5.8 (CH7)
unnamed: H32.2 (OUT), U6.1 (CH0)
unnamed: H33.2 (OUT), U6.2 (CH1)
unnamed: H34.2 (OUT), U6.3 (CH2)
unnamed: H35.2 (OUT), U6.4 (CH3)
unnamed: H36.2 (OUT), U6.5 (CH4)
unnamed: H37.2 (OUT), U6.6 (CH5)
unnamed: H38.2 (OUT), U6.7 (CH6)
unnamed: H39.2 (OUT), U6.8 (CH7)
unnamed: H40.2 (OUT), U7.1 (CH0)
unnamed: H41.2 (OUT), U7.2 (CH1)
unnamed: H42.2 (OUT), U7.3 (CH2)
unnamed: H43.2 (OUT), U7.4 (CH3)
unnamed: H44.2 (OUT), U7.5 (CH4)
unnamed: H45.2 (OUT), U7.6 (CH5)
unnamed: H46.2 (OUT), U7.7 (CH6)
unnamed: H47.2 (OUT), U7.8 (CH7)
unnamed: H48.2 (OUT), U8.1 (CH0)
unnamed: H49.2 (OUT), U8.2 (CH1)
unnamed: H50.2 (OUT), U8.3 (CH2)
unnamed: H51.2 (OUT), U8.4 (CH3)
unnamed: H52.2 (OUT), U8.5 (CH4)
unnamed: H53.2 (OUT), U8.6 (CH5)
unnamed: H54.2 (OUT), U8.7 (CH6)
unnamed: H55.2 (OUT), U8.8 (CH7)
unnamed 77: U9.1 (CH0); also elsewhere on the board
unnamed: H57.2 (OUT), U9.2 (CH1)
unnamed: H58.2 (OUT), U9.3 (CH2)
unnamed 80: U9.4 (CH3); also elsewhere on the board
unnamed: H60.2 (OUT), U9.5 (CH4)
unnamed: H61.2 (OUT), U9.6 (CH5)
unnamed: H62.2 (OUT), U9.7 (CH6)
unnamed: H63.2 (OUT), U9.8 (CH7)
unnamed: H64.2 (OUT), U10.1 (CH0)
unnamed: H65.2 (OUT), U10.2 (CH1)
unnamed: H66.2 (OUT), U10.3 (CH2)
unnamed: H67.2 (OUT), U10.4 (CH3)
unnamed: H68.2 (OUT), U10.5 (CH4)
unnamed: H69.2 (OUT), U10.6 (CH5)
unnamed: H70.2 (OUT), U10.7 (CH6)
unnamed: H71.2 (OUT), U10.8 (CH7)

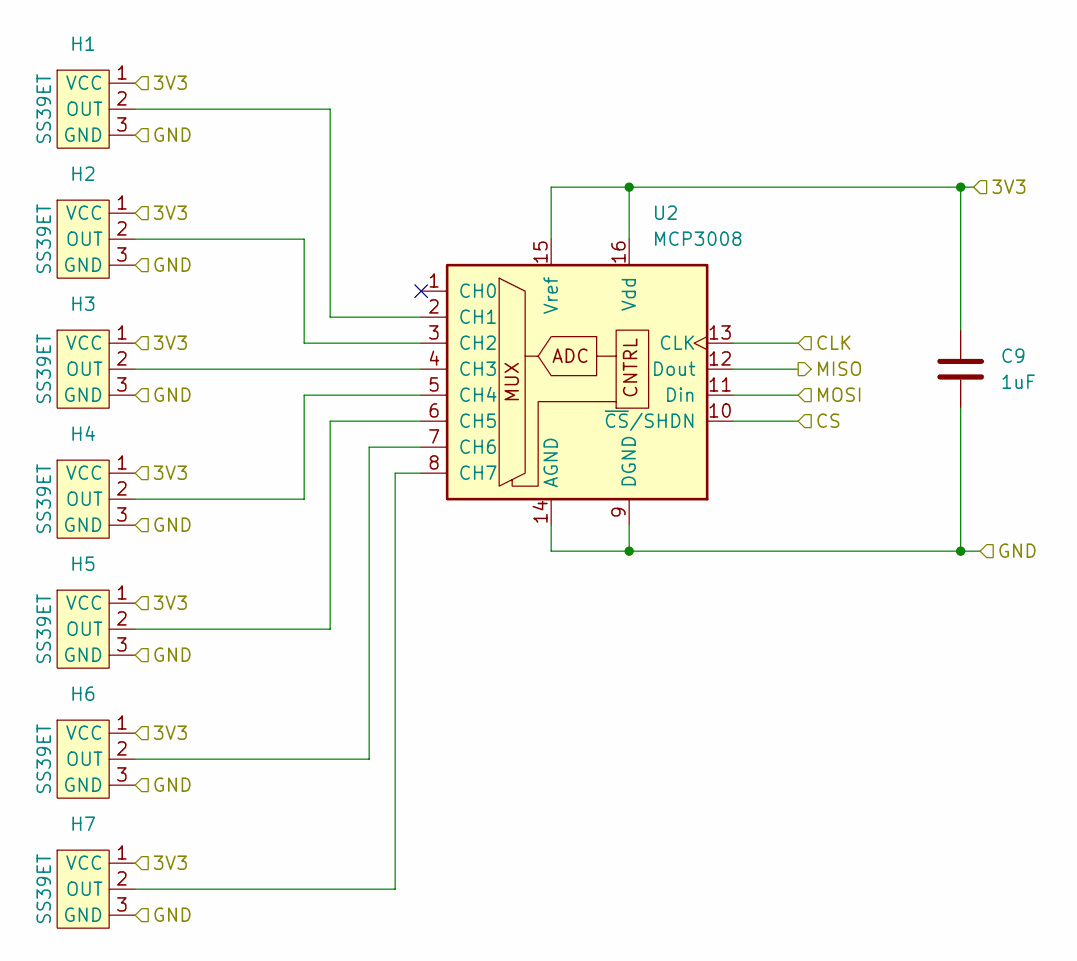
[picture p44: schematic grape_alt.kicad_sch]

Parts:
C9: 1uF; C_0402_1005Metric; LCSC Part C52923
H1, H2, H3, H4, H5, H6, H7: SS39ET; SOT-23_SS39ET; LCSC Part C126669
U2: MCP3008; SOIC-16_MCP3008T-I_SL; LCSC Part C1520159

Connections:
+3.3V: C9.1, H1.1 (VCC), H2.1 (VCC), H3.1 (VCC), H4.1 (VCC), H5.1 (VCC), H6.1 (VCC), H7.1 (VCC), U2.15 (Vref), U2.16 (Vdd); also elsewhere on the board
/CLK: U2.13 (CLK); also elsewhere on the board
/CS: U2.10 (~CS/SHDN); also elsewhere on the board
/G1/MISO: U2.12 (Dout); also elsewhere on the board
/MOSI: U2.11 (Din); also elsewhere on the board
GND: C9.2, H1.3 (GND), H2.3 (GND), H3.3 (GND), H4.3 (GND), H5.3 (GND), H6.3 (GND), H7.3 (GND), U2.9 (DGND), U2.14 (AGND); also elsewhere on the board
unnamed: H1.2 (OUT), U2.2 (CH1)
unnamed: H2.2 (OUT), U2.3 (CH2)
unnamed: H3.2 (OUT), U2.4 (CH3)
unnamed: H4.2 (OUT), U2.5 (CH4)
unnamed: H5.2 (OUT), U2.6 (CH5)
unnamed: H6.2 (OUT), U2.7 (CH6)
unnamed: H7.2 (OUT), U2.8 (CH7)

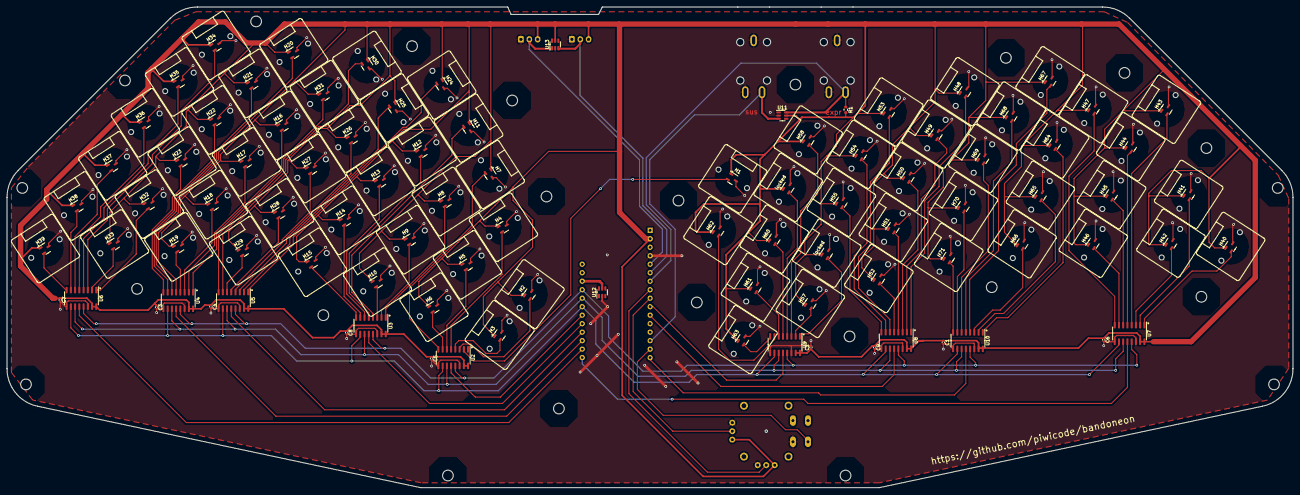
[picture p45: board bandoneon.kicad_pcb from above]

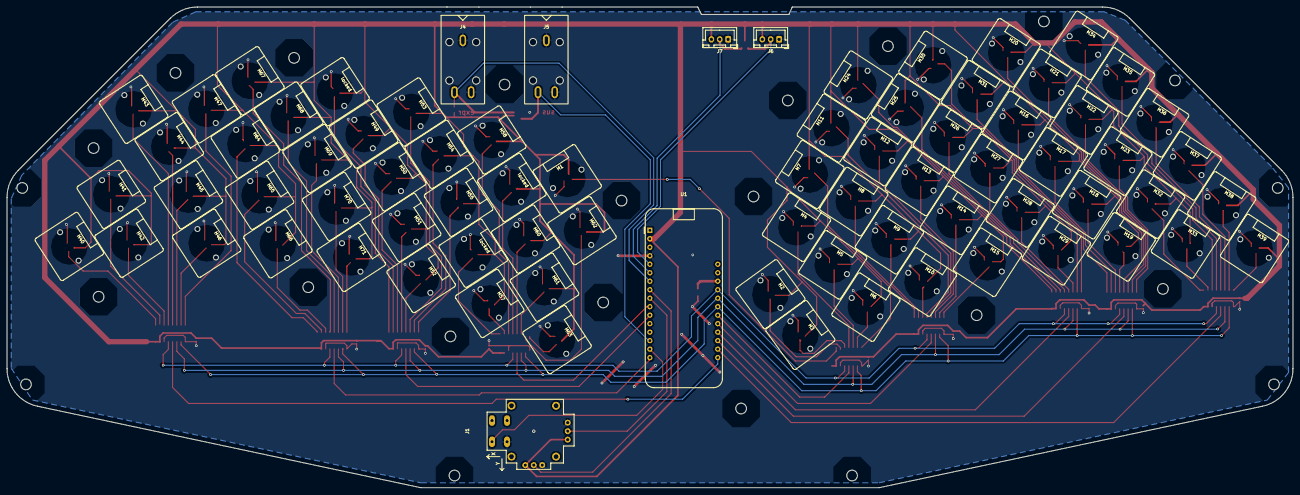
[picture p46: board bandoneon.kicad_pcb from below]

Board: 2 copper layers, 384.9 x 143.8 mm, 122 parts (6 on the bottom side), 93 nets.

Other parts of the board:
MH01, MH02, MH03, MH05, MH06, MH07, MH08, MH09, MH10, MH11, MH12, MH13, MH14, MH15, MH16, MH17, MH18, MH19, MH20, MH21, MH22, MH33, MH39: MountingHole_3.2mm_M3_large
locked: SS39ET; SOT-23_SS39ET
locked#2: locked; SOT-23_SS39ET

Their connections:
+3.3V: locked.1 (VCC), locked#2.1 (VCC); also elsewhere on the board
GND: locked.3 (GND), locked#2.3 (GND); also elsewhere on the board
unnamed 77: locked#2.2 (OUT); also elsewhere on the board
unnamed 80: locked.2 (OUT); also elsewhere on the board

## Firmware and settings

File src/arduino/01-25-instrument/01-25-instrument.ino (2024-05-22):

#include <Adafruit_TinyUSB.h>
#include <Adafruit_NeoPixel.h>
#include <Arduino.h>
#include <MIDI.h>

#include <array>
#include <cassert>
#include <vector>

constexpr size_t kNotesCount = 12;
constexpr char const *kNotesNames[kNotesCount] = {
    "C",     "C#/Db", "D",     "D#/Eb", "E",     "F",
    "F#/Gb", "G",     "G#/Ab", "A",     "A#/Bb", "B",
};

// Returns the MIDI note index for a given not and octave.
enum { C, Cd, D, Dd, E, F, Fd, G, Gd, A, Ad, B };
constexpr uint8_t n(int note, int octave) {
  return (octave + 1) * kNotesCount + static_cast<int>(note);
}

// Maps measure position to a MIDI note index.
// 0: close/push, 1: open/pull
constexpr uint8_t keyboard_mapping[2][72] = {
    {
        /*00*/ 0,        n(Fd, 4), n(A, 6),  n(Ad, 4), n(A, 5),
        /*05*/ n(E, 2),  n(G, 3),  n(Ad, 2), n(Gd, 3), n(G, 4),
        /*10*/ n(E, 4),  n(G, 6),  n(B, 4),  n(E, 6),  n(A, 2),
        /*15*/ n(A, 3),  n(C, 4),  n(Cd, 2), n(A, 3),  n(F, 5),
        /*20*/ n(Gd, 4), n(E, 5),  n(F, 6),  n(E, 3),  n(Gd, 4),
        /*25*/ n(D, 4),  n(Dd, 4), n(Ad, 3), n(C, 4),  n(G, 4),
        /*30*/ n(B, 5),  n(Dd, 6), n(D, 2),  n(G, 2),  n(E, 4),
        /*35*/ n(C, 3),  n(B, 3),  n(Cd, 4), n(Cd, 5), n(Fd, 6),
        /*40*/ n(D, 6),  n(G, 2),  n(Ad, 3), n(F, 3),  n(Fd, 3),
        /*45*/ n(F, 4),  n(Fd, 5), n(Gd, 5), n(C, 6),  n(G, 5),
        /*50*/ n(E, 3),  n(B, 3),  n(Dd, 3), n(B, 2),  n(Dd, 4),
        /*55*/ n(A, 4),  n(Gd, 6), n(C, 5),  n(Cd, 6), n(Fd, 4),
        /*60*/ n(Cd, 4), n(Cd, 3), n(Fd, 2), n(D, 4),  n(E, 5),
        /*65*/ n(Ad, 5), n(D, 5),  n(Dd, 5), n(D, 3),  n(B, 4),
        /*70*/ n(F, 4),  n(F, 2),
    },
    {
        /*00*/ 0,        n(E, 4),  n(B, 6),  n(Ad, 5), n(Gd, 5),
        /*05*/ n(D, 2),  n(A, 3),  n(Ad, 2), n(Cd, 4), n(Gd, 4),
        /*10*/ n(Ad, 4), n(A, 6),  n(A, 4),  n(Cd, 6), n(E, 3),
        /*15*/ n(B, 3),  n(Dd, 3), n(Dd, 2), n(A, 3),  n(F, 5),
        /*20*/ n(G, 4),  n(D, 5),  n(F, 6),  n(B, 2),  n(A, 4),
        /*25*/ n(E, 4),  n(F, 3),  n(Ad, 3), n(Cd, 4), n(Fd, 4),
        /*30*/ n(A, 5),  n(Dd, 6), n(E, 2),  n(Gd, 2), n(Fd, 4),
        /*35*/ n(Ad, 3), n(B, 3),  n(D, 4),  n(B, 4),  n(G, 6),
        /*40*/ n(D, 6),  n(D, 3),  n(G, 3),  n(Fd, 3), n(G, 2),
        /*45*/ n(F, 4),  n(Cd, 5), n(Fd, 5), n(E, 6),  n(E, 5),
        /*50*/ n(Gd, 3), n(C, 4),  n(Cd, 3), n(Fd, 2), n(Dd, 4),
        /*55*/ n(Gd, 4), n(Gd, 6), n(C, 6),  n(B, 5),  n(G, 4),
        /*60*/ n(D, 4),  n(F, 4),  n(F, 2),  n(C, 4),  n(Dd, 5),
        /*65*/ n(Fd, 6), n(C, 5),  n(G, 5),  n(A, 2),  n(Dd, 4),
        /*70*/ n(C, 3),  n(C, 2),
    }};

// 1 for the right hand and 0 for the left hand.
constexpr uint8_t keyboard_channel[72] = {
    /*00*/ 0, 1, 1, 1, 1,
    /*05*/ 0, 0, 0, 0, 0,
    /*10*/ 1, 1, 1, 1, 0,
    /*15*/ 0, 0, 0, 1, 1,
    /*20*/ 1, 1, 1, 0, 0,
    /*25*/ 0, 0, 1, 1, 1,
    /*30*/ 1, 1, 0, 0, 0,
    /*35*/ 0, 1, 1, 1, 1,
    /*40*/ 1, 0, 0, 0, 0,
    /*45*/ 1, 1, 1, 1, 1,
    /*50*/ 0, 0, 0, 0, 1,
    /*55*/ 1, 1, 1, 1, 0,
    /*60*/ 0, 0, 0, 1, 1,
    /*65*/ 1, 1, 1, 0, 0,
    /*70*/ 0, 0};

// USB MIDI object
Adafruit_USBD_MIDI usb_midi;
Adafruit_NeoPixel pixels(1, 8);

// Create a new instance of the Arduino MIDI Library,
// and attach usb_midi as the transport.
MIDI_CREATE_INSTANCE(Adafruit_USBD_MIDI, usb_midi, MIDI);

#define digitalPinToBitShift(P) (g_APinDescription[P].ulPin)

// This is assuing the clear register is contiguous with the set.
// Static assertion complains when testing the pointers.
#define SET_PORT_BIT(P, mask, value)       \
  do {                                     \
    *(&REG_PORT_OUTCLR##P + value) = mask; \
  } while (0)

#define PROFILE(x)                    \
  {                                   \
    DWT->CYCCNT = 0;                  \
    x;                                \
    const uint32_t end = DWT->CYCCNT; \
    Serial.print(#x);                 \
    Serial.print(" took ");           \
    Serial.print(end);                \
    Serial.println(" cycles");        \
  }

#undef assert
#define assert(x)                      \
  do {                                 \
    if (!(x)) {                        \
      Serial.println();                \
      Serial.print("Assert failed: "); \
      Serial.println(#x);              \
      Serial.print(__FILE__);          \
      Serial.print(":");               \
      Serial.println(__LINE__);        \
    }                                  \
  } while (0);

template <typename... A>
struct TT {};
template <size_t N>
class SPIArray {
 private:
  enum Mode { IDLE_LOW, IDEL_HIGH };
  using PadValue = uint32_t;

  static_assert(
      sizeof(*portOutputRegister(digitalPinToPort(0))) == sizeof(PadValue),
      "the pad size looks incorrect. Please fix to match your architecture.");

  // User provided configuration.
  const uint8_t clk_;
  const uint8_t mosi_;
  const std::array<uint8_t, N> miso_;
  const uint8_t cs_;

  // Hardware mapping.
  PadValue cs_mask_, clk_mask_, mosi_mask_;
  std::array<uint32_t, N> miso_shifts_;

 public:
  uint32_t half_period_cyc_;
  SPIArray(uint8_t clk, uint8_t mosi, std::array<uint8_t, N> miso, uint8_t cs)
      : clk_(clk), mosi_(mosi), miso_(std::move(miso)), cs_(cs) {
    // Asserts that all specified pins are in the same port.
    clk_mask_ = digitalPinToBitMask(clk_);
    mosi_mask_ = digitalPinToBitMask(mosi_);
    for (int i = 0; i < N; i++) {
      miso_shifts_[i] = digitalPinToBitShift(miso[i]);
    }
    cs_mask_ = digitalPinToBitMask(cs_);
  }

  void begin() const {
    pinMode(cs_, OUTPUT);
    digitalWrite(cs_, HIGH);

    pinMode(clk_, OUTPUT);
    // Only Spi mode 0 is supported: idle low on mode 0 and 1
    digitalWrite(clk_, LOW);

    pinMode(mosi_, OUTPUT);
    digitalWrite(mosi_, HIGH);

    for (auto pin : miso_) {
      pinMode(pin, INPUT);
    }
  }

  int size() const { return miso_.size(); }
  inline void select(bool value) const { SET_PORT_BIT(0, cs_mask_, !value); }

  inline void transfer(const uint32_t wbuf, const uint32_t lsb_bits_to_transmit,
                       uint32_t *rbuf) const {  // Use std::span<uint32_t, N>
                                                // when available.
    for (int8_t shift = lsb_bits_to_transmit - 1; shift >= 0; shift--) {
      const bool mosi_value = (wbuf >> shift) & 0x1;
      SET_PORT_BIT(0, mosi_mask_, mosi_value);

      REG_PORT_OUTSET0 = clk_mask_;

      __NOP();
      __NOP();
      __NOP();
      __NOP();
      __NOP();
      const uint32_t in = REG_PORT_IN0;
      int i = 0;
      for (; i < N / 2; i++) {
        const bool bit = (in >> miso_shifts_[i]) & 0x1;
        rbuf[i] = (rbuf[i] << 1) | bit;
      }

      REG_PORT_OUTCLR0 = clk_mask_;

      for (; i < N; i++) {
        const bool bit = (in >> miso_shifts_[i]) & 0x1;
        rbuf[i] = (rbuf[i] << 1) | bit;
      }
    }
  }
};

template <size_t N>
class MCP3008Array {
  SPIArray<N> spi_array_;

 public:
  typedef std::array<uint32_t, N * 8> Values;

  // Use digital pin index as visible on the Feather pinout.
  MCP3008Array(uint8_t clk, uint8_t mosi, std::array<uint8_t, N> miso,
               uint8_t cs)
      : spi_array_(clk, mosi, miso, cs) {}

  void begin() const { spi_array_.begin(); }
  // Returns the measures for all channels of all ADCs.
  // values[channel_idx * N + adc_idx]
  void read(Values &values) const {
    for (uint8_t channel = 0; channel < 8; channel++) {
      spi_array_.select(true);
      const uint32_t write = 0x18000 | (channel << 12);
      spi_array_.transfer(write, 17, &values[channel * N]);
      spi_array_.select(false);
    }
    for (auto &v : values) {
      v &= 0x3ff;
    }
  }
};

MCP3008Array<9> adc_array(13, 12, {10, 9, 6, 5, 22, 21, 4, 25, 19}, 11);
uint32_t count = 0;

void setup() {
  usb_midi.setStringDescriptor("Bandoneon");

  // Initialize MIDI, and listen to all MIDI channels
  // This will also call usb_midi's begin()
  MIDI.begin(MIDI_CHANNEL_OMNI);

  // Enable logging through the serial port.
  Serial.begin(115200);
  adc_array.begin();

  // Wait until device mounted
  while (!TinyUSBDevice.mounted()) delay(1);

  // Light the pixel.
  pixels.begin();  
  pixels.show(); 
  pixels.clear();  
  pixels.setPixelColor(0, pixels.Color(0,1,2));
  pixels.show(); 
}

class Heartbit {
  uint32_t last_display_ms_;
  uint32_t tick_count_;
  static constexpr uint32_t kHeartbitPeriodMs = 10000;

 public:
  Heartbit() : last_display_ms_(millis()), tick_count_(0) {}
  bool tick() {
    tick_count_++;
    uint32_t delay = millis() - last_display_ms_;
    if (delay > kHeartbitPeriodMs) {
      last_display_ms_ += kHeartbitPeriodMs;
      Serial.print("Heartbit: scan frequency is ");
      Serial.print(tick_count_ * 1000 / delay);
      Serial.println(" Hz");
      tick_count_ = 0;
      return true;
    }
    return false;
  }
};

class Devices {
 public:
  struct Pinout {
    uint32_t p1_analog;
    uint32_t p2_analog;
    uint32_t expression_pedal_analog;
    uint32_t joy_x_analog;
    uint32_t joy_y_analog;
    uint32_t joy_bt_digital;
    uint32_t sustain_pedal_digital;
  } pinout_;

  struct Value {
    uint32_t p1;
    uint32_t p2;
    uint32_t expression_pedal;
    uint32_t joy_x;
    uint32_t joy_y;
    bool joy_bt;
    bool sustain_pedal;

    void print() {
      Serial.print("p1: ");
      Serial.print(p1);
      Serial.print(" p2: ");
      Serial.print(p2);
      Serial.print(" exp: ");
      Serial.print(expression_pedal);
      Serial.print(" sus: ");
      Serial.print(sustain_pedal);
      Serial.println();
      Serial.print("joy_x: ");
      Serial.print(joy_x);
      Serial.print(" y: ");
      Serial.print(joy_y);
      Serial.print(" bt: ");
      Serial.print(joy_bt);
      Serial.println();
    }
  };

  Devices(Pinout pinout) : pinout_(pinout) {
    pinMode(pinout_.p1_analog, INPUT);
    pinMode(pinout_.p2_analog, INPUT);
    pinMode(pinout_.expression_pedal_analog, INPUT);
    pinMode(pinout_.joy_x_analog, INPUT);
    pinMode(pinout_.joy_y_analog, INPUT);
    pinMode(pinout_.sustain_pedal_digital, INPUT_PULLUP);
    pinMode(pinout_.joy_bt_digital, INPUT_PULLUP);
  }

  void read(Value &value) {
    value.p1 = analogRead(pinout_.p1_analog);
    value.p2 = analogRead(pinout_.p2_analog);
    value.expression_pedal = analogRead(pinout_.expression_pedal_analog);
    value.joy_x = analogRead(pinout_.joy_x_analog);
    value.joy_y = analogRead(pinout_.joy_y_analog);
    value.joy_bt = digitalRead(pinout_.joy_bt_digital);
    value.sustain_pedal = digitalRead(pinout_.sustain_pedal_digital);
  }
};

Devices devices({
    .p1_analog = A1,
    .p2_analog = A0,
    .expression_pedal_analog = A2,
    .joy_x_analog = A3,
    .joy_y_analog = A4,
    .joy_bt_digital = 1,
    .sustain_pedal_digital = 0,
});

struct HysteresisFilter {
  const int32_t gap = 5;
  bool increasing = true;
  int32_t previous_value = 0;

  uint32_t apply(int32_t new_value) {
    if (increasing) {
      if (new_value > previous_value) {
        previous_value = new_value;
      } else if (new_value < previous_value - gap) {
        increasing = false;
        previous_value = new_value;
      }
    } else {
      if (new_value < previous_value) {
        previous_value = new_value;

      } else if (new_value > previous_value - gap) {
        increasing = true;
        previous_value = new_value;
      }
    }
    return previous_value;
  }
};

struct AxisMapper {
  int32_t min;
  int32_t max;

  int32_t out_min;
  int32_t out_max;

  int32_t remap(int32_t value) const {
    if (value < min) {
      return out_min;
    }
    if (value < max) {
      return out_min + (value - min) * (out_max - out_min) / (max - min);
    }
    return out_max;
  }
};

struct JoystickAxisMapper {
  uint32_t min;
  uint32_t max;
  // Central deadzone, inclusive
  uint32_t dead_min;
  uint32_t dead_max;

  uint32_t out_min;
  uint32_t out_max;
  uint32_t out_center;

  uint32_t remap(uint32_t value) const {
    if (value < min) {
      return out_min;
    }
    if (value < dead_min) {
      return out_center -
             (dead_min - value) * (out_center - out_min) / (dead_min - min);
    }
    if (value <= dead_max) {
      return out_center;
    }
    if (value < max) {
      return out_center +
             (value - dead_max) * (out_max - out_center) / (max - dead_max);
    }
    return out_max;
  }
};

constexpr AxisMapper expression_mapper{
    .min = 92,
    .max = 515,
    .out_min = 0x7f,
    .out_max = 0x0,
};

// proto 2: min=2 max=1021
constexpr AxisMapper p1_mapper{
    .min = 3 + 1,
    .max = 1021 - 1,
    .out_min = 0x7f,
    .out_max = 0x0,
};

// proto 2: min=2 max=1021
constexpr AxisMapper p2_mapper{
    .min = 3 + 1,
    .max = 1021 - 1,
    .out_min = 0x7f, 
    .out_max = 0x0,
};

constexpr JoystickAxisMapper y_axis_mapper{.min = 3 + 1,
                                           .max = 1023 - 1,
                                           .dead_min = 515 - 2,
                                           .dead_max = 515 + 2,
                                           .out_min = 0x0,
                                           .out_max = 0x7f,
                                           .out_center = 0x40};

constexpr bool kPrintKey = false;
constexpr bool kPrintMidiEvents = false;

// Low pass filter on the derivate of the signal.
// The current derivate is merged in the previous one with a factor.
// 1 ignore the past, and 0 ignore the present.
constexpr float kDecayFactor = 0.25;
// Velocity profile.
constexpr float kMinVelocity = 0.35;
constexpr float kMaxVelocity = 12.47;

// Measure above which one a key is considered pressed.
constexpr int32_t kPressThreshold = 600;
constexpr int32_t kReleaseThreshold = 580;

constexpr int32_t kMeasuresSize = 16;

constexpr int32_t kMidiChannel = 1;

// Holds reading for each key, with some history.
decltype(adc_array)::Values measures[kMeasuresSize] = {};
// Time just before staring the corresponding reading.
int32_t measures_us[kMeasuresSize] = {};

std::array<bool, measures[0].size()> isPressed{};

template <size_t N>
void printKeyboardState(const std::array<uint32_t, N> &values) {
  Serial.print("=== Keyboard state ===");
  for (uint32_t i = 0; i < values.size(); i++) {
    if (i % (N / 8) == 0) Serial.println();
    size_t len = Serial.print(values[i] > 600 ? 1 : 0);
    for (int c = max(0, 5 - len); c--;) Serial.print(' ');
    Serial.print(',');
  }
  Serial.println();
}

void printNoteName(uint8_t midi_code) {
  const int note_idx = midi_code % kNotesCount;
  const int octave = midi_code / kNotesCount - 1;
  Serial.print(kNotesNames[note_idx]);
  Serial.print(octave);
}

void loop() {
  Heartbit heartbit;

  // Initialises all the measure histroy from an initial reading.
  for (uint32_t t = 1; t < kMeasuresSize; t++) {
    measures_us[t] = micros();
    adc_array.read(measures[t]);
  }

  uint32_t t1_id = 0;
  uint32_t previous_bend = 0x40;  // center
  uint32_t previous_sustain = 0;
  uint32_t previous_expression = 0;
  uint32_t previous_p1 = 0;
  uint32_t previous_p2 = 0;
  HysteresisFilter p1_filter, p2_filter;

  for (;;) {
    // Capture time and measures.
    auto t1 = measures_us[t1_id] = micros();
    auto &measures_t1 = measures[t1_id];
    adc_array.read(measures_t1);

    // Use the oldest available record as reference point.
    auto t0_id = t1_id = (t1_id + 1) % kMeasuresSize;

    const auto t0 = measures_us[t0_id];
    const auto &measures_t0 = measures[t0_id];

    // The oldest value is also the next to write to.
    t1_id = t0_id;

    for (int i = 0; i < measures_t1.size(); i++) {
      if (measures_t1[i] > kPressThreshold && !isPressed[i]) {
        isPressed[i] = true;

        float derivate = 1000.f * (measures_t1[i] - measures_t0[i]) / (t1 - t0);
        // Clamp the derivative.
        derivate = min(max(derivate, min(kMinVelocity, kMaxVelocity)),
                       max(kMinVelocity, kMaxVelocity));
        // Compute the velocity from 1 to 127.
        const int32_t velocity = 1. + (derivate - kMinVelocity) /
                                          (kMaxVelocity - kMinVelocity) * 126.;

        // Send Note On for current position at full velocity (127) on
        // channel 1.
        uint8_t channel = kMidiChannel + keyboard_channel[i];
        MIDI.sendNoteOn(keyboard_mapping[1][i], velocity, channel);
        if (kPrintKey) {
          Serial.print(">>> Key ");
          Serial.print(i);
          Serial.print(" mapping: ");
          Serial.print(keyboard_mapping[1][i]);
          Serial.print("=");
          printNoteName(keyboard_mapping[1][i]);
          Serial.print(" channel: ");
          Serial.print(channel);
          Serial.print(" derivate: ");
          Serial.print(derivate);
          Serial.print(" velocity: ");
          Serial.print(velocity);
          Serial.print(", measures: ");
          Serial.print(measures_t1[i]);
          Serial.print(" -> ");
          Serial.print(measures_t0[i]);
          Serial.print(" delta:");
          Serial.print((static_cast<float>(measures_t1[i]) - measures_t0[i]));
          Serial.println();
        }
      } else if (measures_t1[i] < kReleaseThreshold && isPressed[i]) {
        isPressed[i] = false;

        // Send Note Off for previous note.
        MIDI.sendNoteOff(keyboard_mapping[1][i], 0,
                         kMidiChannel + keyboard_channel[i]);
        if (kPrintKey) {
          Serial.print(">>> Key ");
          Serial.print(i);
          Serial.println(" released.");
        }
      }
    }

    Devices::Value device_values;
    devices.read(device_values);

    const uint32_t bend = y_axis_mapper.remap(device_values.joy_y);
    if (bend != previous_bend) {
      MIDI.send(midi::MidiType::PitchBend, 0, bend, kMidiChannel);
      MIDI.send(midi::MidiType::PitchBend, 0, bend, kMidiChannel + 1);
      previous_bend = bend;
      if (kPrintMidiEvents) {
        Serial.print("joy: ");
        Serial.print(device_values.joy_y);
        Serial.print(" bend:");
        Serial.println(bend);
      }
    }

    const uint32_t expression =
        expression_mapper.remap(device_values.expression_pedal);
    if (expression != previous_expression) {
      MIDI.send(midi::MidiType::ControlChange, 1, expression, kMidiChannel);
      MIDI.send(midi::MidiType::ControlChange, 1, expression, kMidiChannel+1);
      previous_expression = expression;
    }

    if (device_values.sustain_pedal != previous_sustain) {
      MIDI.send(midi::MidiType::ControlChange, 64,
                device_values.sustain_pedal ? 0 : 127, kMidiChannel);
      MIDI.send(midi::MidiType::ControlChange, 64,
                device_values.sustain_pedal ? 0 : 127, kMidiChannel + 1);
      previous_sustain = device_values.sustain_pedal;
    }

    const uint32_t p1 = p1_mapper.remap(p1_filter.apply(device_values.p1));
    if (p1 != previous_p1) {      
      MIDI.send(midi::MidiType::ControlChange, 12, p1, kMidiChannel);
      MIDI.send(midi::MidiType::ControlChange, 12, p1, kMidiChannel + 1);
      previous_p1 = p1;
      if (kPrintMidiEvents) {
        Serial.print("device_values.p1: ");
        Serial.print(device_values.p1);
        Serial.print(" p1: ");
        Serial.print(p1);
        Serial.println();
      }
    }

    const uint32_t p2 = p2_mapper.remap(p2_filter.apply(device_values.p2));
    if (p2 != previous_p2) {
      MIDI.send(midi::MidiType::ControlChange, 13, p2, kMidiChannel);
      MIDI.send(midi::MidiType::ControlChange, 13, p2, kMidiChannel + 1);
      previous_p2 = p2;
      if (kPrintMidiEvents) {
        Serial.print("device_values.p2: ");
        Serial.print(device_values.p2);
        Serial.print(" p2: ");
        Serial.print(p2);
        Serial.println();
      }
    }
    // Let the USB stack opeate if needed.
    yield();
    if (heartbit.tick()) {
      //device_values.print();
      // printKeyboardState(measures_t1);
    }
  }
}

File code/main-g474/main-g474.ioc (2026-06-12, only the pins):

Mcu.UserName=STM32G474CBTx
PA0.GPIO_Label=EXP_PEDAL
PA0.Signal=ADC1_IN1
PA1.GPIO_Label=SUS_PEDAL
PA1.Signal=ADC2_IN2
PA10.Signal=USART1_RX
PA11.GPIO_Label=USB_DM
PA11.Signal=USB_DM
PA12.GPIO_Label=USB_DP
PA12.Signal=USB_DP
PA13.Signal=SYS_JTMS-SWDIO
PA14.Signal=SYS_JTCK-SWCLK
PA15.GPIO_Label=PGM_DETECT
PA15.Signal=GPIO_Input
PA2.GPIO_Label=HALL_NEN
PA2.Signal=GPIO_Output
PA3.GPIO_Label=L_BOOT0
PA3.Signal=GPIO_Output
PA4.GPIO_Label=L_SPI_NSS
PA4.Signal=SPI1_NSS
PA5.GPIO_Label=L_SPI_SCK
PA5.Signal=SPI1_SCK
PA6.GPIO_Label=L_SPI_MISO
PA6.Signal=SPI1_MISO
PA7.GPIO_Label=L_SPI_MOSI
PA7.Signal=SPI1_MOSI
PA8.GPIO_Label=R_READY
PA8.Signal=GPIO_Input
PA9.Signal=USART1_TX
PB0.GPIO_Label=L_READY
PB0.Signal=GPIO_Input
PB1.GPIO_Label=HALL0
PB1.Signal=ADC3_IN1
PB11.GPIO_Label=R_NRST
PB11.Signal=GPIO_Output
PB12.GPIO_Label=HALL1
PB12.Signal=ADC4_IN3
PB13.GPIO_Label=R_BOOT0
PB13.Signal=GPIO_Output
PB14.GPIO_Label=R_SPI_MISO
PB14.Signal=SPI2_MISO
PB15.GPIO_Label=R_SPI_MOSI
PB15.Signal=SPI2_MOSI
PB2.GPIO_Label=L_NRST
PB2.Signal=GPIO_Output
PB3.Signal=SYS_JTDO-SWO
PB4.GPIO_Label=SW_FN2
PB4.Signal=GPIO_Input
PB5.GPIO_Label=LED_FN2
PB5.Signal=GPIO_Output
PB6.GPIO_Label=SW_FN1
PB6.Signal=GPIO_Input
PB7.GPIO_Label=LED_FN1
PB7.Signal=GPIO_Output
PB8-BOOT0.GPIO_Label=SW_FN0_BOOT0
PB8-BOOT0.Signal=GPIO_Input
PB9.GPIO_Label=LED_FN0
PB9.Signal=GPIO_Output
PC14-OSC32_IN.GPIO_Label=EXP_PEDAL_INT
PC14-OSC32_IN.Signal=GPIO_Input
PC15-OSC32_OUT.GPIO_Label=SUS_PEDAL_INT
PC15-OSC32_OUT.Signal=GPIO_Input
PF0-OSC_IN.GPIO_Label=R_SPI_NSS
PF0-OSC_IN.Signal=SPI2_NSS
PF1-OSC_OUT.GPIO_Label=R_SPI_SCK
PF1-OSC_OUT.Signal=SPI2_SCK

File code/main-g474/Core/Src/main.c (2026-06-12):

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
/* Includes ------------------------------------------------------------------*/
#include "main.h"

/* USER CODE BEGIN Includes */
#include <stdio.h>
#include <stdlib.h>
#include <string.h>
#include "console.h"
#include "usb_app.h"
#include "spi_link.h"
#include "keyboard/keyboard_layout.h"

/* USER CODE END Includes */

ADC_HandleTypeDef hadc1;
ADC_HandleTypeDef hadc2;
ADC_HandleTypeDef hadc3;
ADC_HandleTypeDef hadc4;

SPI_HandleTypeDef hspi1;
SPI_HandleTypeDef hspi2;
DMA_HandleTypeDef hdma_spi1_rx;
DMA_HandleTypeDef hdma_spi2_rx;

UART_HandleTypeDef huart1;

PCD_HandleTypeDef hpcd_USB_FS;

void SystemClock_Config(void);
static void MX_GPIO_Init(void);
static void MX_DMA_Init(void);
static void MX_ADC1_Init(void);
static void MX_ADC2_Init(void);
static void MX_ADC3_Init(void);
static void MX_ADC4_Init(void);
static void MX_SPI1_Init(void);
static void MX_SPI2_Init(void);
static void MX_USART1_UART_Init(void);
static void MX_USB_PCD_Init(void);
/* USER CODE BEGIN 0 */

static void delay_us(uint32_t us)
{
  uint32_t cycles = us * (SystemCoreClock / 1000000U);
  uint32_t start = DWT->CYCCNT;
  while ((DWT->CYCCNT - start) < cycles);
}

/* Sends a string over SWO ITM port 0; no-op if no debugger has enabled tracing */
static void swo_print(const char *s)
{
  while (*s)
  {
    if ((ITM->TCR & ITM_TCR_ITMENA_Msk) && (ITM->TER & (1UL << 0)))
    {
      while (ITM->PORT[0].u32 == 0);
      ITM->PORT[0].u8 = (uint8_t)*s;
    }
    s++;
  }
}

/* ===== Wing keyboard link (SPI slave) ===================================== *
 * Each wing streams a fixed SPI_LINK_FRAME_WORDS frame (see spi_link.h): word
 * 0 is the wing id, words 1.. are the raw hall measurement per key. SPI1 is
 * wired to the left wing, SPI2 to the right (L_SPI_ / R_SPI_ pins), but the
 * wing id in the frame is authoritative for note mapping. Reception is
 * DMA-driven (interrupt fallback), re-armed from the main loop on the NSS idle
 * gap (the only point that word-aligns); bad (CRC/overrun/misaligned) frames
 * are dropped and counted. */

/* Press/release hysteresis: a hall reading falls as a key is pressed and rises
 * back as it is released. release_threshold > press_threshold gives a dead band
 * so a key resting near the trip point doesn't chatter. */
#define KEYBOARD_PRESS_THRESHOLD   1900
#define KEYBOARD_RELEASE_THRESHOLD 2100

/* The bandoneon is bisonoric: each key sounds a different note on push vs pull.
 * g_bellows holds that direction and g_bellow_intensity (0..1024) how hard the
 * bellows is being pushed or pulled; both are derived from the combined hall
 * reading (hall0+hall1) by bellows_update() in the main loop. */
static bellows_t g_bellows = BELLOWS_NEUTRAL;
static uint16_t g_bellow_intensity = 0;

/* Combined-hall calibration: center is the at-rest reading, hard push/pull
 * the readings at full travel. The deadzone sets how far from center the
 * bellows must move to leave BELLOWS_NEUTRAL (no air moves there, so
 * note_table maps every key to NOTE_NONE). The hysteresis margin then has to
 * be given back before returning to NEUTRAL, so a bellows resting right at
 * the deadzone edge doesn't chatter between NEUTRAL and PUSH/PULL. */
#define BELLOWS_CENTER     3775
#define BELLOWS_DEADZONE   40
#define BELLOWS_HYSTERESIS 20
#define BELLOWS_HARD_PUSH  3400
#define BELLOWS_HARD_PULL  4200

/* Updates g_bellows/g_bellow_intensity from the combined hall reading.
 * In NEUTRAL, intensity is 0 and direction holds until the reading passes the
 * deadzone edge. In PUSH/PULL, intensity scales linearly from the deadzone
 * edge to the hard push/pull reading (clamped to 1024: 0 is barely moving
 * air, 1024 is full force), and direction holds until the reading comes back
 * past the deadzone edge by BELLOWS_HYSTERESIS. */
static void bellows_update(uint32_t hall_total)
{
  uint32_t push_edge = BELLOWS_CENTER - BELLOWS_DEADZONE;
  uint32_t pull_edge = BELLOWS_CENTER + BELLOWS_DEADZONE;

  switch (g_bellows)
  {
    case BELLOWS_PUSH:
      if (hall_total >= push_edge + BELLOWS_HYSTERESIS) g_bellows = BELLOWS_NEUTRAL;
      break;
    case BELLOWS_PULL:
      if (hall_total <= pull_edge - BELLOWS_HYSTERESIS) g_bellows = BELLOWS_NEUTRAL;
      break;
    default:
      if (hall_total < push_edge) g_bellows = BELLOWS_PUSH;
      else if (hall_total > pull_edge) g_bellows = BELLOWS_PULL;
      break;
  }

  if (g_bellows == BELLOWS_PUSH)
  {
    uint32_t span = push_edge - BELLOWS_HARD_PUSH;
    uint32_t d = hall_total < push_edge ? push_edge - hall_total : 0;
    g_bellow_intensity = (uint16_t)(d >= span ? 1024 : (d * 1024) / span);
  }
  else if (g_bellows == BELLOWS_PULL)
  {
    uint32_t span = BELLOWS_HARD_PULL - pull_edge;
    uint32_t d = hall_total > pull_edge ? hall_total - pull_edge : 0;
    g_bellow_intensity = (uint16_t)(d >= span ? 1024 : (d * 1024) / span);
  }
  else
  {
    g_bellow_intensity = 0;
  }
}

/* CC#11 (Expression) hysteresis, in the same 0..1024 units as
 * g_bellow_intensity: only resent once intensity has moved by at least this
 * much, so sensor noise doesn't flood the link with near-identical CCs. */
#define BELLOWS_CC_HYSTERESIS 64

/* Caps how often CC#11 is sent, independent of the hysteresis check, so a
 * fast-moving bellows can't flood the link beyond what a host needs. */
#define BELLOWS_CC_PERIOD_MS (1000 / 100) /* 100 Hz */

/* Sends CC#11 (Expression) from g_bellow_intensity, scaled to 0..127, when it
 * has moved by at least BELLOWS_CC_HYSTERESIS since the last send (or on the
 * first call) and at most every BELLOWS_CC_PERIOD_MS. Call once per main loop
 * iteration after bellows_update(). */
static void bellows_send_cc(void)
{
  static uint16_t last_intensity;
  static uint8_t have_last;
  static uint32_t last_tick;

  uint32_t now = HAL_GetTick();
  if (have_last && (now - last_tick) < BELLOWS_CC_PERIOD_MS) return;

  uint16_t intensity = g_bellow_intensity;
  uint16_t delta = intensity > last_intensity ? intensity - last_intensity : last_intensity - intensity;
  if (!have_last || delta >= BELLOWS_CC_HYSTERESIS)
  {
    last_intensity = intensity;
    last_tick = now;
    have_last = 1;
    usb_app_midi_control_change(11, (uint8_t)((intensity * 127) / 1024));
  }
}
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

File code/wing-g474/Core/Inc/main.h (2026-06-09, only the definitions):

#define ID0_Pin GPIO_PIN_13
#define ID0_GPIO_Port GPIOC
#define SEL0_Pin GPIO_PIN_14
#define SEL0_GPIO_Port GPIOC
#define SEL1_Pin GPIO_PIN_15
#define SEL1_GPIO_Port GPIOC
#define ID1_Pin GPIO_PIN_0
#define ID1_GPIO_Port GPIOF
#define ID2_Pin GPIO_PIN_1
#define ID2_GPIO_Port GPIOF
#define A_IN0_Pin GPIO_PIN_0
#define A_IN0_GPIO_Port GPIOA
#define A_IN1_Pin GPIO_PIN_1
#define A_IN1_GPIO_Port GPIOA
#define SPI_NSS_Pin GPIO_PIN_4
#define SPI_NSS_GPIO_Port GPIOA
#define SPI_SCK_Pin GPIO_PIN_5
#define SPI_SCK_GPIO_Port GPIOA
#define A_IN2_Pin GPIO_PIN_6
#define A_IN2_GPIO_Port GPIOA
#define A_IN3_Pin GPIO_PIN_7
#define A_IN3_GPIO_Port GPIOA
#define A_IN4_Pin GPIO_PIN_0
#define A_IN4_GPIO_Port GPIOB
#define A_IN5_Pin GPIO_PIN_1
#define A_IN5_GPIO_Port GPIOB
#define HALL_NEN_Pin GPIO_PIN_11
#define HALL_NEN_GPIO_Port GPIOB
#define LED_FN0_Pin GPIO_PIN_12
#define LED_FN0_GPIO_Port GPIOB
#define SW_FN0_Pin GPIO_PIN_13
#define SW_FN0_GPIO_Port GPIOB
#define A_IN9_Pin GPIO_PIN_14
#define A_IN9_GPIO_Port GPIOB
#define A_IN8_Pin GPIO_PIN_15
#define A_IN8_GPIO_Port GPIOB
#define A_IN7_Pin GPIO_PIN_8
#define A_IN7_GPIO_Port GPIOA
#define A_IN6_Pin GPIO_PIN_9
#define A_IN6_GPIO_Port GPIOA
#define PGM_USART_RX_Pin GPIO_PIN_10
#define PGM_USART_RX_GPIO_Port GPIOA
#define PGM_DETECT_Pin GPIO_PIN_15
#define PGM_DETECT_GPIO_Port GPIOA
#define SPI_MISO_Pin GPIO_PIN_4
#define SPI_MISO_GPIO_Port GPIOB
#define SPI_MOSI_Pin GPIO_PIN_5
#define SPI_MOSI_GPIO_Port GPIOB
#define PGM_USART_TX_Pin GPIO_PIN_6
#define PGM_USART_TX_GPIO_Port GPIOB
#define READY_Pin GPIO_PIN_7
#define READY_GPIO_Port GPIOB
#define BOOT0_Pin GPIO_PIN_8
#define BOOT0_GPIO_Port GPIOB

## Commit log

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2024-01-30 Add boards
    [bandoneon.kicad_pcb, bandoneon.kicad_sch, grape.kicad_sch]
2024-01-31 Design the board layout in kicad
    [bandoneon_facu.kicad_pcb]
2024-01-31 Design a cap
    [Cap.stl]
2024-01-31 Update positionning pins spacing to .4 in
    [bandoneon_facu.kicad_pcb]
2024-02-04 Add key caps with various inner size
    [Cap-v1.stl, Cap-v2-cylinder-42.stl, Cap-v2-cylinder-45.stl]
2024-02-04 Remove pcb copy
    [bandoneon.kicad_pcb, bandoneon_facu.kicad_pcb]
2024-02-04 Use keyboard layout and set images DPI
    [bandoneon.kicad_pcb, bandoneon.kicad_sch, bandoneon.step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]
2024-02-10 Schamtic complete
    [bandoneon.kicad_pcb, bandoneon.kicad_sch, bandoneon.step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]
2024-02-10 Fix component side
    [bandoneon.kicad_pcb, bandoneon.kicad_sch, grape.kicad_sch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]
2024-02-15 Printing carter attempt.
    [Bottom L.stl, Bottom.stl, Top L.stl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]
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2024-02-16 Add cap v2
    [Cap2-v3.stl]
2024-02-26 Add 1cm between two keyboards and ready for print test.
    [Bottom L.stl, Bottom.stl, Left Handle.stl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]
2024-02-26 Add strap screws
    [Bottom L.stl, Bottom.stl, Left Handle.stl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]
2024-02-26 Addjust holes with various sizes
    [Top L.stl]
2024-02-26 Larger Joystick hole
    [Top L.stl]
2024-03-01 Adjust caps
    [Cap.stl]
2024-03-01 Adjust joystick and model jack
    [bandoneon.kicad_pcb]
2024-03-07 Schema before wiring
    [bandoneon.kicad_pcb, bandoneon.kicad_sch, bandoneon.step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]
2024-03-08 PCB Check clear
    [bandoneon.kicad_pcb]
2024-03-08 Ready for routing
    [bandoneon.kicad_pcb, grape.kicad_sch, grape_alt.kicad_sch]
2024-03-10 Manual routing
    [bandoneon.kicad_sch, bandoneon_auto.kicad_pcb, bandoneon_manual.kicad_pcb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]
2024-03-10 Fix refs before autoroute
    [freerouting.dsn, temp-freerouting.dsn]
2024-03-10 Add models and ground plane
    [grape.kicad_sch, grape_alt.kicad_sch]
2024-03-11 Complete manual wire
    [bandoneon.kicad_pcb, grape.kicad_sch, grape_alt.kicad_sch]
2024-03-11 Import back enforce
    [bandoneon.kicad_pcb, bandoneon.step, carter.dxf]
2024-03-14 Wiring fixed
    [bandoneon.kicad_pcb, bandoneon.kicad_sch, grape.kicad_sch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]
2024-03-14 Ready for review
    [bandoneon.kicad_pcb, bandoneon_auto.kicad_pcb, bandoneon_manual.kicad_pcb]
2024-03-16 More models.
    [Bottom L.stl, Bottom R.stl, Cap-v1.stl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]
2024-03-17 Add esd protection
    [bandoneon.kicad_pcb, bandoneon.kicad_sch, grape.kicad_sch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]
2024-03-18 Ready for print
    [Cap-v2-cylinder-415.stl, carter-split.step]
2024-03-18 Add screw and glue surface
    [carter v59.step]
2024-03-18 More glue surface.
    [Bottom L.stl, Bottom R.stl, Bottom.stl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]
2024-03-26 Before setting up the bom + pick and place
    [bandoneon.kicad_pcb]
2024-03-27 Gerber and bom export
    [bandoneon-B_Cu.gbl, bandoneon-B_Mask.gbs, bandoneon-B_Paste.gbp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]
2024-03-28 Ready for fabrication
    [bandoneon-B_Cu.gbl, bandoneon-B_Mask.gbs, bandoneon-B_Paste.gbp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]
2024-03-30 PCB order
    [bandoneon-B_Cu.gbl, bandoneon-B_Mask.gbs, bandoneon-B_Paste.gbp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]
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2024-04-07 Fix jack footprint and wiring.
    [bandoneon.kicad_pcb]
2024-04-07 Fix support and add pockets for pins
    [Bottom L.stl, Bottom R.stl]
2024-04-19 Remove step.
    [carter v51.step, carter v59.step, carter v62.step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]
2024-04-28 3dprint unsplit
    [Bottom L.stl, Bottom R.stl, Top L.stl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]
2024-04-30 Give up printing as a single part.
    [Bottom L.stl, Bottom R.stl, Handle L.stl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]
2024-05-20 Annotate TRS.
    [bandoneon.kicad_pcb]
2024-05-22 Fix potentimeter glitchm and add neopixel support
    [01-25-instrument.ino]
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2025-09-11 Grid paper is now aliased on printer dotmatrix.
    Now thinlines are rendered correctly on Bother lazer printer.
    The scaling with `lpr -o raw` print command is correct on the short edge
    but slightly stretched (150.6 mm for 150.0 mm) on the long edge.
    Also the pattern is not centered anymore for simplification.
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2025-09-22 [pcb] Fix hall sensor count
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2025-10-07 [pcb] Both wings wired with no DRC error.
2025-10-08 [pcb] Improved naming, fixed led resistor.
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2025-12-29 Enable USB hardware without middleware.
    Also fixed clock issues with automatic resolution.
    Also updated SWO frequency.
    [main.c]
2025-12-29 Add TinyUSB Integration with STM32HAL.
    For TinyUSB only include the portable/st/stm32_fsdev
    The list can be found in the bsp cmakefile.
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2025-12-30 Enable USB on WBA board configuration.
    For STM32WBA65, open the `.ioc` file and then:
    1. Go to `System Core` > `GPIO` (also known as `General Input Output`), select
    tab `RCC` (`Reset and Clock Control`)
    2. Bind pin `OSC_IN` to signal `RCC_OSC_IN` and `OSC_OUT` to `RCC_OSC_OUT`.
    3. Go to `Connectivity` > `USB_OTG_HS` (OTG means Over The Go which indicates
    the processor can either be a device or a host, and HS means Hish Speed which
    indicates the fastest communication speed capability). If OSC pins are
    correctly binded it should no longer be greyed out (disabled).
    4. Set `Internal HS Phy` to `Device_Only` and in the `Parameter Settings` > `OTG
    PHY reference clock selection` set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
    [main.c]
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2026-04-17 Better TSD protection
    [BOM_MainBoard_MotherBoard_2026-04-14.csv, BOM_WingLeft_WingLeft_2026-04-14.csv, BOM_WingRight_WingRight_2026-04-14.csv]
2026-04-20 ESD review done
    [BOM_MainBoard_MainBoard.csv, BOM_MainBoard_MotherBoard_2026-04-14.csv, BOM_WingLeft_WingLeft.csv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]
2026-04-20 Fix hal switch migration
    [BOM_MainBoard_MainBoard.csv, BOM_WingLeft_WingLeft.csv, BOM_WingRight_WingRight.csv]
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2026-04-20 Create fn buttons.
    [BOM_MainBoard_MainBoard.csv]
2026-04-20 main board review
    [BOM_MainBoard_MainBoard.csv]
2026-04-21 Add shortcut protection to the bandoneo wing ports.
    [BOM_WingLeft_WingLeft.csv]
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2026-04-22 Same Left and right wing schema.
    [BOM_MainBoard_MainBoard.csv, BOM_WingLeft_WingLeft.csv, BOM_WingRight_WingRight.csv]
2026-04-22 Complete hall sensord migration
    [BOM_WingLeft_WingLeft.csv, BOM_WingRight_WingRight.csv]
2026-04-22 Prevent backfeeding with buffers.
    [BOM_MainBoard_MainBoard.csv]
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2026-05-04 Prepare centring hall sensors
    [PickAndPlace_WingLeft.csv, PickAndPlace_WingRight.csv]
2026-05-04 Fixed hall sensor placement
    [PickAndPlace_WingLeft.csv, PickAndPlace_WingRight.csv]
2026-05-04 Fix main hall footprint
2026-05-04 Fix DRC and make pinout consistent.
    [BOM_MainBoard_MainBoard.csv, BOM_WingLeft_WingLeft.csv, BOM_WingRight_WingRight.csv]
2026-05-05 Layout mainboard switches
    [BOM_MainBoard_MainBoard.csv]
2026-05-05 Layout power
    [BOM_MainBoard_MainBoard.csv]
2026-05-19 Update schmatics with not batteries
    [BOM_MainBoard_MainBoard.csv, BOM_WingLeft_WingLeft.csv, BOM_WingRight_WingRight.csv]
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2026-05-26 Rewire left board
    [BOM_MainBoard_MainBoard.csv]
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2026-05-28 main board ready
    [BOM_MainBoard_MainBoard.csv, BOM_WingLeft_WingLeft.csv, BOM_WingRight_WingRight.csv]
2026-05-29 Wiring readay for final review
    [BOM_MainBoard_MainBoard.csv, BOM_WingLeft_WingLeft.csv, BOM_WingRight_WingRight.csv]
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2026-06-01 Fix left wing perimeter to be horizontal.
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2026-06-09 Fix SWO tracing with STLINK-V3.
    [main.c]
2026-06-09 Add reset and trace_swo just commands
2026-06-09 Board: Fix function leds inverted polarity.
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2026-06-09 Set HALL_NEN as open drain and generate code.
    There is a pull up resistor on the board that just needs
    to be shorted to ground.
    [main-g474.ioc, main.c]
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2026-06-09 Add a safety for flashing boards.
    A listing associates MCU id to a board type to
    prevent flashing the wrong board image which could
    cause troubles with GPIO.
    [boards.csv]
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2026-06-10 Add `just release` command to flash opt code.
    It inits builds and flash optimised code which
    goes 2.3 x faster on adc sampling.
2026-06-10 Fix VCC rail tracks dimensions.
2026-06-11 Now wings are masters and main is slave.
    Also add a test for consistency checkgin for SPI definitions.
    [boards.csv]
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2026-06-12 Implement keyboard mapping.
    [boards.csv]
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

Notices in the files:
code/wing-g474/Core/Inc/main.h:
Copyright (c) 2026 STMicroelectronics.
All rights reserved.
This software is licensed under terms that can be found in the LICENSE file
